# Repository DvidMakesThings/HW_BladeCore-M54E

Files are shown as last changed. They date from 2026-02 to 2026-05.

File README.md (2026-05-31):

# BladeCore‑M54E

BladeCore‑M54E is part of the **BladeCore** modular controller series.  
Each BladeCore variant is implemented as a standalone hardware repository, sharing a common architectural philosophy while targeting different microcontrollers and interfaces.

This repository documents the **BladeCore‑M54E** hardware, which is based on the **RP2354B** microcontroller and integrates **Ethernet connectivity**.

## BladeCore Series Overview

The BladeCore series consists of the following hardware variants:

| Module | Microcontroller | Primary Interface | Form Factor | Status |
|---|---|---|---|---|
| [BladeCore‑M40](#)  | RP2040  | — | - | Work in progress |
| [BladeCore‑M40E](#) | RP2040  | Ethernet | - | Work in progress |
| [BladeCore‑M40C](#) | RP2040  | CAN | - | Work in progress |
| [BladeCore‑M54](#)  | RP2354B | — | - | Work in progress |
| [BladeCore‑M54E](https://github.com/DvidMakesThings/HW_BladeCore-M54E) | RP2354B | Ethernet | 2980 | Available |
| [BladeCore‑M54C](https://github.com/DvidMakesThings/HW_BladeCore-M54C) | RP2354B | CAN | 2980 | Available |

### Naming Scheme Explanation

The BladeCore naming scheme encodes the **microcontroller family** and **primary communication interface** directly in the module name:

- **M40** designates an RP2040‑based module  
- **M54** designates an RP2354B‑based module  
- **E** suffix indicates integrated Ethernet support  
- **C** suffix indicates integrated CAN support  

Variants without a suffix represent the **base module** for that microcontroller family, without Ethernet or CAN integrated.

Each BladeCore variant is implemented as a **separate hardware design and repository**.

## Description

BladeCore‑M54E is a compact controller module built around the **RP2354B** microcontroller, combined with a **W5500 Ethernet controller with integrated PHY**.  
The module is designed as a **2980‑size M.2 M‑Key card** (29 mm wide, 80 mm long, non‑standard width), intended to be embedded into a carrier board or system that provides power through the M.2 edge connector.

The design integrates:

*   RP2354B microcontroller
*   External QSPI flash memory
*   External I²C EEPROM
*   100BASE Ethernet via W5500
*   Dual‑path USB connectivity with automatic source selection
*   Onboard power regulation and defined power‑up sequencing

This repository contains the schematics and documentation.

- [BladeCore‑M54 schematics (PDF)](src/PDF/BladeCore-M54E_Schematics.pdf).
- [BladeCore‑M54 KiCad folder](src/HardwareDesign/1.0.0/).

### Resources

- **KiCad Libraries:** [src/HardwareDesign/Libraries/KiCad](src/HardwareDesign/Libraries/KiCad)
    - BladeCore‑M54E footprint 
    - BladeCore‑M54E symbol
    - Plain M.2 connector footprint (MDT420E03001)
    - 3D STEP: BladeCore‑M54E + MDT420E03001 assembly
    - 3D STEP: M.2 connector
- **Eagle Libraries:** [src/HardwareDesign/Libraries/Eagle](src/HardwareDesign/Libraries/Eagle)
    - Status: Work in progress

## Hardware Overview

<table>
    <tr>
        <td align="center">
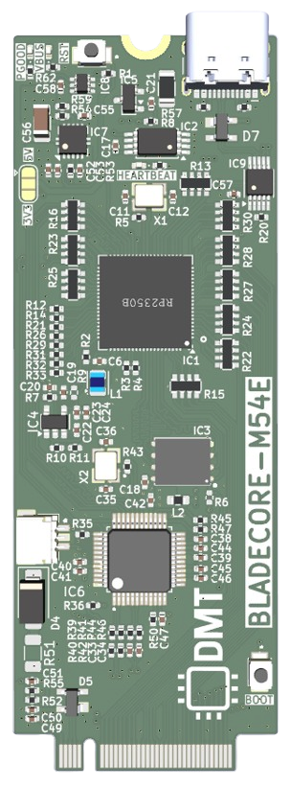
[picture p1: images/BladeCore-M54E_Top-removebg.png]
BladeCore‑M54E top view
            <br><em>Top view</em>
        </td>
        <td align="center">
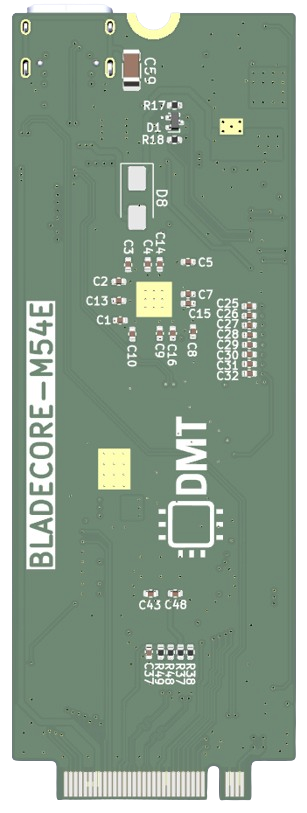
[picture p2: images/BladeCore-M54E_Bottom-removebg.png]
BladeCore‑M54E bottom view
            <br><em>Bottom view</em>
        </td>
    </tr>
 </table>

### Form Factor

*   **M.2 2980**
*   **M‑Key**
*   Power and I/O routed through the M.2 edge connector

### Microcontroller

*   **RP2354B**
*   External **12 MHz crystal**
*   Internal 1.1 V core supply generated by the MCU
*   SWD debug interface available
*   GPIOs routed to the M.2 edge connector

### Memory

*   **Integrated Flash**
    *   RP2354B
    *   Capacity: **2 MB**
*   **External QSPI Flash**
    *   W25Q128JVPIQ
    *   Capacity: **16 MB**
*   **External I²C EEPROM**
    *   AT24C256
    *   Capacity: **256 kbit**

***

### Ethernet

*   **W5500 Ethernet Controller with integrated PHY**
*   Interface to MCU via **SPI**
*   Supports **100BASE‑TX**
*   Dedicated reset and interrupt signals
*   Link and activity LEDs implemented

### USB

BladeCore‑M54E supports **two physical USB connection paths**:

1.  **USB routed through the M.2 edge connector** (external host or carrier board USB), and
2.  **Onboard USB‑C connector**.

A **FSUSB42 USB 2.0 high‑speed multiplexer** is used to select which USB path is connected to the RP2354B.

**USB path selection behavior:**

*   By default, the USB data lines are routed to the **M.2 edge connector**.
*   When the **onboard USB‑C connector is plugged in**, the FSUSB42 automatically **redirects the USB data path** from the edge connector to the onboard USB‑C connector.
*   Removing the onboard USB connection restores the default routing to the M.2 edge connector.

This allows the module to be normally operated via a carrier board USB connection, while still enabling direct access through the onboard USB‑C connector when needed, without manual configuration.

### Power

*   Input supply: **5 V** (M.2 pins 14/16 or VBUS) or **3.3 V** (M.2 pins 10/12, LDO bypassed)
*   **TPS74801** low‑dropout regulator generating 3.3 V from 5 V input
*   Regulated 3.3 V output to carrier board on M.2 pins 10/12 (up to 1 A, limited by connector)
*   Power‑good signaling with visual feedback (LED via SN74LVC1G97 buffer)
*   USB VBUS sensing routed to ADC
*   Four power paths: M.2 5 V, M.2 VBUS, onboard USB‑C, or external 3.3 V

### M.2 Connector Pinout

#### Left Side (Odd Pins)

| Pin | Name | F0 | F1 | F2 | F3 | F4 | F5 | F6 | F7 | F8 | F9 |
|----:|---|----|----|----|----|----|----|----|----|----|----|
| 1 | GND | | | | | | | | | | |
| 3 | GPIO24 | SPI0 TX | UART1 RTS | I2C1 SCL | PWM3 B | SIO | PIO0 | PIO1 | PIO2 | | CLOCK GPOUT1 |
| 5 | GPIO23 | SPI0 TX | UART1 RTS | I2C1 SCL | PWM3 B | SIO | PIO0 | PIO1 | PIO2 | | CLOCK GPOUT1 |
| 7 | GPIO22 | SPI0 SCK | UART1 CTS | I2C1 SDA | PWM3 A | SIO | PIO0 | PIO1 | PIO2 | | CLOCK GPIN1 |
| 9 | GPIO21 | SPI0 CSn | UART1 RX | **I2C0 SCL | PWM2 B | SIO | PIO0 | PIO1 | PIO2 | | CLOCK GPOUT0 |
| 11 | GND | | | | | | | | | | |
| 13 | GPIO20 | SPI0 RX | UART1 TX | **I2C0 SDA | PWM2 A | SIO | PIO0 | PIO1 | PIO2 | | CLOCK GPIN0 |
| 15 | GPIO19 | SPI0 TX | UART0 RTS | I2C1 SCL | PWM1 B | SIO | PIO0 | PIO1 | PIO2 | | QMI CS1n |
| 17 | GPIO18 | SPI0 SCK | UART0 CTS | I2C1 SDA | PWM1 A | SIO | PIO0 | PIO1 | PIO2 | | |
| 19 | GPIO17 | SPI0 CSn | UART0 RX | **I2C0 SCL | PWM0 B | SIO | PIO0 | PIO1 | PIO2 | | |
| 21 | GPIO16 | SPI0 RX | UART0 TX | **I2C0 SDA | PWM0 A | SIO | PIO0 | PIO1 | PIO2 | | |
| 23 | GND | | | | | | | | | | |
| 25 | GPIO15 | *SPI1 TX | UART0 RTS | I2C1 SCL | PWM7 B | SIO | PIO0 | PIO1 | PIO2 | | CLOCK GPOUT1 |
| 27 | GPIO14 | *SPI1 SCK | UART0 CTS | I2C1 SDA | PWM7 A | SIO | PIO0 | PIO1 | PIO2 | | CLOCK GPIN1 |
| 29 | GPIO13 | *SPI1 CSn | UART0 RX | **I2C0 SCL | PWM6 B | SIO | PIO0 | PIO1 | PIO2 | | CLOCK GPOUT0 |
| 31 | GPIO12 | *SPI1 RX | UART0 TX | **I2C0 SDA | PWM6 A | SIO | PIO0 | PIO1 | PIO2 | | CLOCK GPIN0 |
| 33 | GPIO11 | *SPI1 TX | UART1 RTS | I2C1 SCL | PWM5 B | SIO | PIO0 | PIO1 | PIO2 | | |
| 35 | GPIO10 | *SPI1 SCK | UART1 CTS | I2C1 SDA | PWM5 A | SIO | PIO0 | PIO1 | PIO2 | | |
| 37 | GPIO9 | *SPI1 CSn | UART1 RX | **I2C0 SCL | PWM4 B | SIO | PIO0 | PIO1 | PIO2 | | |
| 39 | GPIO8 | *SPI1 RX | UART1 TX | **I2C0 SDA | PWM4 A | SIO | PIO0 | PIO1 | PIO2 | | QMI CS1n |
| 41 | GND | | | | | | | | | | |
| 43 | GPIO7 | SPI0 TX | UART1 RTS | I2C1 SCL | PWM3 B | SIO | PIO0 | PIO1 | PIO2 | | |
| 45 | GPIO6 | SPI0 SCK | UART1 CTS | I2C1 SDA | PWM3 A | SIO | PIO0 | PIO1 | PIO2 | | |
| 47 | GPIO5 | SPI0 CSn | UART1 RX | **I2C0 SCL | PWM2 B | SIO | PIO0 | PIO1 | PIO2 | | |
| 49 | GPIO4 | SPI0 RX | UART1 TX | **I2C0 SDA | PWM2 A | SIO | PIO0 | PIO1 | PIO2 | | |
| 51 | GPIO3 | SPI0 TX | UART0 RTS | I2C1 SCL | PWM1 B | SIO | PIO0 | PIO1 | PIO2 | | |
| 53 | GPIO2 | SPI0 SCK | UART0 CTS | I2C1 SDA | PWM1 A | SIO | PIO0 | PIO1 | PIO2 | | |
| 55 | GPIO1 | SPI0 CSn | UART0 RX | **I2C0 SCL | PWM0 B | SIO | PIO0 | PIO1 | PIO2 | | TRACECLK |
| 57 | GPIO0 | SPI0 RX | UART0 TX | **I2C0 SDA | PWM0 A | SIO | PIO0 | PIO1 | PIO2 | | QMI CS1n |
| 67 | GND | | | | | | | | | | |
| 69 | USB_D+ | | | | | | | | | | |
| 71 | USB_D- | | | | | | | | | | |
| 73 | GND | | | | | | | | | | |
| 75 | VBUS | | | | | | | | | | |

#### Right Side (Even Pins)

| Pin | Name | F0 | F1 | F2 | F3 | F4 | F5 | F6 | F7 | F8 | F9 |
|----:|---|----|----|----|----|----|----|----|----|----|----|
| 2 | GND | | | | | | | | | | |
| 4 | GPIO27 | *SPI1 TX | UART1 RTS | I2C1 SCL | PWM5 B | SIO | PIO0 | PIO1 | PIO2 | | |
| 6 | GPIO26 | *SPI1 SCK | UART1 CTS | I2C1 SDA | PWM5 A | SIO | PIO0 | PIO1 | PIO2 | | |
| 8 | GPIO25 | *SPI1 CSn | UART1 RX | **I2C0 SCL | PWM4 B | SIO | PIO0 | PIO1 | PIO2 | | CLOCK GPOUT3 |
| 10 | +3.3V OUTPUT | | | | | | | | | | |
| 12 | +3.3V OUTPUT | | | | | | | | | | |
| 14 | +5V INPUT | | | | | | | | | | |
| 16 | +5V INPUT | | | | | | | | | | |
| 18 | LINKLED | | | | | | | | | | |
| 20 | ACTLED | | | | | | | | | | |
| 22 | GND | | | | | | | | | | |
| 24 | RCT | | | | | | | | | | |
| 26 | GND | | | | | | | | | | |
| 28 | ETH_RD+ | | | | | | | | | | |
| 30 | ETH_RD- | | | | | | | | | | |
| 32 | GND | | | | | | | | | | |
| 34 | ETH_TD+ | | | | | | | | | | |
| 36 | ETH_TD- | | | | | | | | | | |
| 38 | GND | | | | | | | | | | |
| 40 | TCT | | | | | | | | | | |
| 42 | GND | | | | | | | | | | |
| 44 | GND | | | | | | | | | | |
| 46 | ADC0/GPIO40 |  | *SPI1 RX | UART1 TX | **I2C0 SDA | PWM8 A | SIO | PIO0 | PIO1 | PIO2 |  |
| 48 | ADC1/GPIO41 |  | *SPI1 CSn | UART1 RX | **I2C0 SCL | PWM8 B | SIO | PIO0 | PIO1 | PIO2 |  |
| 50 | ADC2/GPIO42 |  | *SPI1 SCK | UART1 CTS | I2C1 SDA | PWM9 A | SIO | PIO0 | PIO1 | PIO2 |  |
| 52 | ADC3/GPIO43 |  | *SPI1 TX | UART1 RTS | I2C1 SCL | PWM9 B | SIO | PIO0 | PIO1 | PIO2 |  |
| 54 | ADC4/GPIO44 |  | *SPI1 RX | UART0 TX | **I2C0 SDA | PWM10 A | SIO | PIO0 | PIO1 | PIO2 |  |
| 56 | ADC5/GPIO45 |  | *SPI1 CSn | UART0 RX | **I2C0 SCL | PWM10 B | SIO | PIO0 | PIO1 | PIO2 |  |
| 58 | GND | | | | | | | | | | |
| 68 | GND | | | | | | | | | | |
| 70 | GND | | | | | | | | | | |
| 72 | VBUS | | | | | | | | | | |
| 74 | VBUS | | | | | | | | | | |
| SH1 | SHIELD | | | | | | | | | | |

*SPI1 is used for the onboard Ethernet controller (W5500)

**I2C0 is used for the onboard EEPROM (AT24C256) on GPIO32/33, which are internal to the module and not routed to the M.2 connector. Carrier board I2C0 on other GPIO pairs is physically independent.

## Revision History

| Revision | Date | Notes |
| --- | --- | --- |
| 1.0.0 | 2026‑01‑31 | Initial creation |

## Notes

*   This documentation intentionally avoids assumptions about firmware features, supported protocols, or software behavior.
*   All statements are derived from the provided schematics and explicit design notes.
*   Component‑level limits and behavior should be verified against the respective datasheets.

## License
### Hardware Components
Hardware designs, schematics, and related documentation are licensed under the **Creative Commons Attribution-NonCommercial-ShareAlike 4.0 International License (CC BY-NC-SA 4.0)**. See the [Hardware License](LICENSE-CC-BY-NC-SA) file for details.

#### What CC BY-NC-SA 4.0 means:

- ✅ **You can** study, modify, and distribute the hardware designs
- ✅ **You can** create derivative works for personal, educational, or non-commercial use
- ✅ **You can** build this project for your own personal use

- ⚠️ **You must** give appropriate credit and indicate if changes were made
- ⚠️ **You must** share any modifications under the same license terms
- ⚠️ **You must** include the original license and copyright notices

- ❌ **You cannot** use the designs for commercial purposes without explicit permission
- ❌ **You cannot** manufacture and sell products based on these designs without a commercial license
- ❌ **You cannot** create closed-source derivatives for commercial purposes
- ❌ **You cannot** use the designer's trademarks without permission

### Commercial & Enterprise Use

Commercial use of this project is prohibited without obtaining a separate commercial license. If you are interested in:

- Manufacturing and selling products based on these designs
- Incorporating these designs into commercial products
- Any other commercial applications

Please contact me through any of the channels listed in the [Contact](#contact) section to discuss commercial licensing arrangements. Commercial licenses are available with reasonable terms to support ongoing development.

## Contact

For questions or feedback:
- **Email:** [info@dmt-hw.com](mailto:info@dmt-hw.com)
- **GitHub:** [DvidMakesThings](https://github.com/DvidMakesThings)

## Contributing

Contributions are welcome! As this is an early-stage project, please reach out before 
making substantial changes:

1. Fork the repository
2. Create a feature branch (`git checkout -b feature/concept`)
3. Commit your changes (`git commit -m 'Add concept'`)
4. Push to the branch (`git push origin feature/concept`)
5. Open a Pull Request with a detailed description

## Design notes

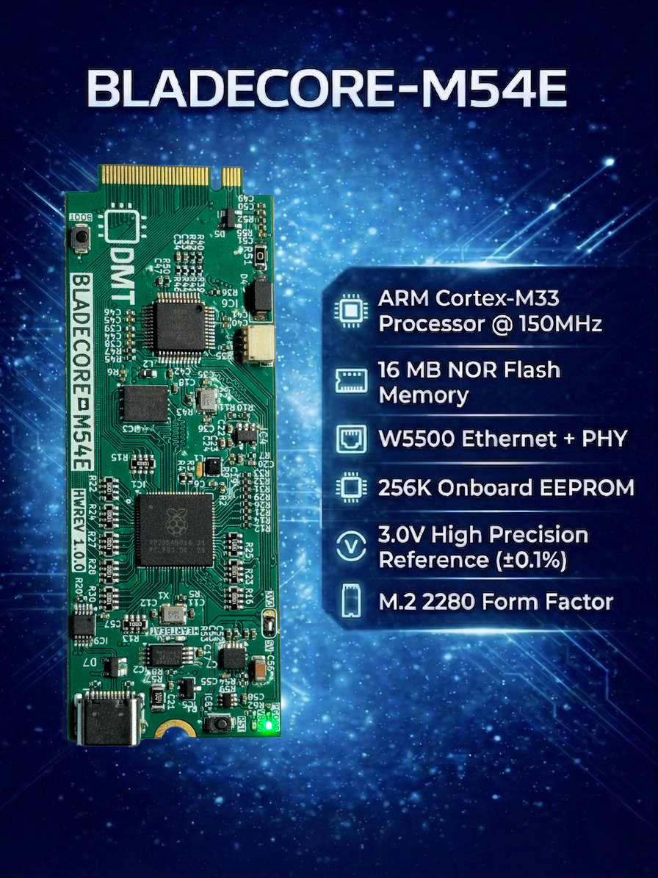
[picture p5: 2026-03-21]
images/M54E.png

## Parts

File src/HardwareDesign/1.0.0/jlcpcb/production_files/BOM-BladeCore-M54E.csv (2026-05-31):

Comment | Designator | Footprint | LCSC | Quantity
0R 1% | R40,R42 | R_0402_1005Metric | C17168 | 2
0R 1% | R51 | R_1206_3216Metric | C17888 | 1
1.5K/100MHz 0.5R | L2 | R_0603_1608Metric | C82155 | 1
100R 1% | R13,R15,R16,R22,R23,R24,R25,R27,R28,R30 | R_Array_Convex_4x0603 | C136838 | 10
100R 1% | R12,R14,R21,R26,R29,R31,R32,R33 | R_0402_1005Metric | C25076 | 8
100nF 50V | C1,C10,C13,C14,C15,C17,C18,C19,C2,C21,C23,C3,C37,C38,C4,C40,C41,C42,C43,C44,C45,C46,C47,C48,C5,C51,C52,C57,C58,C60,C7,C8,C9 | C_0402_1005Metric | C307331 | 33
10K 1% | R10,R11,R53 | R_0402_1005Metric | C25744 | 3
10pF 50V | C11,C12 | C_0402_1005Metric | C466222 | 2
10uF 50V | C56 | C_1206_3216Metric | C13585 | 1
12.4K 1% | R50 | R_0402_1005Metric | C490814 | 1
12MHz 10pF | X1 | X3225 | C2901649 | 1
15pF 50V | C35,C36 | C_0402_1005Metric | C1548 | 2
1K 1% | R34,R5,R58,R60,R61 | R_0402_1005Metric | C11702 | 5
1M 1% | R57 | R_1206_3216Metric | C17927 | 1
1M 1% | R43 | R_0402_1005Metric | C26083 | 1
1nF 2kV | C59 | C_1206_3216Metric | C173242 | 1
1nF 50V | C25,C26,C27,C28,C29,C30,C31,C32 | C_0402_1005Metric | C14442 | 8
1uF 50V | C53 | C_0402_1005Metric | C1518208 | 1
2.2K 1% | R17,R18 | R_0402_1005Metric | C25879 | 2
2.2nF 50V | C55 | C_0402_1005Metric | C106861 | 1
2.4K 1% | R59 | R_0402_1005Metric | C25882 | 1
25MHz 12pF | X2 | X3225 | C9006 | 1
27R 1% | R7 | R_0402_1005Metric | C138021 | 1
3.3R 1% | R39,R41,R44,R46 | R_0402_1005Metric | C270612 | 4
3.3uH 2.8A | L1 | 0805 | C42411119 | 1
33R 1% | R2,R3,R4 | R_0402_1005Metric | C25105 | 3
4.7K 1% | R1,R35,R8 | R_0402_1005Metric | C25900 | 3
4.7uF 10V | C20,C22,C24 | C_0402_1005Metric | C368809 | 3
4.7uF 25V | C16,C39,C49,C50,C54,C6 | C_0402_1005Metric | C22367824 | 6
470R 1% | R36,R45,R47 | R_0402_1005Metric | C25117 | 3
49.9R 1% | R37,R38,R48,R49 | R_0402_1005Metric | C25120 | 4
5.1K 1% | R19,R20,R52,R55,R56 | R_0402_1005Metric | C25905 | 5
6.8nF 50V | C33,C34 | C_0402_1005Metric | C1542 | 2
7.5K 1% | R54 | R_0402_1005Metric | C25918 | 1
AT24C256C-XHL-T | IC2 | TSSOP-8 | C33035 | 1
B3U-1000P | SW1,SW2 | SW_B3U-1000P | C231329 | 2
Blue | D3 | LED_0402_1005Metric | C22355736 | 1
FSUSB42MUX | IC9 | MSOP-10_3x3mm_P0.5mm | C11355 | 1
Green | D10,D11,D6 | LED_0402_1005Metric | C965793 | 3
LM4040B30FTA | IC5 | SOT-23 | C460604 | 1
MCP6001RT | IC4 | SOT-23-5 | C154973 | 1
RCLAMP0582BQTCT | D1 | SOT-416 | C841193 | 1
RP2354B | IC1 | QFN80_10x10 | C39843328 | 1
SM03B-SRSS-TB | J2 | JST_SM03B-SRSS-TB_LF__SN_ | C160403 | 1
SN74LVC1G97QDCKRQ1 | IC10,IC8 | SOT-363_SC-70-6 | C179911 | 2
SP0503BAHTG | D5,D7 | SOT143 | C3040626 | 2
TPS74801DRCT | IC7 | VSON-10-1EP_3x3mm_P0.5mm_EP1.65x2.4mm_ThermalVias | C882845 | 1
USB-TYPE-C-018 | J3 | USB_C_Receptacle_HCTL_HC-TYPE-C-16P-01A | C2927038 | 1
W25Q128JVPIQ | IC3 | WSON8_6x5 | C190862 | 1
W5500 | IC6 | LQFP48_7x7 | C32843 | 1
SS13 | D4 | D_SMA |  | 1
SS13 | D9 | D_SMA |  | 1
SS13 | D8 | D_SMA |  | 1

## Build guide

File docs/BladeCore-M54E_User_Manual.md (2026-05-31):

---
title: "BladeCore-M54E User Manual"
---

**Hardware Revision:** 1.0.0
**Date:** 2026-01-31
**Author:** DMT

## Table of Contents

1. [Introduction](#1-introduction)
2. [General Specifications](#2-general-specifications)
3. [Electrical Characteristics](#3-electrical-characteristics)
4. [Microcontroller](#4-microcontroller)
5. [Memory Subsystem](#5-memory-subsystem)
6. [Ethernet Interface](#6-ethernet-interface)
7. [USB Interface](#7-usb-interface)
8. [Power Management](#8-power-management)
9. [M.2 Connector Pinout](#9-m2-connector-pinout)
10. [Onboard Peripherals](#10-onboard-peripherals)
11. [Power-Up Sequencing](#11-power-up-sequencing)
12. [Getting Started -- Software](#12-getting-started----software)
13. [Programming Guide](#13-programming-guide)
14. [Code Examples](#14-code-examples)
15. [Design Considerations for Carrier Boards](#15-design-considerations-for-carrier-boards)
16. [Mechanical Specifications](#16-mechanical-specifications)
17. [Absolute Maximum Ratings](#17-absolute-maximum-ratings)
18. [Revision History](#18-revision-history)

## 1. Introduction

BladeCore-M54E is a compact, modular microcontroller card built around the **RP2354B**
(ARM Cortex-M33, dual-core) combined with a **W5500 Ethernet controller** with
integrated PHY.  The module uses an **M.2 2980 M-Key** form factor (29 mm wide,
80 mm long) with a standard M-Key edge connector at a non-standard board width,
making it suitable for embedding into carrier boards or systems that provide power
and I/O connectivity through the M.2 edge connector.

### Key Features

- RP2354B dual-core ARM Cortex-M33 microcontroller
- 2 MB integrated flash + 16 MB external QSPI flash
- 256 kbit external I2C EEPROM with 200+ year data retention
- 100BASE-TX Ethernet via W5500 (SPI-attached, hardware TCP/IP stack)
- Dual-path USB 2.0 with automatic source selection (M.2 + USB-C)
- 30 GPIO pins + 6 ADC channels routed to M.2 edge connector
- Onboard 3.3 V LDO with power-good signaling
- Defined power-up sequencing
- Onboard heartbeat LED (PWM-capable)
- SWD debug interface

### BladeCore Series

BladeCore-M54E belongs to the BladeCore modular controller series:

| Module | MCU | Primary Interface | 
|---|---|---|
| BladeCore-M40  | RP2040  | -- |
| BladeCore-M40E | RP2040  | Ethernet | 
| BladeCore-M40C | RP2040  | CAN |
| BladeCore-M54  | RP2354B | -- | 
| BladeCore-M54E | RP2354B | Ethernet | 
| BladeCore-M54C | RP2354B | CAN |

**Naming convention:** M40 = RP2040-based, M54 = RP2354B-based. Suffix E = Ethernet,
C = CAN, no suffix = base module.

## 2. General Specifications

| Parameter | Value |
|---|---|
| Microcontroller | RP2354B (ARM Cortex-M33, dual core) |
| Package | QFN-80-EP (10 x 10 mm) |
| System Clock | 150 MHz, overclock possible (Tested max is 200MHz) |
| External Crystal | 12 MHz, 10 pF load |
| Integrated Flash | 2 MB (internal to MCU) |
| External Flash (QSPI) | 16 MB (W25Q128JVPIQ, 133 MHz) |
| External EEPROM (I2C) | 256 kbit (AT24C256C, 400 kHz) |
| Ethernet | 100BASE-TX, W5500 (SPI, hardware TCP/IP) |
| USB | USB 2.0, dual path (M.2 + USB-C) |
| GPIO (M.2 connector) | 28 digital I/O pins |
| ADC Channels (M.2) | 6 channels (12-bit, GPIO40--GPIO45) |
| Onboard ADC Channels | 2 (VBUS sense, 3.0 V reference) |
| Operating Voltage (I/O) | 3.3 V |
| Form Factor | M.2 2980 M-Key |
| PCB Layers | 6 |

## 3. Electrical Characteristics

### 3.1 Recommended Operating Conditions

| Parameter | Symbol | Min | Typical | Max | Unit |
|---|---|---|---|---|---|
| Supply Voltage (5 V in)  | VIN | 4.75  | 5.0 | 5.5 | V |
| Supply Voltage (3.3 V) | VCC | 3.0 | 3.3 | 3.6 | V |
| USB VBUS Voltage | VBUS | 4.75  | 5.0 | 5.25  | V |
| Operating Temperature | TA | -20 | 25 | 70 | degC |
| I/O Logic Level (High) | VIH | 2.0 | -- | 3.3 | V |
| I/O Logic Level (Low) | VIL | 0 | -- | 0.8 | V |

### 3.2 RP2354B Core Parameters

| Parameter | Value |
|---|---|
| Core Voltage | 1.1 V (internal) |
| GPIO Output Drive | 2 / 4 / 8 / 12 mA  |
| GPIO Input Hysteresis | Schmitt trigger |
| Internal Pull-Up/Down Resistance | 50--80 kOhm |
| ADC Resolution | 12 bits |
| ADC Reference Voltage | 3.3 V (AVDD) |

### 3.3 Power Consumption (Typical)

| Condition | Current (3.3 V) | Notes |
|---|---|---|
| MCU idle, Ethernet off | ~15 mA | RP2354B in normal idle |
| MCU active, Ethernet off | ~40 mA | Both cores running |
| MCU active, Ethernet active | ~180 mA | W5500 in full operation |
| MCU dormant (sleep) | <1 mA | Deep sleep, all peripherals off |

> **Note:** The above values are approximate. Actual consumption depends on clock
> frequency, active peripherals, GPIO loading, and Ethernet traffic. Consult the
> RP2354B and W5500 datasheets for detailed characterization.

### 3.4 LDO Regulator (TPS74801)

| Parameter | Symbol | Min  | Typical | Max  | Unit |
|---|---|---|---|---|---|
| Input Voltage | VIN | 1.1  | 5.0 | 5.5  | V |
| Output Voltage | VOUT | -- | 3.3 | -- | V |
| Max Output Current | IOUT | -- | -- | 1.5  | A |
| Dropout Voltage | VDO | -- | 110 | 300  | mV |
| Output Voltage Accuracy| -- | -- | +/-1 | -- | % |
| Thermal Shutdown | -- | -- | 160 | -- | degC |

### 3.5 Voltage Reference (LM4040B30FTA)

| Parameter | Value |
|---|---|
| Reference Voltage | 3.000 V |
| Tolerance | +/-0.1% |
| Package | SOT-23 |
| Connected To | ADC7 (GPIO47) via 10K-10K divider |

## 4. Microcontroller

### 4.1 RP2354B Overview

The RP2354B is a dual-core ARM Cortex-M33 microcontroller from Raspberry Pi Ltd.
It features hardware floating-point, DSP extensions, and the RP2-series PIO
(Programmable I/O) state machines.

| Feature | Specification |
|---|---|
| Architecture | ARM Cortex-M33 (ARMv8-M) |
| Cores | 2 |
| Max Clock Speed | 150 MHz |
| FPU | Single-precision hardware FPU |
| DSP | Yes (ARMv8-M DSP extension) |
| PIO State Machines | 3 PIO blocks (PIO0, PIO1, PIO2) |
| DMA Channels | 16 |
| Timers | 2 hardware timers |
| PWM Channels | 24 (12 slices x 2 channels) |
| UART | 2 |
| SPI | 2 |
| I2C | 2 |
| USB | 1 (USB 1.1 Host/Device) |
| ADC | 12-bit SAR, 8 channels (+ temp) |
| Internal Flash | 2 MB |
| SRAM | 520 KB |
| Debug | SWD (Serial Wire Debug) |
| Package | QFN-80-EP (10 x 10 mm) |

### 4.2 Clock Configuration

- **External Crystal:** 12 MHz (X3225 footprint), 10 pF load capacitance
- **System PLL:** Configurable up to 150 MHz system clock
- **USB PLL:** 48 MHz (required for USB operation)

### 4.3 GPIO Allocation on BladeCore-M54E

| GPIO Range  | Count | Assignment |
|---|---|---|
| GPIO0--27 | 28 | Routed to M.2 edge connector (user I/O)  |
| GPIO28--31  | 4 | W5500 Ethernet SPI1 (MISO, CS, SCK, MOSI)|
| GPIO32--33  | 2 | I2C0 -- EEPROM (SDA, SCL) |
| GPIO34 | 1 | W5500 hardware reset |
| GPIO35 | 1 | W5500 interrupt (active low) |
| GPIO36 | 1 | Onboard heartbeat LED (blue, PWM) |
| GPIO37--39  | 3 | **Not connected** (do not use) |
| GPIO40--45  | 6 | Routed to M.2 as ADC0--ADC5 |
| GPIO46 | 1 | Onboard ADC6 -- USB VBUS sense |
| GPIO47 | 1 | Onboard ADC7 -- 3.0 V reference monitor |

**Total GPIO available on M.2 connector: 34** (28 digital + 6 ADC-capable)

> **Warning:** GPIO37, GPIO38, and GPIO39 are NOT connected on BladeCore-M54E.
> Attempting to use these pins will have no effect. The firmware header CONFIG.h
> includes compile-time guards to catch accidental use.

## 5. Memory Subsystem

### 5.1 Integrated Flash

- Built into the RP2354B
- Capacity: 2 MB
- Used for program storage and execution (XIP -- execute in place)

### 5.2 External QSPI Flash (W25Q128JVPIQ)

| Parameter | Value |
|---|---|
| Part Number | W25Q128JVPIQ (Winbond) |
| Capacity | 16 MB (128 Mbit) |
| Interface | Quad SPI (QSPI) |
| Max Clock | 133 MHz |
| Package | 8-WSON (6 x 5 mm) |
| Erase Granularity | 4 KB sector / 32 KB block / 64 KB block |
| Write Granularity | 256 bytes (page program) |
| Endurance | 100,000 erase cycles per sector  |

The external flash is connected to the RP2354B's dedicated QSPI interface and can be
used for additional program storage, file systems (e.g., LittleFS), or data logging.

### 5.3 External EEPROM (AT24C256C)

| Parameter | Value |
|---|---|
| Part Number | AT24C256C-XHL-T (Microchip) |
| Capacity | 256 kbit (32,768 x 8 bytes) |
| Interface | I2C (shared with I2C0) |
| I2C Address | 0x50 (A0 = A1 = GND) |
| Max Clock | 400 kHz (Fast mode) |
| Write Page Size | 64 bytes |
| Write Cycle Time | 5 ms (max) |
| Endurance | 1,000,000 write cycles |
| Data Retention | 200+ years |
| Package | 8-TSSOP |
| Pull-Up Resistors | 4.7 kOhm on SDA and SCL |

The EEPROM is connected to I2C0 on GPIO32/33, which are internal to the module and
not routed to the M.2 connector. When I2C0 is used on a different pin pair via the
M.2 edge connector, it operates on a physically separate bus - address 0x50 is fully
available on the carrier board side. The EEPROM is ideal for storing configuration
data, calibration values, serial numbers, or small persistent datasets.

## 6. Ethernet Interface

### 6.1 W5500 Overview

| Parameter | Value |
|---|---|
| Part Number | W5500 (WIZnet) |
| Standard | IEEE 802.3 100BASE-TX |
| PHY | Integrated |
| Hardware TCP/IP | Yes (8 simultaneous sockets) |
| Internal Buffer | 32 KB (TX + RX, configurable) |
| Interface to MCU | SPI (up to 80 MHz) |
| Package | LQFP-48 (7 x 7 mm) |
| Operating Temp | -40 degC to +85 degC |

The W5500 offloads the complete TCP/IP stack from the MCU.  Supported protocols
include TCP, UDP, IPv4, ICMP, ARP, IGMP, and PPPoE at the hardware level.

### 6.2 SPI Connection to MCU

| Signal | GPIO | M.2 Pin | Direction (MCU view) |
|---|---|---|---|
| MISO | GPIO28 | 46 * | Input |
| CS | GPIO29 | 41 * | Output |
| SCK | GPIO30 | 40 * | Output |
| MOSI | GPIO31 | 39 * | Output |

*These GPIO are used internally and are NOT available on the M.2 connector for
user applications.*

| Control  | GPIO | Function |
|---|---|---|
| RST | GPIO34 | Hardware reset (active low) |
| INT | GPIO35 | Interrupt output (active low) |

**SPI Configuration:**
- SPI Instance: SPI1
- Baudrate: 10 MHz (default in CONFIG.h)
- Mode: SPI Mode 0 (CPOL=0, CPHA=0)

### 6.3 Ethernet Signals on M.2 Connector

| M.2 Pin | Signal | Description |
|---|---|---|
| 18 | LINKLED  | Ethernet link indicator |
| 20 | ACTLED | Ethernet activity indicator |
| 24 | RCT | Center tap, receive transformer |
| 28 | ETH_RD+  | Receive differential pair (+) |
| 30 | ETH_RD-  | Receive differential pair (-) |
| 34 | ETH_TD+  | Transmit differential pair (+) |
| 36 | ETH_TD-  | Transmit differential pair (-) |
| 40 | TCT | Center tap, transmit transformer  |

The carrier board must provide Ethernet magnetics (transformers) and an RJ45 connector.
The LINKLED and ACTLED pins can drive indicator LEDs on the carrier board (active low).

### 6.4 Reference Crystal

- Frequency: 25 MHz
- Load Capacitance: 12 pF
- Package: X3225

## 7. USB Interface

### 7.1 Dual-Path Architecture

BladeCore-M54E provides two physical USB connection paths:

1. **M.2 edge connector USB** -- for connection through the carrier board
2. **Onboard USB-C connector** -- for direct access during development or provisioning

A **FSUSB42MUX** (OnSemi) USB 2.0 multiplexer automatically selects the active path:

| Condition | Active USB Path |
|---|---|
| No USB-C cable connected | M.2 edge connector |
| USB-C cable connected | Onboard USB-C |

This selection is automatic -- no firmware intervention or manual jumper configuration
is required.

### 7.2 M.2 USB Signals

| M.2 Pin | Signal | Description |
|---|---|---|
| 69 | USB_D+ | USB Data + |
| 71 | USB_D- | USB Data - |
| 72, 74  | VBUS | USB VBUS (5V) |
| 75 | VBUS | USB VBUS (5V) |

### 7.3 USB-C Connector

- Type: USB-TYPE-C-018 receptacle
- Supports plugging/unplugging during operation (hot-swap)
- CC resistors onboard for proper USB-C enumeration
- ESD protection: SP0503BAHTG on data lines

### 7.4 USB VBUS Sensing

The USB VBUS voltage is monitored via GPIO46 (ADC6) through a resistive voltage divider:

- Divider: 5.1 kOhm / 5.1 kOhm
- ADC input voltage at 5.0 V VBUS: ~2.5 V
- Formula: VBUS = ADC_reading * (3.0 / 4096) * 2

This allows firmware to detect whether USB power is present and measure the
actual VBUS voltage.

## 8. Power Management

### 8.1 Power Input Options

BladeCore-M54E can be powered through four paths:

| Source | Input Pins | Path |
|---|---|---|
| M.2 5 V | Pins 14, 16 (+5V INPUT) | 5 V -> TPS74801 LDO -> 3.3 V rail |
| M.2 VBUS | Pins 72, 74, 75 (VBUS) | VBUS -> TPS74801 LDO -> 3.3 V rail |
| Onboard USB-C | USB-C connector | VBUS -> TPS74801 LDO -> 3.3 V rail |
| External 3.3 V | Pins 10, 12 (+3.3V OUTPUT) | Direct to 3.3 V rail (LDO bypassed) |

### 8.2 3.3 V Output to Carrier Board

When the module is powered from 5 V (pins 14/16, VBUS, or USB-C), the regulated
3.3 V rail is provided back to the carrier board on M.2 pins 10 and 12
(+3.3V OUTPUT).  The LDO can supply **1.5 A** total.  Each M.2 contact is rated
for 0.5 A, so with two pins the connector limits the carrier board output to
**1 A**.  The remaining 0.5 A is the module's own budget, of which ~180 mA is
typically consumed (with Ethernet active).

When the module is powered externally at 3.3 V on these same pins, the carrier
board supplies both the module and itself -- the LDO is not active in this mode.

### 8.3 Voltage Regulator -- TPS74801DRCT

| Parameter | Value |
|---|---|
| Type | Low-Dropout (LDO) |
| Output Voltage | 3.3 V |
| Max Output Current | 1.5 A |
| Dropout Voltage | 110 mV typical |
| Package | VSON-10-1EP (3x3 mm) |
| Enable Pin | VEN (active high) |
| Power-Good Output | PGOOD (open drain) |

### 8.4 Power-Good Indication

The LDO provides a PGOOD signal that goes high once the output voltage reaches
regulation. This signal is buffered through an **SN74LVC1G97QDCKRQ1** logic gate
before driving an onboard green LED (visual indicator).

### 8.5 Onboard Voltage Reference

A precision **LM4040B30FTA** (3.000 V, +/-0.1%) voltage reference is connected
to GPIO47 (ADC7) through a 10K / 10K voltage divider. This enables:
- ADC calibration at runtime (known reference voltage)
- Detection of supply rail drift
- High-accuracy analog measurements

**To calibrate the ADC:**
```
Expected ADC reading for 3.0V reference through 10K/10K divider:
  VADC = 3.0 / 2 = 1.5 V
  Expected ADC code = 1.5 / 3.0 * 4096 = ~2048

  Calibration factor = 2048 / actual_adc_reading
  Apply this factor to all subsequent ADC readings.
```

## 9. M.2 Connector Pinout

### 9.1 Left Side (Odd Pins)

| Pin | Signal  | GPIO | Alternate Functions |
|-----|---|---|---|
| 1 | GND | -- | Ground |
| 3 | GPIO24  | GPIO24 | SPI0 TX, UART1 RTS, I2C1 SCL, PWM3 B, PIO0/1/2 |
| 5 | GPIO23  | GPIO23 | SPI0 TX, UART1 RTS, I2C1 SCL, PWM3 B, PIO0/1/2 |
| 7 | GPIO22  | GPIO22 | SPI0 SCK, UART1 CTS, I2C1 SDA, PWM3 A, PIO0/1/2 |
| 9 | GPIO21  | GPIO21 | SPI0 CSn, UART1 RX, I2C0 SCL, PWM2 B, PIO0/1/2 |
| 11  | GND | -- | Ground |
| 13  | GPIO20  | GPIO20 | SPI0 RX, UART1 TX, I2C0 SDA, PWM2 A, PIO0/1/2 |
| 15  | GPIO19  | GPIO19 | SPI0 TX, UART0 RTS, I2C1 SCL, PWM1 B, QMI CS1n |
| 17  | GPIO18  | GPIO18 | SPI0 SCK, UART0 CTS, I2C1 SDA, PWM1 A, PIO0/1/2 |
| 19  | GPIO17  | GPIO17 | SPI0 CSn, UART0 RX, I2C0 SCL, PWM0 B, PIO0/1/2 |
| 21  | GPIO16  | GPIO16 | SPI0 RX, UART0 TX, I2C0 SDA, PWM0 A, PIO0/1/2 |
| 23  | GND | -- | Ground |
| 25  | GPIO15  | GPIO15 | SPI1 TX, UART0 RTS, I2C1 SCL, PWM7 B, PIO0/1/2 |
| 27  | GPIO14  | GPIO14 | SPI1 SCK, UART0 CTS, I2C1 SDA, PWM7 A, PIO0/1/2 |
| 29  | GPIO13  | GPIO13 | SPI1 CSn, UART0 RX, I2C0 SCL, PWM6 B, PIO0/1/2 |
| 31  | GPIO12  | GPIO12 | SPI1 RX, UART0 TX, I2C0 SDA, PWM6 A, PIO0/1/2 |
| 33  | GPIO11  | GPIO11 | SPI1 TX, UART1 RTS, I2C1 SCL, PWM5 B, PIO0/1/2 |
| 35  | GPIO10  | GPIO10 | SPI1 SCK, UART1 CTS, I2C1 SDA, PWM5 A, PIO0/1/2 |
| 37  | GPIO9 | GPIO9  | SPI1 CSn, UART1 RX, I2C0 SCL, PWM4 B, PIO0/1/2 |
| 39  | GPIO8 | GPIO8  | SPI1 RX, UART1 TX, I2C0 SDA, PWM4 A, QMI CS1n |
| 41  | GND | -- | Ground |
| 43  | GPIO7 | GPIO7  | SPI0 TX, UART1 RTS, I2C1 SCL, PWM3 B, PIO0/1/2 |
| 45  | GPIO6 | GPIO6  | SPI0 SCK, UART1 CTS, I2C1 SDA, PWM3 A, PIO0/1/2 |
| 47  | GPIO5 | GPIO5  | SPI0 CSn, UART1 RX, I2C0 SCL, PWM2 B, PIO0/1/2 |
| 49  | GPIO4 | GPIO4  | SPI0 RX, UART1 TX, I2C0 SDA, PWM2 A, PIO0/1/2 |
| 51  | GPIO3 | GPIO3  | SPI0 TX, UART0 RTS, I2C1 SCL, PWM1 B, PIO0/1/2 |
| 53  | GPIO2 | GPIO2  | SPI0 SCK, UART0 CTS, I2C1 SDA, PWM1 A, PIO0/1/2 |
| 55  | GPIO1 | GPIO1  | SPI0 CSn, UART0 RX, I2C0 SCL, PWM0 B, TRACECLK |
| 57  | GPIO0 | GPIO0  | SPI0 RX, UART0 TX, I2C0 SDA, PWM0 A, QMI CS1n |
| 67  | GND | -- | Ground |
| 69  | USB_D+  | -- | USB Data Plus |
| 71  | USB_D-  | -- | USB Data Minus |
| 73  | GND | -- | Ground |
| 75  | VBUS | -- | USB VBUS (5 V) |

### 9.2 Right Side (Even Pins)

| Pin | Signal | GPIO | Notes |
|-----|---|---|---|
| 2 | GND | -- | Ground |
| 4 | GPIO27 | GPIO27 | SPI1 TX, UART1 RTS, I2C1 SCL, PWM5 B |
| 6 | GPIO26 | GPIO26 | SPI1 SCK, UART1 CTS, I2C1 SDA, PWM5 A |
| 8 | GPIO25 | GPIO25 | SPI1 CSn, UART1 RX, I2C0 SCL, PWM4 B |
| 10  | +3.3V OUTPUT| -- | 3.3 V LDO output / external 3.3 V input |
| 12  | +3.3V OUTPUT| -- | 3.3 V LDO output / external 3.3 V input |
| 14  | +5V INPUT | -- | 5 V power input to module |
| 16  | +5V INPUT | -- | 5 V power input to module |
| 18  | LINKLED | -- | Ethernet link indicator (active low) |
| 20  | ACTLED | -- | Ethernet activity indicator (active low) |
| 22  | GND | -- | Ground |
| 24  | RCT | -- | Receive center tap (Ethernet magnetics) |
| 26  | GND | -- | Ground |
| 28  | ETH_RD+ | -- | Ethernet receive differential (+) |
| 30  | ETH_RD- | -- | Ethernet receive differential (-) |
| 32  | GND | -- | Ground |
| 34  | ETH_TD+ | -- | Ethernet transmit differential (+) |
| 36  | ETH_TD- | -- | Ethernet transmit differential (-) |
| 38  | GND | -- | Ground |
| 40  | TCT | -- | Transmit center tap (Ethernet magnetics) |
| 42  | GND | -- | Ground |
| 44  | GND | -- | Ground |
| 46  | ADC0/GPIO40 | GPIO40 | Analog/digital, PWM8 A, SPI1, UART1, I2C0 |
| 48  | ADC1/GPIO41 | GPIO41 | Analog/digital, PWM8 B, SPI1, UART1, I2C0 |
| 50  | ADC2/GPIO42 | GPIO42 | Analog/digital, PWM9 A, SPI1, UART1, I2C1 |
| 52  | ADC3/GPIO43 | GPIO43 | Analog/digital, PWM9 B, SPI1, UART1, I2C1 |
| 54  | ADC4/GPIO44 | GPIO44 | Analog/digital, PWM10 A, SPI1, UART0, I2C0 |
| 56  | ADC5/GPIO45 | GPIO45 | Analog/digital, PWM10 B, SPI1, UART0, I2C0 |
| 58  | GND | -- | Ground |
| 68  | GND | -- | Ground |
| 70  | GND | -- | Ground |
| 72  | VBUS | -- | USB VBUS (5 V) |
| 74  | VBUS | -- | USB VBUS (5 V) |
| SH1 | SHIELD | -- | Shield / Ground |

### 9.3 Important Notes

- **SPI1** (GPIO8--15, GPIO25--31, GPIO40--45) overlaps with both user-accessible
  pins and the onboard W5500.  GPIO28--31 are dedicated to the W5500 and are
  **not** available on the M.2 connector.  User code must avoid configuring
  GPIO28--31 for other purposes.
- **I2C0** can be used on any M.2-accessible GPIO with an I2C0 alternate function.
  The onboard EEPROM uses GPIO32--33, which are not wired to the M.2 connector,
  so the carrier board's I2C0 bus is physically independent.
- **GPIO37, GPIO38, GPIO39** are not connected.  Do not assign any function to these
  pins in firmware.

## 10. Onboard Peripherals

### 10.1 Heartbeat LED

| Parameter | Value |
|---|---|
| GPIO | GPIO36 |
| Color | Blue |
| Package | 0402 (1005 Metric) |
| Series Resistor| 1000 Ohm |
| PWM Slice | Slice 2, Channel A |
| PWM Frequency | 1000 Hz (configurable) |

The heartbeat LED is intended as a visual "alive" indicator.  It can be driven
with simple digital on/off or with hardware PWM for breathing/fading effects.

### 10.2 Reset Buttons

Two tactile switches (B3U-1000P, Omron) are provided on the board for manual
reset and boot-mode selection.

### 10.3 Status LEDs

| LED | Color | Designator | Function |
|---|---|---|---|
| +5V | Green | D10 | Connected to REGIN; active when VBUS or +5V is present |
| PGOOD | Green | D6 | Driven via SN74LVC1G97 buffer; active when 3.3V is OK |
| VBUS | Green | D11 | SN74LVC1G97 as 2-input OR gate; monitors onboard + M.2 VBUS |
| Heartbeat | Blue  | D3 | Connected to MCU GPIO36; PWM breathing indicator |

### 10.4 ESD Protection

| Device | Protection |
|---|---|
| SP0503BAHTG | USB data line ESD clamping |
| RCLAMP0582BQTCT| General I/O ESD clamping |

## 11. Power-Up Sequencing

The board follows a defined power-up sequence with the following timeline:

| Step | Event | Time (cumulative) |
|---|---|---|
| 1 | VIN applied (5.0 V) | 0 ms |
| 2 | VEN asserted (TPS74801 enables) | 0 ms |
| 3 | VOUT (3.3 V) reaches regulation | ~4 ms (soft-start) |
| 4 | PGOOD asserts (power-good valid) | ~4 ms |
| 5 | RP2354B 3.3 V rail stable | ~4 ms |
| 6 | RP2354B 1.1 V core valid (POR) | ~4.01 ms |
| 7 | RP2354B ready for execution | ~4.09 ms |
| 8 | W5500 fully initialized | ~54 ms |

> **Note:** The W5500 requires approximately 50 ms after power stabilization for
> its internal PLL to lock and the PHY to initialize.  Firmware should wait at
> least 50 ms after asserting the W5500 reset pin before attempting SPI
> communication.

## 12. Getting Started -- Software

### 12.1 Prerequisites

- **Raspberry Pi Pico SDK** version 2.2.0 or later
- **ARM GCC Toolchain** version 14.2 or later
- **CMake** version 3.13 or later
- **Picotool** version 2.2.0 or later (for UF2 flashing)
- A USB cable (USB-C or via carrier board M.2 connection)

### 12.2 Environment Setup (Windows)

1. Install the [Raspberry Pi Pico VS Code Extension](https://marketplace.visualstudio.com/items?itemName=raspberry-pi.raspberry-pi-pico)
   which automatically installs and manages the SDK, toolchain, and picotool.

2. Alternatively, install manually:
   ```
   # Install Pico SDK
   git clone https://github.com/raspberrypi/pico-sdk.git
   cd pico-sdk
   git checkout 2.2.0
   git submodule update --init

   # Set environment variable
   set PICO_SDK_PATH=C:\path\to\pico-sdk
   ```

### 12.3 Building the Heartbeat Example

```
cd src/Software/Heartbeat

mkdir build
cd build

cmake -G "Ninja" ..
ninja
```

This produces `Heartbeat.uf2` in the build directory.

### 12.4 Flashing Firmware

1. Hold the BOOTSEL button on the RP2354B while connecting USB (or pressing reset).
2. The board enumerates as a USB mass storage device (RP2350 drive).
3. Copy the `.uf2` file to the drive:
   ```
   copy Heartbeat.uf2 E:\
   ```
   (Replace `E:\` with the actual drive letter.)
4. The board automatically reboots and begins executing.

Alternatively, use picotool:
```
picotool load Heartbeat.uf2
picotool reboot
```

### 12.5 Serial Monitor (USB CDC)

The Heartbeat example enables USB stdio output. Connect a terminal at any baud
rate (USB CDC is rate-independent):

```
# Using PuTTY, Tera Term, or any serial monitor
# Select the COM port assigned to the Pico
```

## 13. Programming Guide

### 13.1 Pin Configuration Header

All pin assignments are centralized in `CONFIG.h`.  Always use these definitions
instead of hardcoding GPIO numbers:

```c
#include "CONFIG.h"

// Ethernet SPI
PIN_ETH_MISO    // GPIO28 - SPI1 RX
PIN_ETH_CS      // GPIO29 - SPI1 CSn
PIN_ETH_SCK     // GPIO30 - SPI1 SCK
PIN_ETH_MOSI    // GPIO31 - SPI1 TX

// I2C EEPROM
PIN_I2C0_SDA    // GPIO32
PIN_I2C0_SCL    // GPIO33

// Ethernet control
PIN_ETH_RST     // GPIO34 - W5500 reset (active low)
PIN_ETH_INT     // GPIO35 - W5500 interrupt (active low)

// Heartbeat LED
PIN_HEARTBEAT   // GPIO36

// ADC
PIN_ADC_VUSB    // GPIO46 / ADC6 - USB VBUS sense
PIN_ADC_VREF    // GPIO47 / ADC7 - Voltage reference
```

### 13.2 SPI1 -- Ethernet (W5500)

```c
#include "hardware/spi.h"
#include "CONFIG.h"

void w5500_spi_init(void) {
    spi_init(ETH_SPI_INSTANCE, ETH_SPI_BAUDRATE);

    gpio_set_function(PIN_ETH_MISO, GPIO_FUNC_SPI);
    gpio_set_function(PIN_ETH_MOSI, GPIO_FUNC_SPI);
    gpio_set_function(PIN_ETH_SCK, GPIO_FUNC_SPI);

    // CS is managed manually (active low)
    gpio_init(PIN_ETH_CS);
    gpio_set_dir(PIN_ETH_CS, GPIO_OUT);
    gpio_put(PIN_ETH_CS, 1);  // Deselect

    // Reset pin
    gpio_init(PIN_ETH_RST);
    gpio_set_dir(PIN_ETH_RST, GPIO_OUT);
    gpio_put(PIN_ETH_RST, 1);  // Not in reset

    // Interrupt pin
    gpio_init(PIN_ETH_INT);
    gpio_set_dir(PIN_ETH_INT, GPIO_IN);
    gpio_pull_up(PIN_ETH_INT);
}

void w5500_reset(void) {
    gpio_put(PIN_ETH_RST, 0);
    sleep_ms(1);          // Hold reset for at least 500 us
    gpio_put(PIN_ETH_RST, 1);
    sleep_ms(50);         // Wait for W5500 PLL lock + PHY init
}

// Basic SPI read/write for W5500 register access
void w5500_write(uint16_t addr, uint8_t block, uint8_t *data, uint16_t len) {
    uint8_t header[3];
    header[0] = (uint8_t)(addr >> 8);
    header[1] = (uint8_t)(addr & 0xFF);
    header[2] = (block << 3) | (1 << 2);  // Write mode

    gpio_put(PIN_ETH_CS, 0);
    spi_write_blocking(ETH_SPI_INSTANCE, header, 3);
    spi_write_blocking(ETH_SPI_INSTANCE, data, len);
    gpio_put(PIN_ETH_CS, 1);
}

void w5500_read(uint16_t addr, uint8_t block, uint8_t *data, uint16_t len) {
    uint8_t header[3];
    header[0] = (uint8_t)(addr >> 8);
    header[1] = (uint8_t)(addr & 0xFF);
    header[2] = (block << 3) | (0 << 2);  // Read mode

    gpio_put(PIN_ETH_CS, 0);
    spi_write_blocking(ETH_SPI_INSTANCE, header, 3);
    spi_read_blocking(ETH_SPI_INSTANCE, 0x00, data, len);
    gpio_put(PIN_ETH_CS, 1);
}
```

### 13.3 I2C0 -- EEPROM (AT24C256)

```c
#include "hardware/i2c.h"
#include "CONFIG.h"

void eeprom_init(void) {
    i2c_init(EEPROM_I2C_INSTANCE, EEPROM_I2C_BAUDRATE);
    gpio_set_function(PIN_I2C0_SDA, GPIO_FUNC_I2C);
    gpio_set_function(PIN_I2C0_SCL, GPIO_FUNC_I2C);
    // External 4.7K pull-ups are on the board -- no internal pull-ups needed
}

// Write up to 64 bytes (one EEPROM page) at a time
int eeprom_write(uint16_t mem_addr, const uint8_t *data, size_t len) {
    uint8_t buf[66];  // 2 address bytes + 64 data bytes max
    buf[0] = (uint8_t)(mem_addr >> 8);
    buf[1] = (uint8_t)(mem_addr & 0xFF);

    if (len > 64) len = 64;
    for (size_t i = 0; i < len; i++) {
        buf[2 + i] = data[i];
    }

    int ret = i2c_write_blocking(EEPROM_I2C_INSTANCE, EEPROM_I2C_ADDR,
                                  buf, 2 + len, false);
    sleep_ms(5);  // Wait for write cycle to complete
    return ret;
}

// Read arbitrary number of bytes
int eeprom_read(uint16_t mem_addr, uint8_t *data, size_t len) {
    uint8_t addr_buf[2];
    addr_buf[0] = (uint8_t)(mem_addr >> 8);
    addr_buf[1] = (uint8_t)(mem_addr & 0xFF);

    int ret = i2c_write_blocking(EEPROM_I2C_INSTANCE, EEPROM_I2C_ADDR,
                                  addr_buf, 2, true);  // No stop
    if (ret < 0) return ret;

    return i2c_read_blocking(EEPROM_I2C_INSTANCE, EEPROM_I2C_ADDR,
                              data, len, false);
}
```

### 13.4 ADC -- Voltage Monitoring

```c
#include "hardware/adc.h"
#include "CONFIG.h"

void adc_monitoring_init(void) {
    adc_init();
    adc_gpio_init(PIN_ADC_VUSB);  // GPIO46 / ADC6
    adc_gpio_init(PIN_ADC_VREF);  // GPIO47 / ADC7
}

// Read USB VBUS voltage (5V nominal)
float read_vbus_voltage(void) {
    adc_select_input(6);  // ADC6 = GPIO46
    adc_read();           // Throwaway sample after channel switch
    uint16_t raw = adc_read();
    // 5.1K / 5.1K divider, factor = 2
    return (float)raw * 3.0f / 4096.0f * 2.0f;
}

// Read precision voltage reference (3.0V nominal)
float read_vref(void) {
    adc_select_input(7);  // ADC7 = GPIO47
    adc_read();           // Throwaway sample after channel switch
    uint16_t raw = adc_read();
    // 10K / 10K divider, factor = 2
    return (float)raw * 3.0f / 4096.0f * 2.0f;
}

// Calculate ADC calibration factor using known reference
float get_adc_calibration_factor(void) {
    adc_select_input(7);
    adc_read();           // Throwaway sample after channel switch
    uint16_t raw = adc_read();
    float measured = (float)raw * 3.0f / 4096.0f * 2.0f;
    return 3.0f / measured;  // Ratio of known vs measured
}
```

### 13.5 PWM -- Heartbeat LED

```c
#include "hardware/pwm.h"
#include "hardware/clocks.h"
#include "CONFIG.h"

#define PWM_WRAP 65535

void heartbeat_init(void) {
    gpio_set_function(PIN_HEARTBEAT, GPIO_FUNC_PWM);

    uint slice = pwm_gpio_to_slice_num(PIN_HEARTBEAT);
    pwm_config cfg = pwm_get_default_config();

    float divider = (float)clock_get_hz(clk_sys) /
                    ((float)HEARTBEAT_PWM_FREQ_HZ * (PWM_WRAP + 1));
    if (divider < 1.0f) divider = 1.0f;

    pwm_config_set_clkdiv(&cfg, divider);
    pwm_config_set_wrap(&cfg, PWM_WRAP);
    pwm_init(slice, &cfg, true);
    pwm_set_chan_level(slice, pwm_gpio_to_channel(PIN_HEARTBEAT), 0);
}

// Set LED brightness: 0 = off, 65535 = full
void heartbeat_set(uint16_t brightness) {
    uint slice = pwm_gpio_to_slice_num(PIN_HEARTBEAT);
    uint channel = pwm_gpio_to_channel(PIN_HEARTBEAT);
    pwm_set_chan_level(slice, channel, brightness);
}
```

### 13.6 UART (via M.2 Connector)

```c
#include "hardware/uart.h"

// Example: UART0 on GPIO0 (TX) and GPIO1 (RX) -- M.2 pins 57 and 55
void uart_example_init(void) {
    uart_init(uart0, 115200);
    gpio_set_function(0, GPIO_FUNC_UART);  // UART0 TX
    gpio_set_function(1, GPIO_FUNC_UART);  // UART0 RX
}
```

### 13.7 CMakeLists.txt Template

```cmake
cmake_minimum_required(VERSION 3.13)

set(CMAKE_C_STANDARD 11)
set(CMAKE_CXX_STANDARD 17)
set(CMAKE_EXPORT_COMPILE_COMMANDS ON)

# Pico SDK integration (VS Code extension auto-config)
if(WIN32)
    set(USERHOME $ENV{USERPROFILE})
else()
    set(USERHOME $ENV{HOME})
endif()
set(sdkVersion 2.2.0)
set(toolchainVersion 14_2_Rel1)
set(picotoolVersion 2.2.0-a4)
set(picoVscode ${USERHOME}/.pico-sdk/cmake/pico-vscode.cmake)
if (EXISTS ${picoVscode})
    include(${picoVscode})
endif()

set(PICO_BOARD pico2 CACHE STRING "Board type")

include(pico_sdk_import.cmake)

project(MyProject C CXX ASM)
pico_sdk_init()

add_executable(MyProject main.c)

pico_set_program_name(MyProject "MyProject")
pico_set_program_version(MyProject "0.1")

# Enable USB output, disable UART output
pico_enable_stdio_uart(MyProject 0)
pico_enable_stdio_usb(MyProject 1)

target_link_libraries(MyProject
    pico_stdlib
    hardware_spi       # For W5500 Ethernet
    hardware_i2c       # For EEPROM
    hardware_adc       # For ADC monitoring
    hardware_pwm       # For heartbeat LED
)

target_include_directories(MyProject PRIVATE
    ${CMAKE_CURRENT_LIST_DIR}
)

pico_add_extra_outputs(MyProject)
```

## 14. Code Examples

### 14.1 Heartbeat LED (Breathing Effect)

The included `Heartbeat.c` example demonstrates a smooth PWM breathing pattern on
the onboard blue LED.  See `src/Software/Heartbeat/` for the complete project.

**Behavior:** The LED linearly fades from off to full brightness and back over
approximately 2 seconds (128 steps x 2 directions x 8 ms per step).

### 14.2 Minimal W5500 Initialization

```c
#include <stdio.h>
#include "pico/stdlib.h"
#include "hardware/spi.h"
#include "CONFIG.h"

int main(void) {
    stdio_init_all();

    // Initialize SPI1 for W5500
    spi_init(ETH_SPI_INSTANCE, ETH_SPI_BAUDRATE);
    gpio_set_function(PIN_ETH_MISO, GPIO_FUNC_SPI);
    gpio_set_function(PIN_ETH_MOSI, GPIO_FUNC_SPI);
    gpio_set_function(PIN_ETH_SCK, GPIO_FUNC_SPI);

    gpio_init(PIN_ETH_CS);
    gpio_set_dir(PIN_ETH_CS, GPIO_OUT);
    gpio_put(PIN_ETH_CS, 1);

    // Hardware reset the W5500
    gpio_init(PIN_ETH_RST);
    gpio_set_dir(PIN_ETH_RST, GPIO_OUT);
    gpio_put(PIN_ETH_RST, 0);
    sleep_ms(1);
    gpio_put(PIN_ETH_RST, 1);
    sleep_ms(50);

    // Read W5500 version register (address 0x0039, common register block 0)
    uint8_t header[3] = {0x00, 0x39, 0x00};  // Read, common block
    uint8_t version = 0;

    gpio_put(PIN_ETH_CS, 0);
    spi_write_blocking(ETH_SPI_INSTANCE, header, 3);
    spi_read_blocking(ETH_SPI_INSTANCE, 0x00, &version, 1);
    gpio_put(PIN_ETH_CS, 1);

    printf("W5500 Version: 0x%02X (expected 0x04)\n", version);

    while (true) {
        tight_loop_contents();
    }
}
```

### 14.3 EEPROM Read/Write Test

```c
#include <stdio.h>
#include <string.h>
#include "pico/stdlib.h"
#include "hardware/i2c.h"
#include "CONFIG.h"

int main(void) {
    stdio_init_all();
    sleep_ms(2000);  // Wait for USB enumeration

    // Initialize I2C0
    i2c_init(EEPROM_I2C_INSTANCE, EEPROM_I2C_BAUDRATE);
    gpio_set_function(PIN_I2C0_SDA, GPIO_FUNC_I2C);
    gpio_set_function(PIN_I2C0_SCL, GPIO_FUNC_I2C);

    // Write test data to EEPROM address 0x0000
    uint8_t write_buf[] = {0x00, 0x00, 'H', 'e', 'l', 'l', 'o'};
    int ret = i2c_write_blocking(EEPROM_I2C_INSTANCE, EEPROM_I2C_ADDR,
                                  write_buf, sizeof(write_buf), false);
    printf("Write returned: %d\n", ret);
    sleep_ms(5);  // EEPROM write cycle

    // Read back
    uint8_t addr_buf[] = {0x00, 0x00};
    i2c_write_blocking(EEPROM_I2C_INSTANCE, EEPROM_I2C_ADDR,
                        addr_buf, 2, true);

    uint8_t read_buf[5] = {0};
    i2c_read_blocking(EEPROM_I2C_INSTANCE, EEPROM_I2C_ADDR,
                       read_buf, 5, false);

    printf("Read back: %c%c%c%c%c\n",
           read_buf[0], read_buf[1], read_buf[2],
           read_buf[3], read_buf[4]);

    while (true) {
        tight_loop_contents();
    }
}
```

### 14.4 ADC Calibration and VBUS Monitoring

```c
#include <stdio.h>
#include "pico/stdlib.h"
#include "hardware/adc.h"
#include "CONFIG.h"

int main(void) {
    stdio_init_all();
    sleep_ms(2000);

    adc_init();
    adc_gpio_init(PIN_ADC_VUSB);
    adc_gpio_init(PIN_ADC_VREF);

    // Calibrate using onboard 3.0V reference
    adc_select_input(7);  // ADC7 = GPIO47 (VREF)
    adc_read();           // Throwaway sample after channel switch
    uint16_t ref_raw = adc_read();
    float ref_measured = (float)ref_raw * 3.0f / 4096.0f * 2.0f;
    float cal_factor = 3.0f / ref_measured;

    printf("Reference ADC raw: %u\n", ref_raw);
    printf("Measured: %.3f V (expected 3.000 V)\n", ref_measured);
    printf("Calibration factor: %.4f\n", cal_factor);

    while (true) {
        // Read VBUS
        adc_select_input(6);  // ADC6 = GPIO46 (VUSB)
        adc_read();           // Throwaway sample after channel switch
        uint16_t vbus_raw = adc_read();
        float vbus = (float)vbus_raw * 3.0f / 4096.0f * 2.0f * cal_factor;

        printf("VBUS: %.2f V (raw: %u)\n", vbus, vbus_raw);
        sleep_ms(1000);
    }
}
```

## 15. Design Considerations for Carrier Boards

### 15.1 Ethernet Magnetics

The carrier board MUST provide Ethernet magnetics (1:1 isolation transformers) and
an RJ45 connector.  The differential pairs on the M.2 connector are:

- **TX:** Pins 34 (+) and 36 (-)
- **RX:** Pins 28 (+) and 30 (-)
- **Center taps:** Pins 24 (RCT) and 40 (TCT)

Route differential pairs with controlled impedance (100 Ohm differential) and
keep trace lengths matched within 50 mils.

### 15.2 Power Supply Design

- **5 V mode:** Provide stable 5 V on M.2 pins 14 and 16 (+5V INPUT).
  Minimum current capacity: 500 mA (to support MCU + W5500 + peripherals).
  Recommended: 1 A or more if the carrier board also draws from the 3.3 V output.
  M.2 pins 10 and 12 provide **3.3 V output** from the onboard LDO (up to 1 A
  available for carrier board electronics).
- **External 3.3 V mode:** Supply regulated 3.3 V on M.2 pins 10 and 12.
  The carrier board supplies all current (module draws ~180 mA
  typical with Ethernet active).
- Add bulk capacitance (47-100 uF) near the M.2 connector on the carrier board.

### 15.3 USB Routing

- Route USB_D+ (pin 69) and USB_D- (pin 71) as a 90 Ohm differential pair.
- Keep trace lengths matched.
- Provide VBUS on pins 72, 74, 75 if USB-powered operation is desired.

### 15.4 I2C Bus Extension

- I2C0 can be used on any M.2-accessible GPIO with the I2C0 alternate function.
  The onboard EEPROM (GPIO32--33) is not wired to the M.2 connector, so the
  carrier board operates on a physically separate I2C bus -- all addresses
  including 0x50 are available.
- Total bus capacitance should not exceed 400 pF for reliable 400 kHz operation.

### 15.5 SPI Bus Sharing

- SPI1 is occupied by the W5500 (GPIO28--31, directly on the module).
- SPI0 is fully available on the M.2 connector (multiple GPIO options).
- If using SPI1 on M.2 GPIO pins (GPIO8--15, GPIO25--27, GPIO40--45),
  make sure the W5500 CS (GPIO29) is deasserted (high) to avoid bus contention.

### 15.6 Antenna and EMI

- The Ethernet differential pairs carry high-frequency signals.  Route them on
  inner layers if possible, with solid ground planes above and below.
- Keep the Ethernet trace area away from high-speed digital signals (SPI clock,
  USB data lines).

## 16. Mechanical Specifications

| Parameter | Value |
|---|---|
| Form Factor | M.2 2980 M-Key |
| Card Dimensions | 29 mm x 80 mm |
| Thickness | ~1.6 mm (6-layer PCB) |
| Edge Connector | M-Key (75 pins) |
| Mating Connector | MDT420E03001 (or equiv) |
| Mounting | M2.5 threaded standoff  |
| Weight | < 10 g |

## 17. Absolute Maximum Ratings

Exceeding absolute maximum ratings may cause permanent damage to the module.

| Parameter | Rating |
|---|---|
| VIN (5 V input) | -0.3 to 6.0 V  |
| VCC (3.3 V rail) | -0.3 to 3.6 V  |
| GPIO voltage (any pin) | -0.3 to 3.63 V |
| Maximum GPIO source current  | 12 mA per pin |
| Maximum total GPIO current | 50 mA |
| Storage Temperature | -40 to +85 degC |
| Operating Temperature | -20 to +70 degC |
| ESD (HBM) | 2 kV |

> **Caution:** The RP2354B GPIOs are **NOT** 5 V tolerant.  All signal levels
> connected to the M.2 connector must be 3.3 V logic.  Use level shifters on
> the carrier board if interfacing with 5 V systems.

## 18. Revision History

| Revision | Date | Notes |
|---|---|---|
| 1.0.0 | 2026-01-31 | Initial creation |

*This document is derived from the BladeCore-M54E schematics (v1.0.0) and
associated design files. Component-level limits and behavior should be verified
against the respective datasheets. For the latest information, refer to the
project repository.*

*Hardware licensed under CC BY-NC-SA 4.0.*
*Contact: info@dmt-hw.com | GitHub: DvidMakesThings*

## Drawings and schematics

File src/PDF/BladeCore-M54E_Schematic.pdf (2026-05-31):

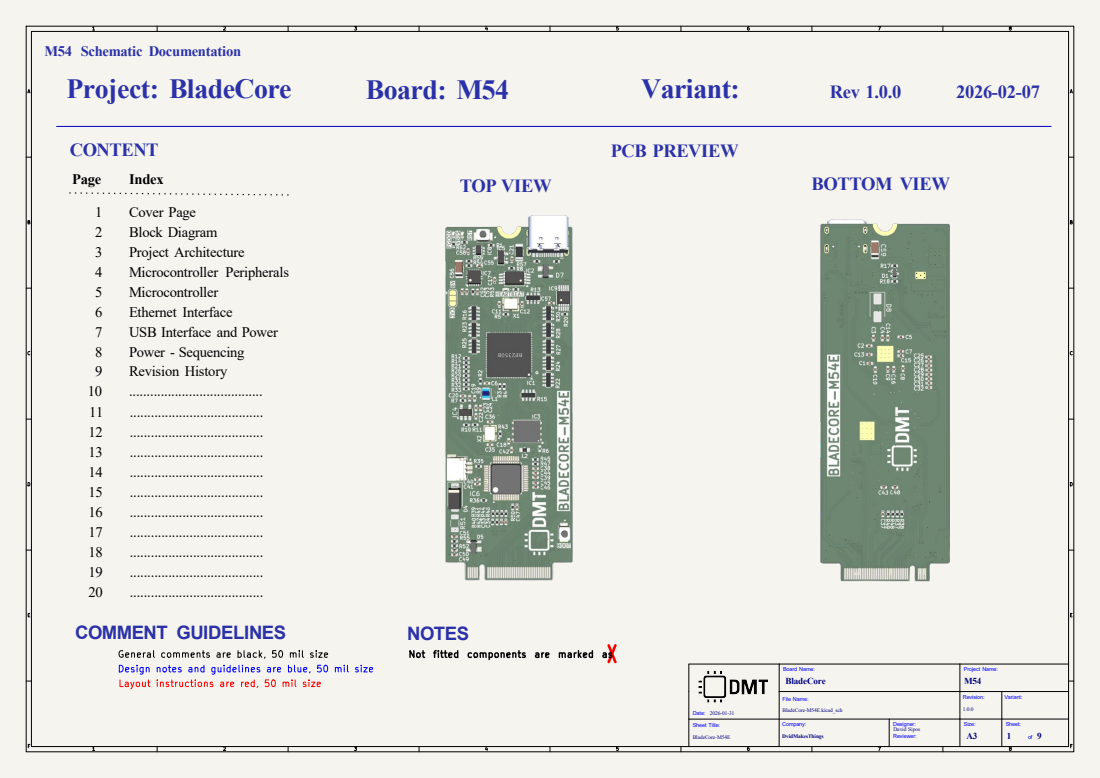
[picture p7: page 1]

File Name: Sheet Title: BladeCore-M54E M54 Schematic Documentation

General comments are black, 50 mil size
Design notes and guidelines are blue, 50 mil size
Layout instructions are red, 50 mil size

Not fitted components are marked as

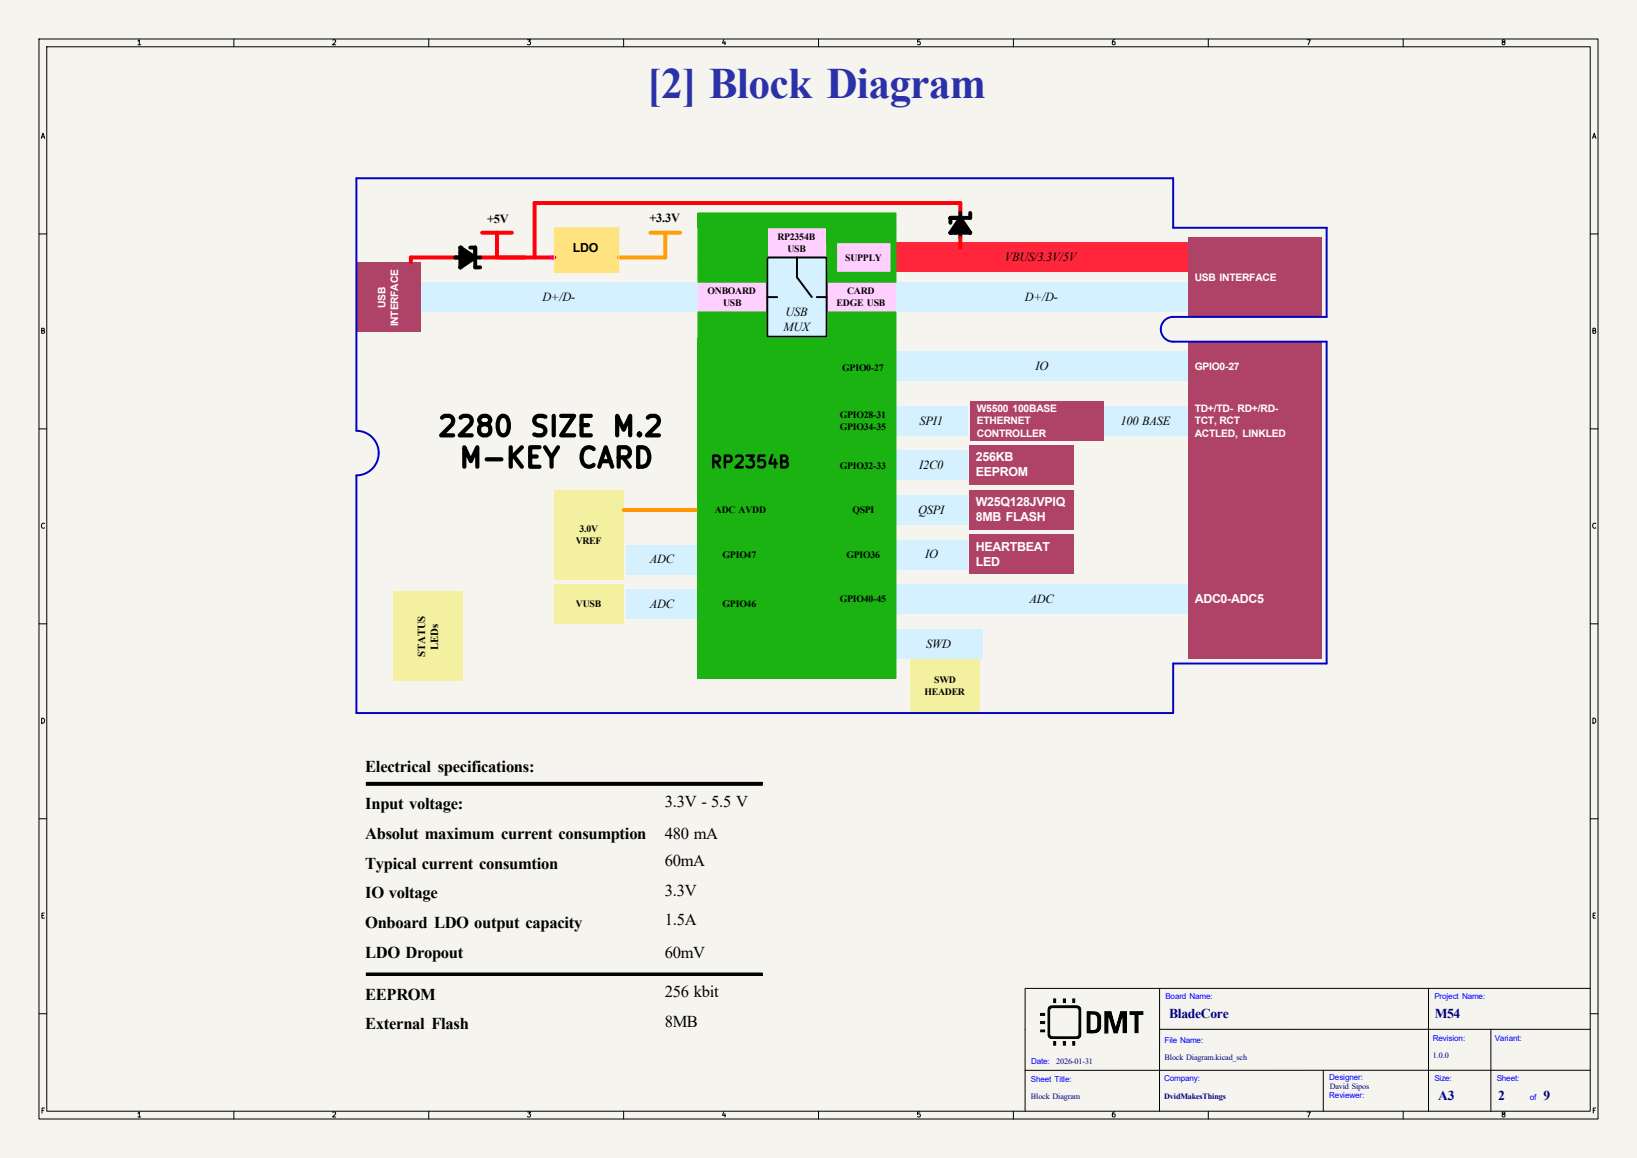
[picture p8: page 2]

TCT, RCT
ACTLED, LINKLED

Input voltage:
Absolut maximum current consumption
IO voltage
Onboard LDO output capacity
LDO Dropout

File Name: Sheet Title: Block Diagram

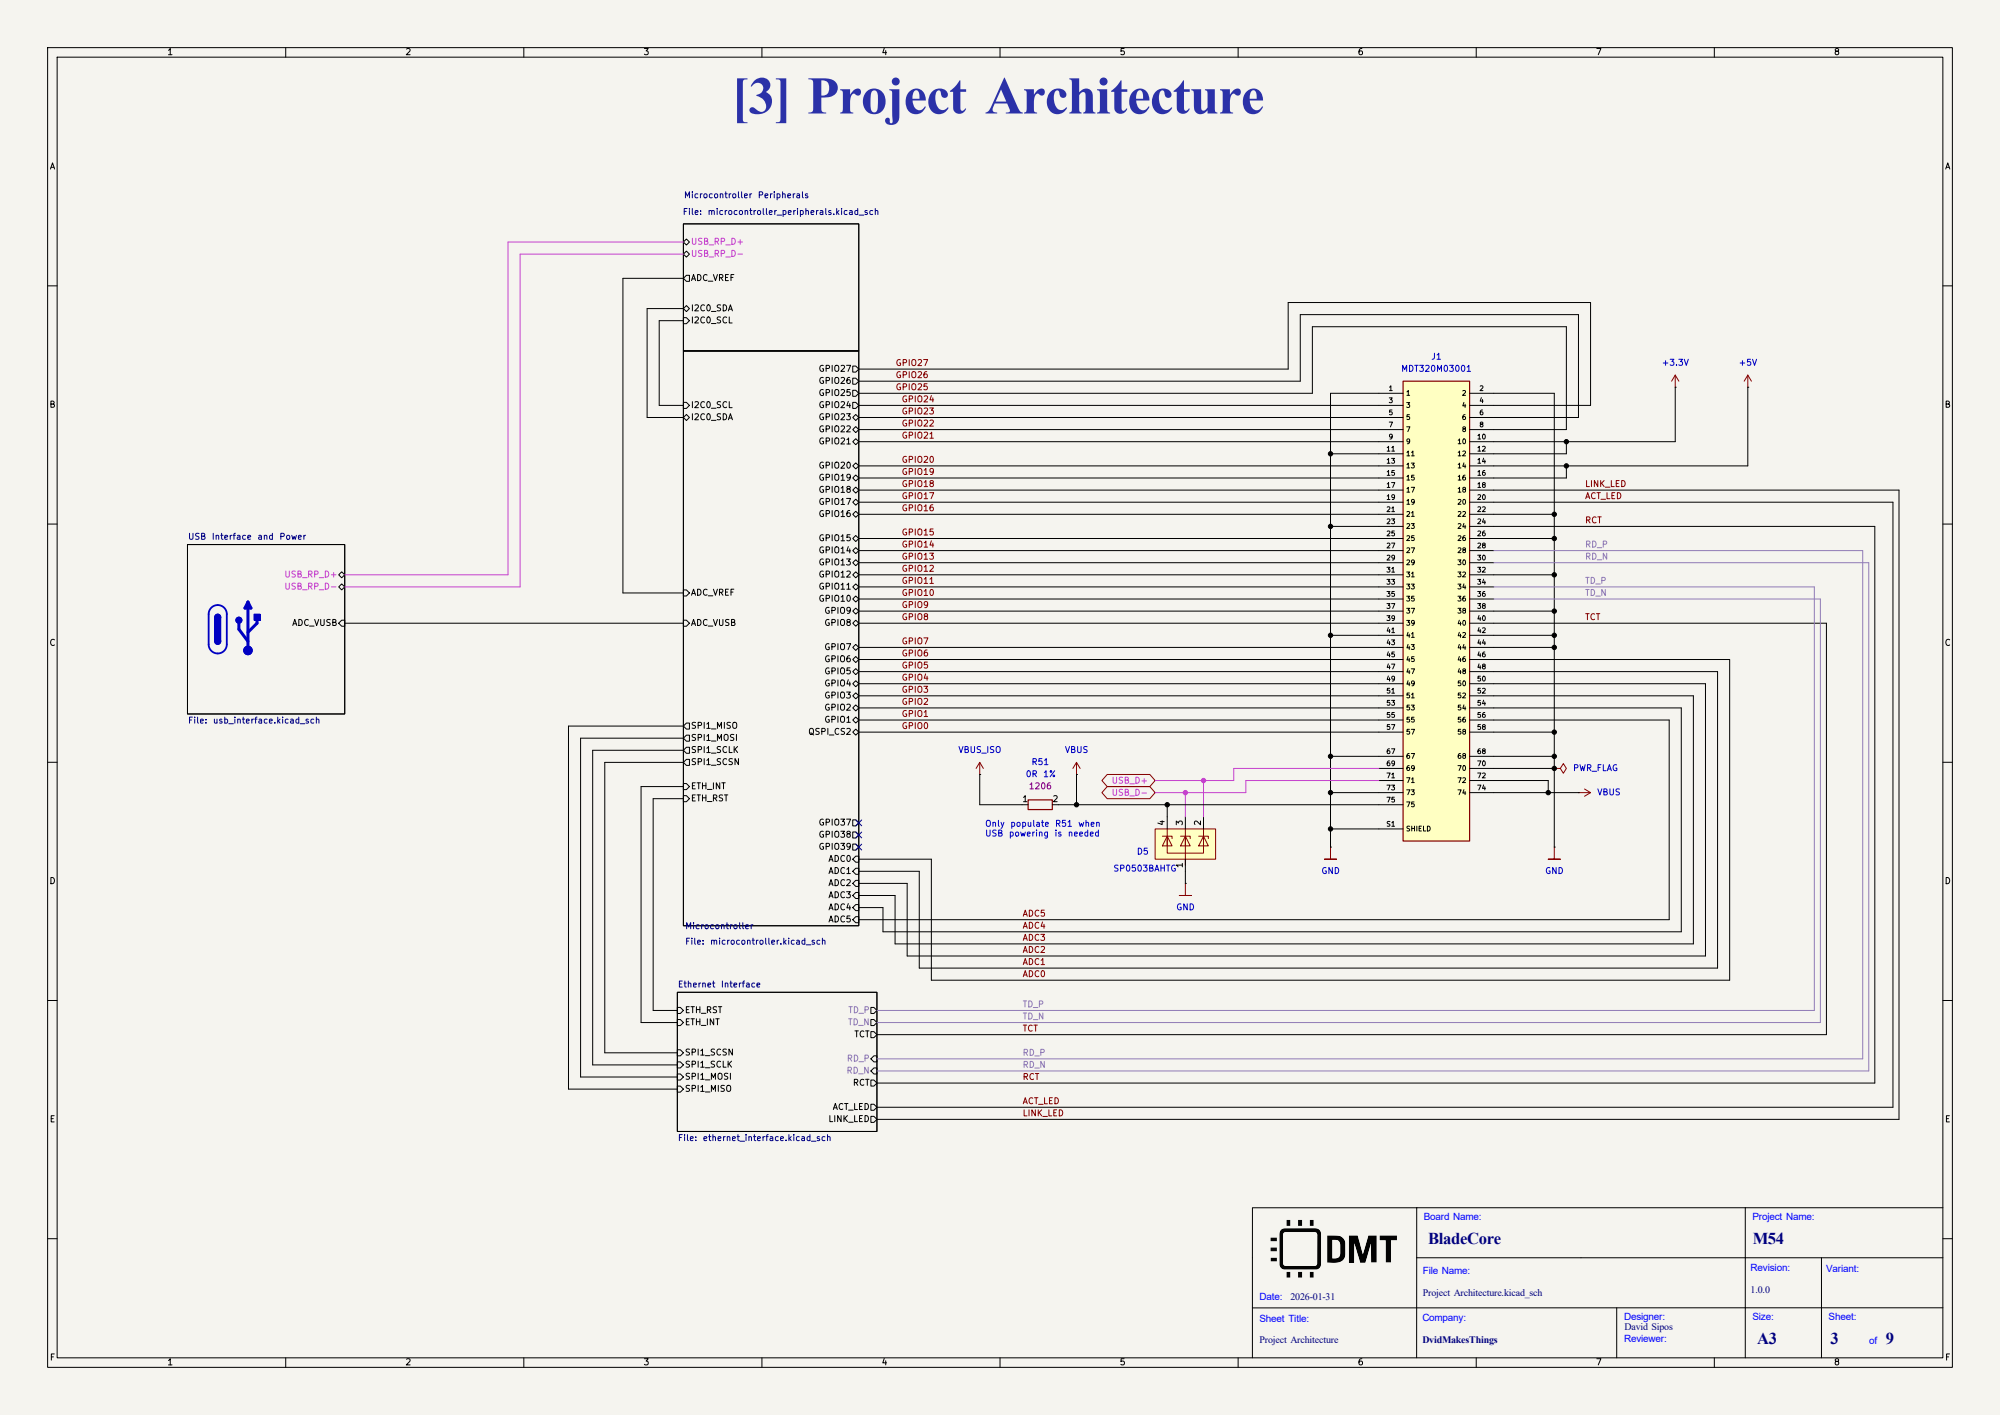
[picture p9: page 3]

3 2 D5 | J1 MDT320M03001 GND1 4 SHIELD S1 5 5 7 7

GPIO2 GPIO22 GPIO27 GPIO9 GPIO16 GPIO18 GPIO13 GPIO14 GPIO12 GPIO19 GPIO10

17 17
19 19 | | ACT_LED

GPIO15 GPIO17 | | | | RCT

23 23
25 25 | | RD_P

USB Interface and Power File: usb_interface.kicad_sch

TCT GPIO0

Only populate R51 when USB powering is needed

ADC4
ADC3
ADC2

File Name: Sheet Title: Project Architecture

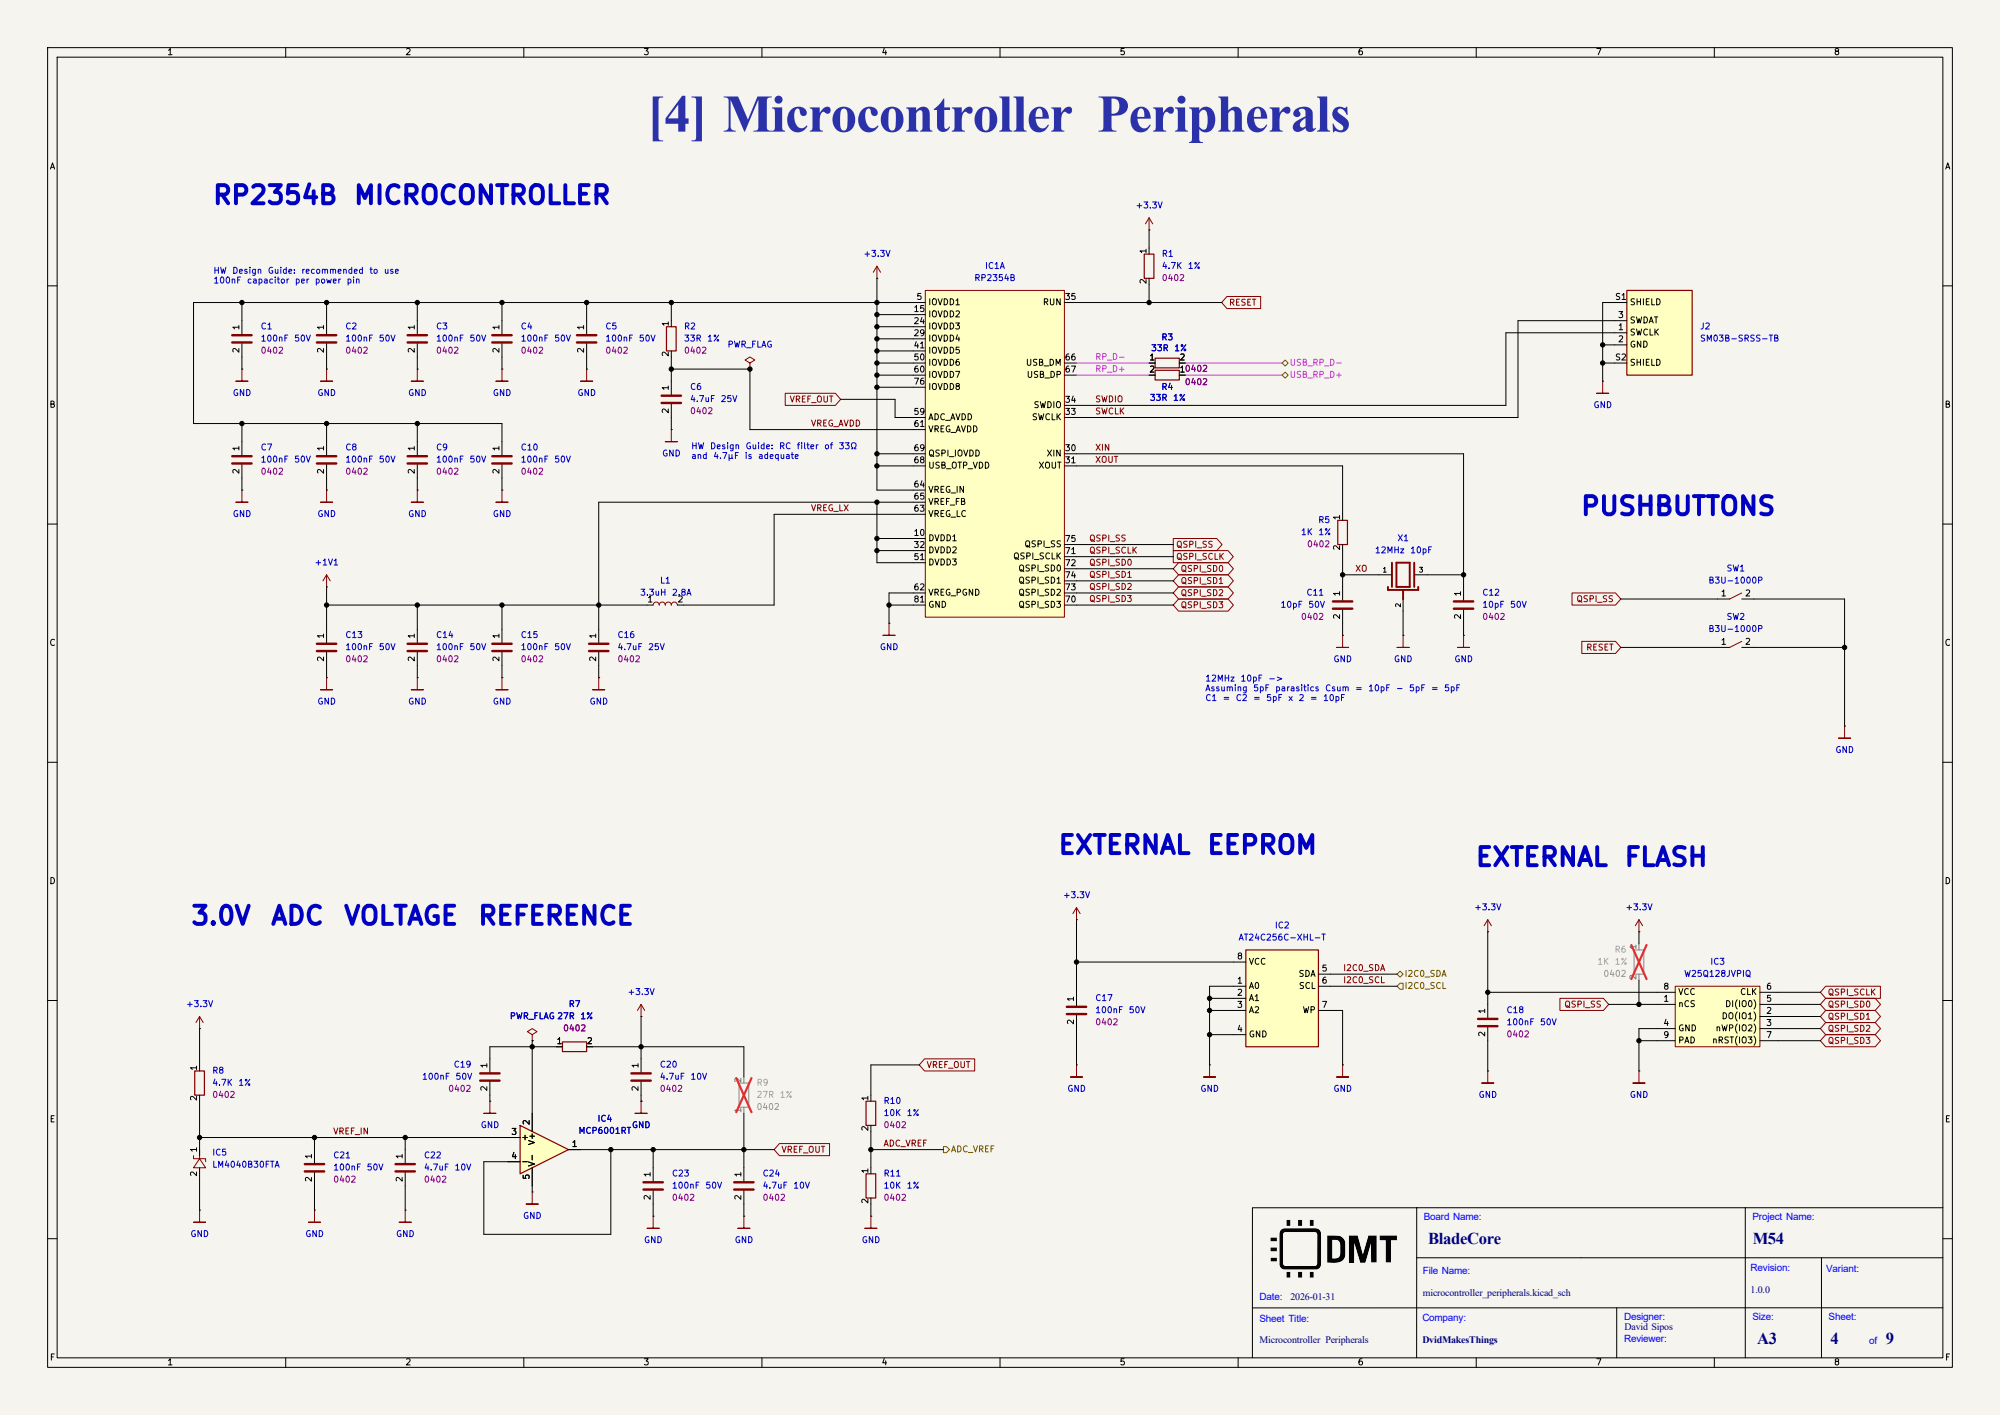
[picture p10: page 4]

HW Design Guide: recommended to use 100nF capacitor per power pin

Assuming 5pF parasitics Csum = 10pF - 5pF = 5pF C1 = C2 = 5pF x 2 = 10pF HW Design Guide: RC filter of 33Ω
GND
and 4.7μF is adequate

File Name: Sheet Title: Microcontroller Peripherals GND

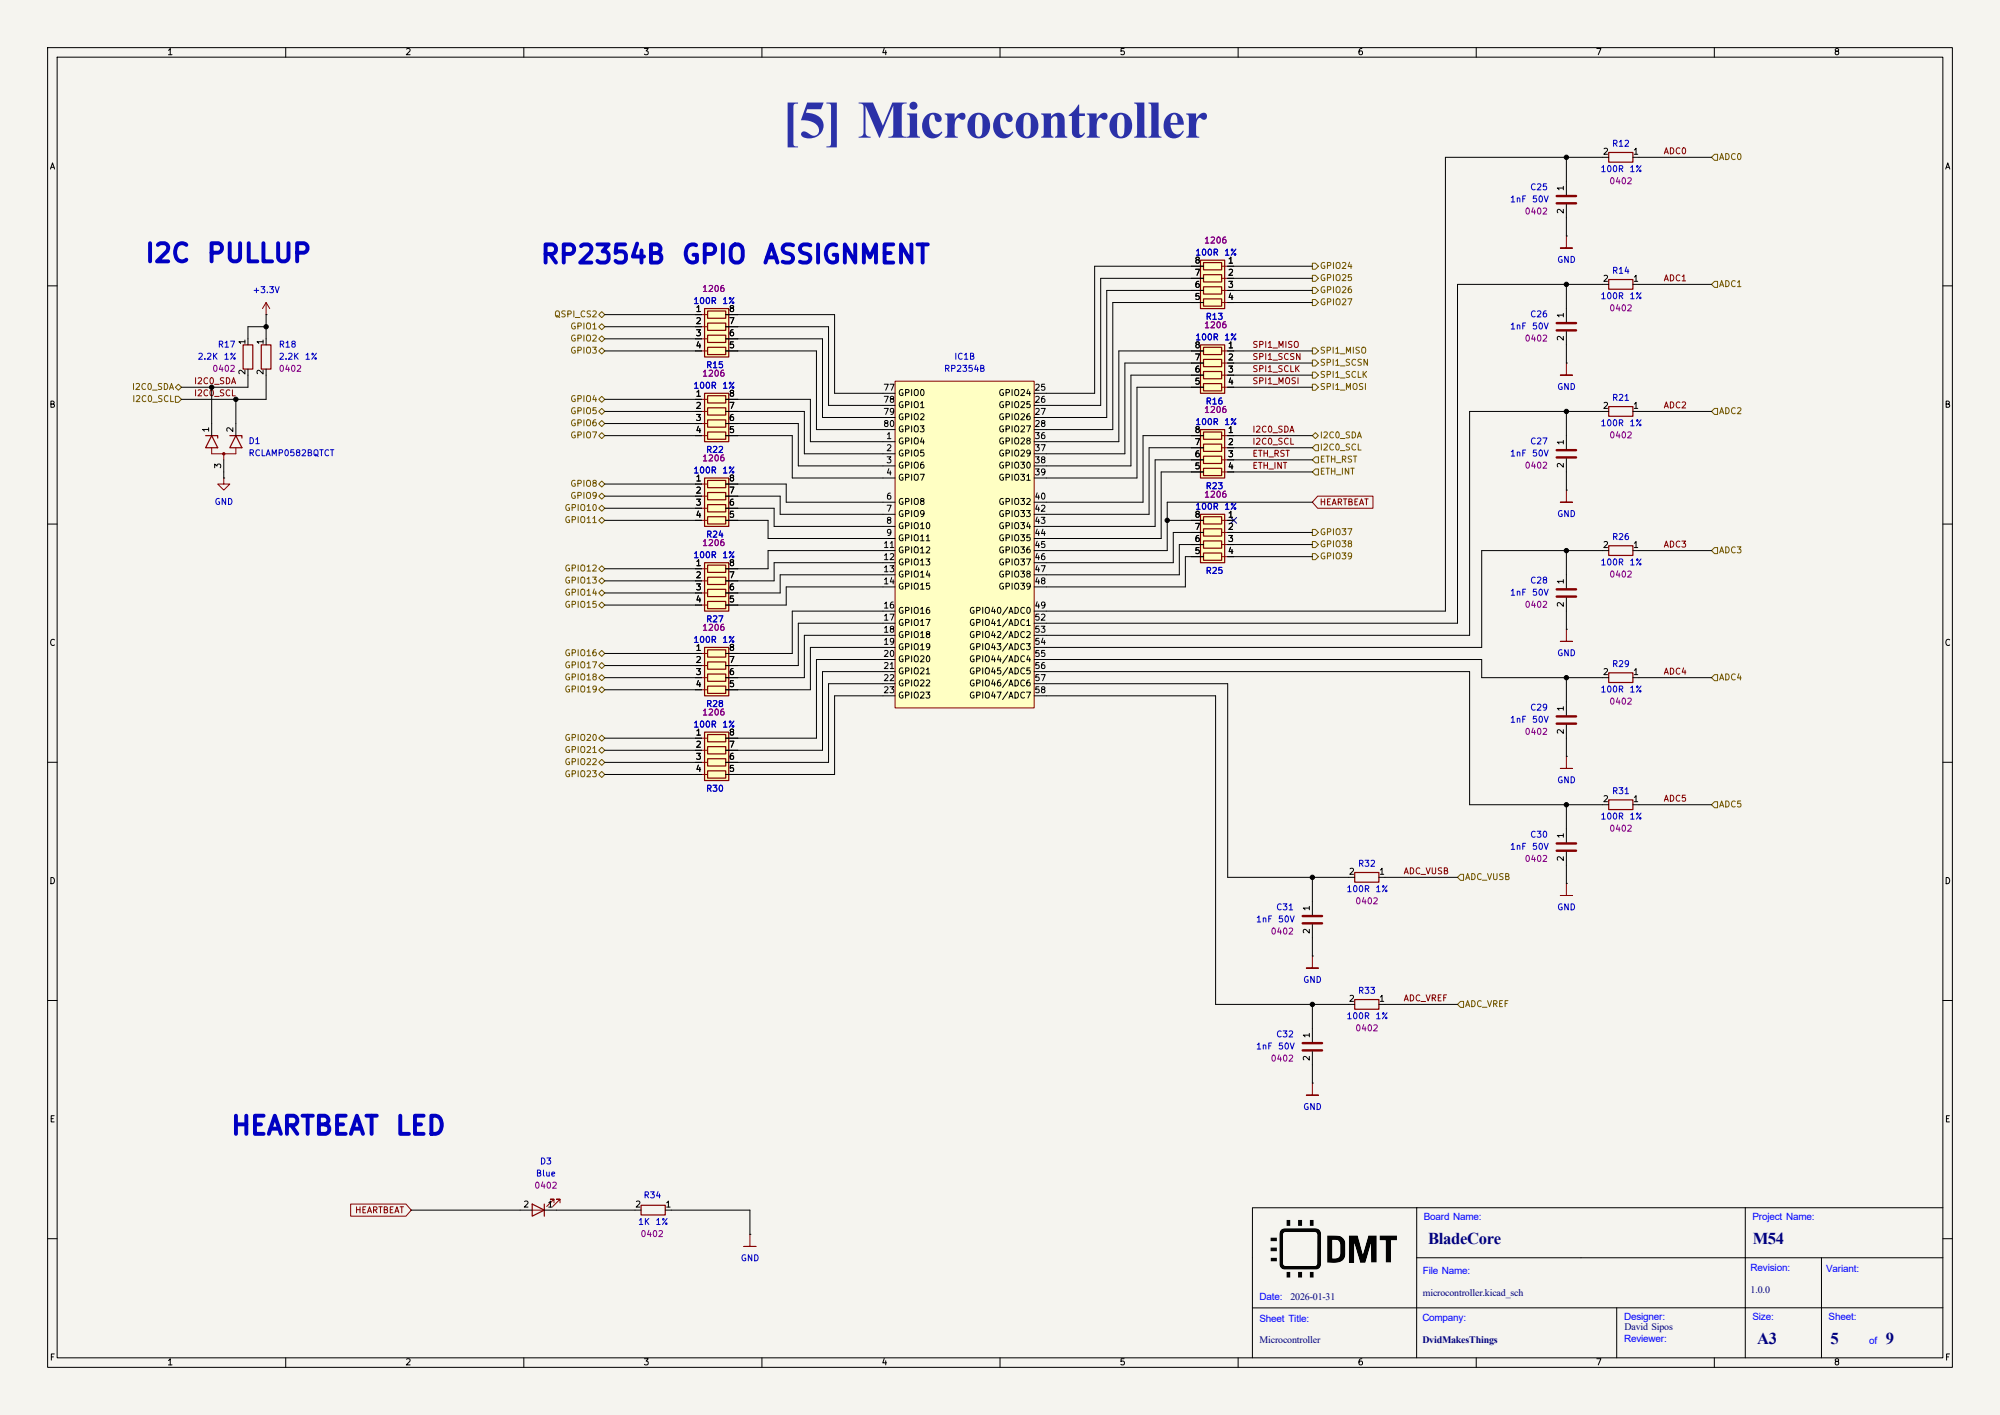
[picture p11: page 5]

7 7 | SPI1_SCSN
6 6 | SPI1_SCLK

File Name: Sheet Title: Microcontroller

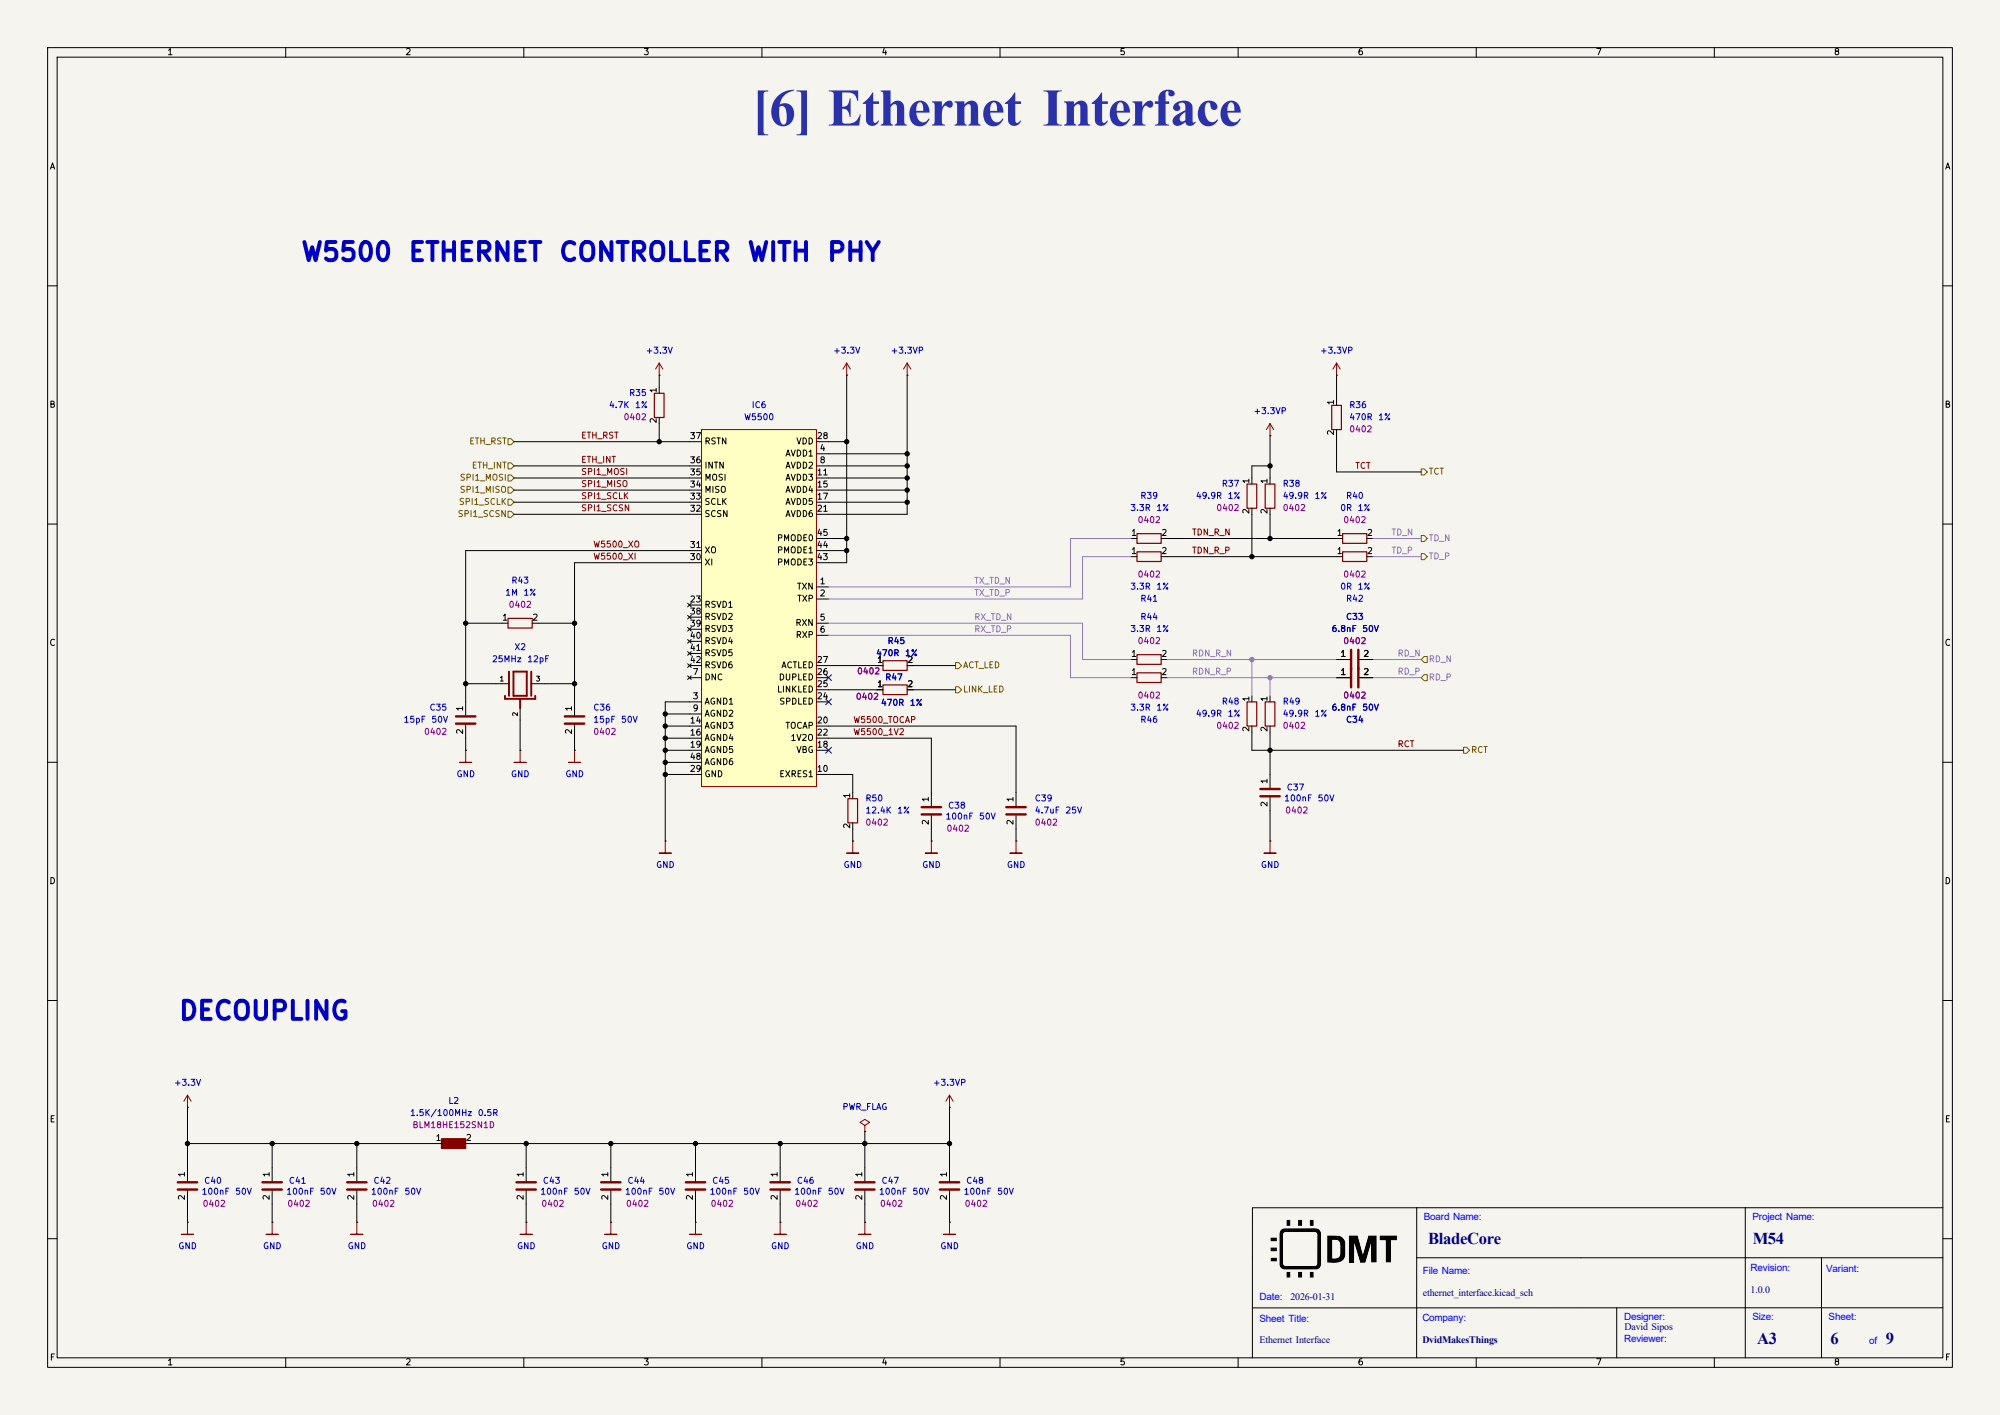
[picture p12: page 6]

W5500 ETHERNET CONTROLLER WITH PHY
VDD 28 GND 29

SPDLED 24 LINKLED 25 DUPLED 26 ACTLED 27

File Name: Sheet Title: Ethernet Interface PWR_FLAG

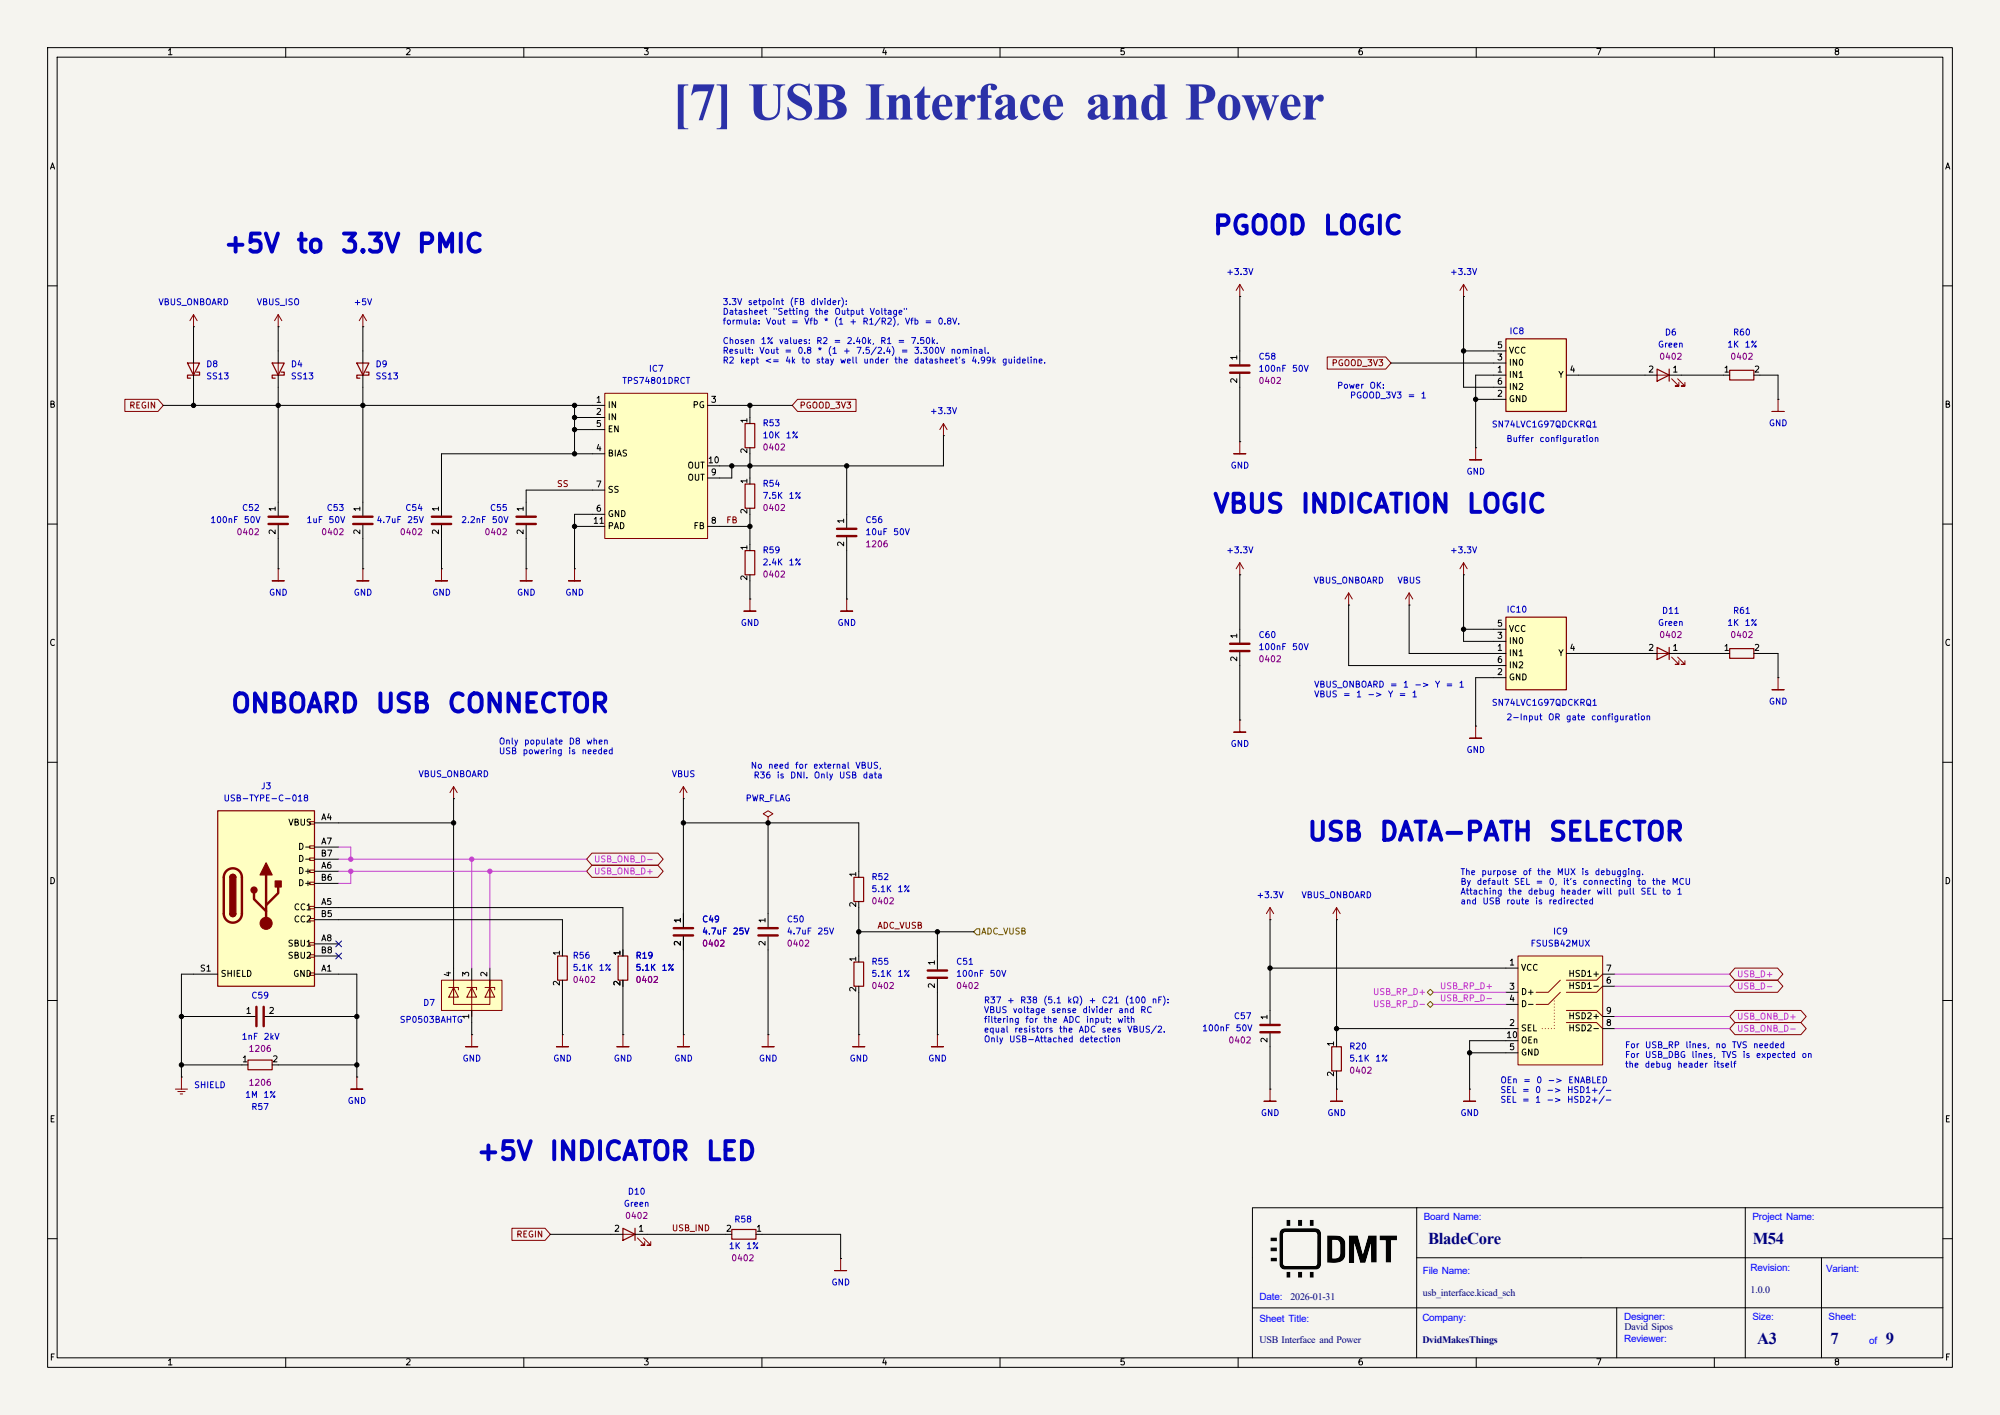
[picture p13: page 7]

ADC_VUSB [7] USB Interface and Power

Power OK: PGOOD_3V3 = 1 PGOOD LOGIC

and USB route is redirected No need for external VBUS, R36 is DNI. Only USB data +5V to 3.3V PMIC

3.3V setpoint (FB divider): Datasheet "Setting the Output Voltage"

formula: Vout = Vfb * (1 + R1/R2), Vfb = 0.8V. Chosen 1% values: R2 = 2.40k, R1 = 7.50k. Result: Vout = 0.8 * (1 + 7.5/2.4) = 3.300V nominal. R2 kept <= 4k to stay well under the datasheet's 4.99k guideline. R19

2-Input OR gate configuration Buffer configuration

VBUS = 1 -> Y = 1 ONBOARD USB CONNECTOR

USB DATA-PATH SELECTOR

The purpose of the MUX is debugging.
By default SEL = 0, it's connecting to the MCU
Attaching the debug header will pull SEL to 1

R37 + R38 (5.1 kΩ) + C21 (100 nF): VBUS voltage sense divider and RC

filtering for the ADC input; with equal resistors the ADC sees VBUS/2.

Only USB-Attached detection

For USB_RP lines, no TVS needed
For USB_DBG lines, TVS is expected on

the debug header itself +5V INDICATOR LED

File Name: Sheet Title: USB Interface and Power

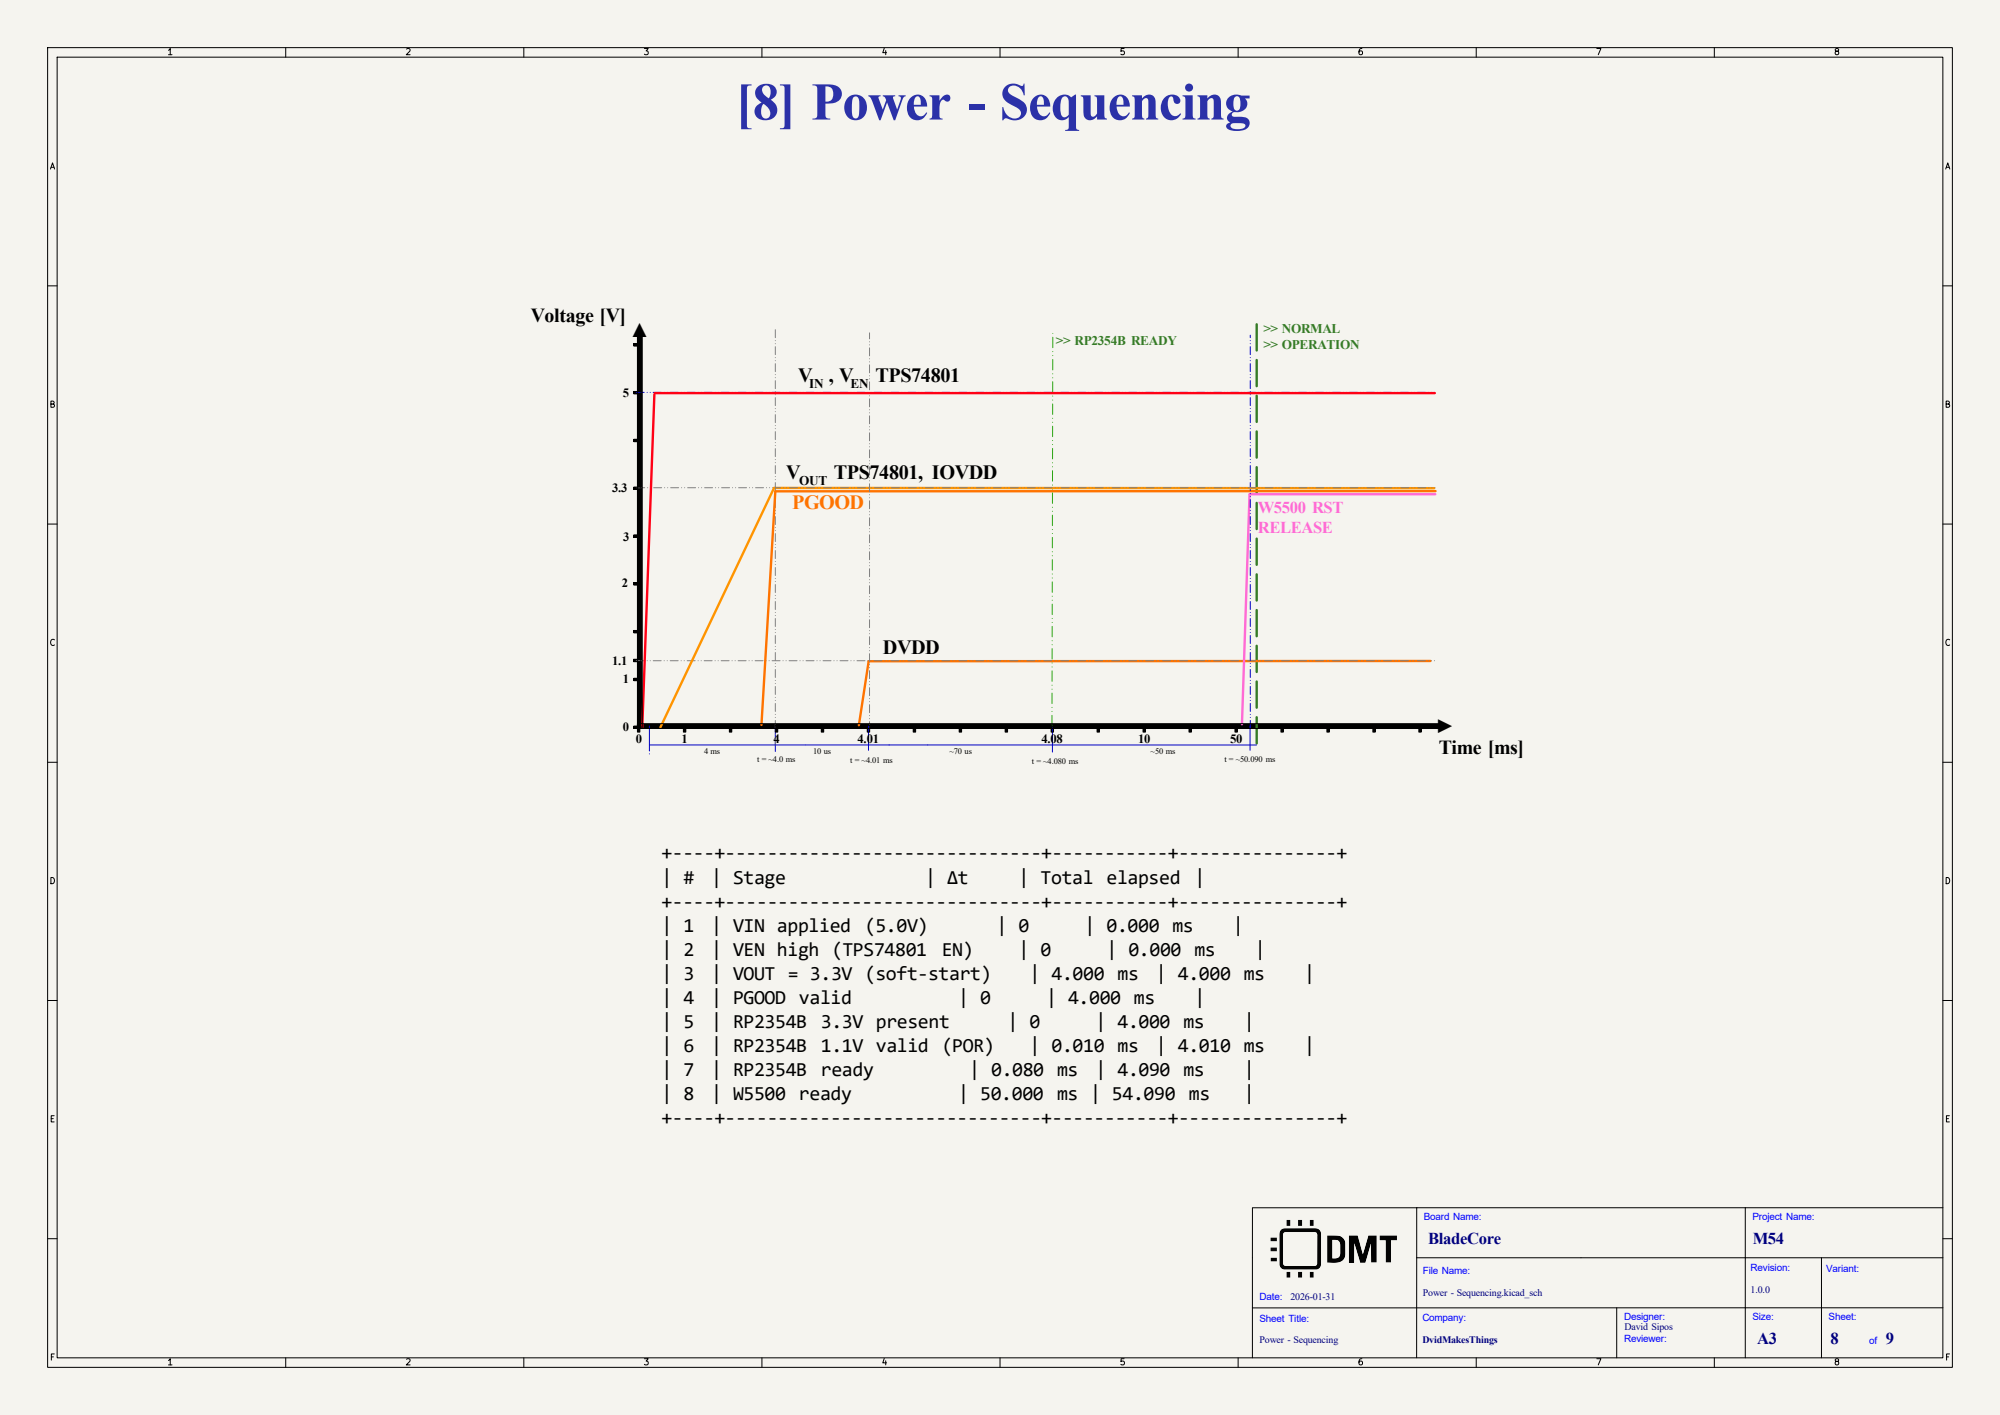
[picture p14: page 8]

File Name: Sheet Title: Power - Sequencing

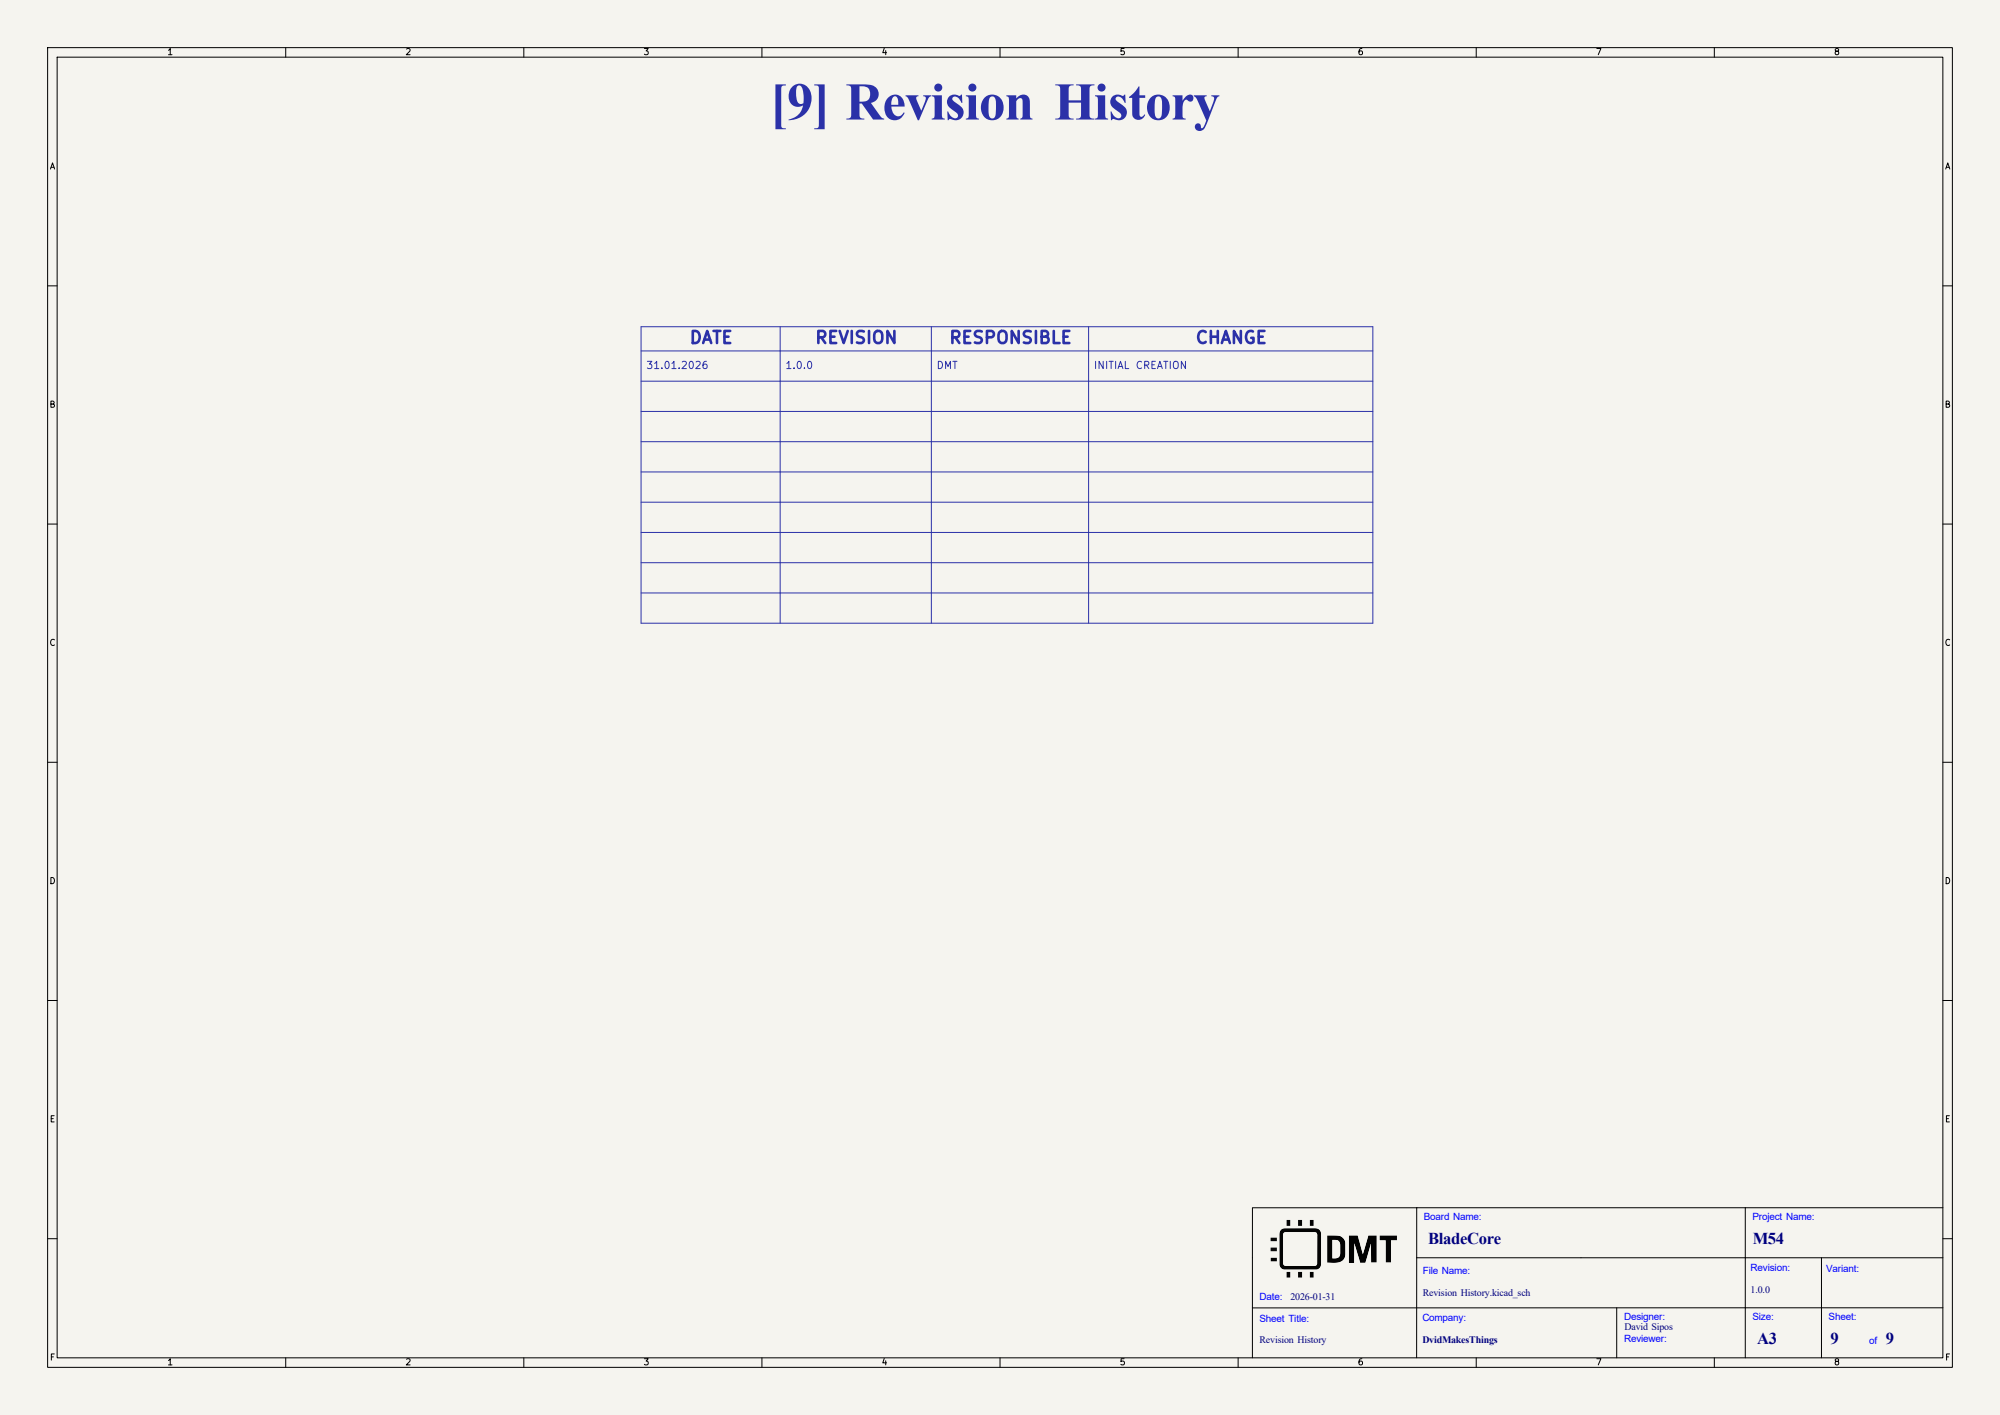
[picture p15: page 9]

DATE | REVISION | RESPONSIBLE | CHANGE

31.01.2026 | 1.0.0 | DMT | INITIAL CREATION

File Name: Sheet Title: Revision History

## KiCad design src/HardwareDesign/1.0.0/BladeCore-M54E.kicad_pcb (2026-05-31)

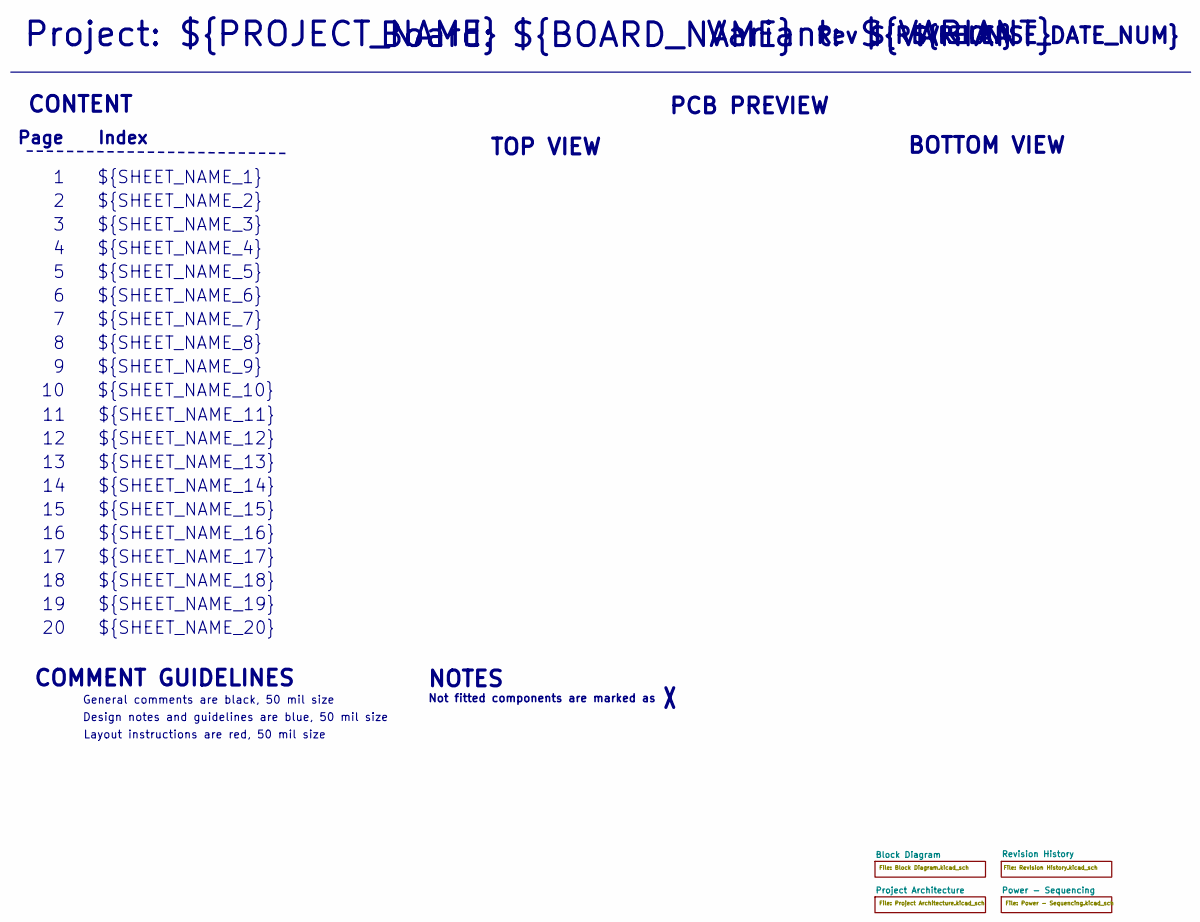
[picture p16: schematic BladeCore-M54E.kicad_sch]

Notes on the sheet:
${SHEET_NAME_12}
${SHEET_NAME_8}
${SHEET_NAME_2}
${SHEET_NAME_5}
${SHEET_NAME_20}
Page
PCB PREVIEW
${RELEASE_DATE_NUM}
CONTENT
${SHEET_NAME_11}
${SHEET_NAME_6}
Rev ${REVISION}
${SHEET_NAME_15}
BOTTOM VIEW
${SHEET_NAME_14}
${SHEET_NAME_17}
${SHEET_NAME_18}
${SHEET_NAME_7}
Not fitted components are marked as
Project: ${PROJECT_NAME}
NOTES
Design notes and guidelines are blue, 50 mil size
${SHEET_NAME_1}
${SHEET_NAME_9}
Board: ${BOARD_NAME}
General comments are black, 50 mil size
${SHEET_NAME_16}
${SHEET_NAME_3}
Variant: ${VARIANT}
${SHEET_NAME_19}
TOP VIEW
${SHEET_NAME_10}
Index
${SHEET_NAME_13}
${SHEET_NAME_4}
COMMENT GUIDELINES
Layout instructions are red, 50 mil size

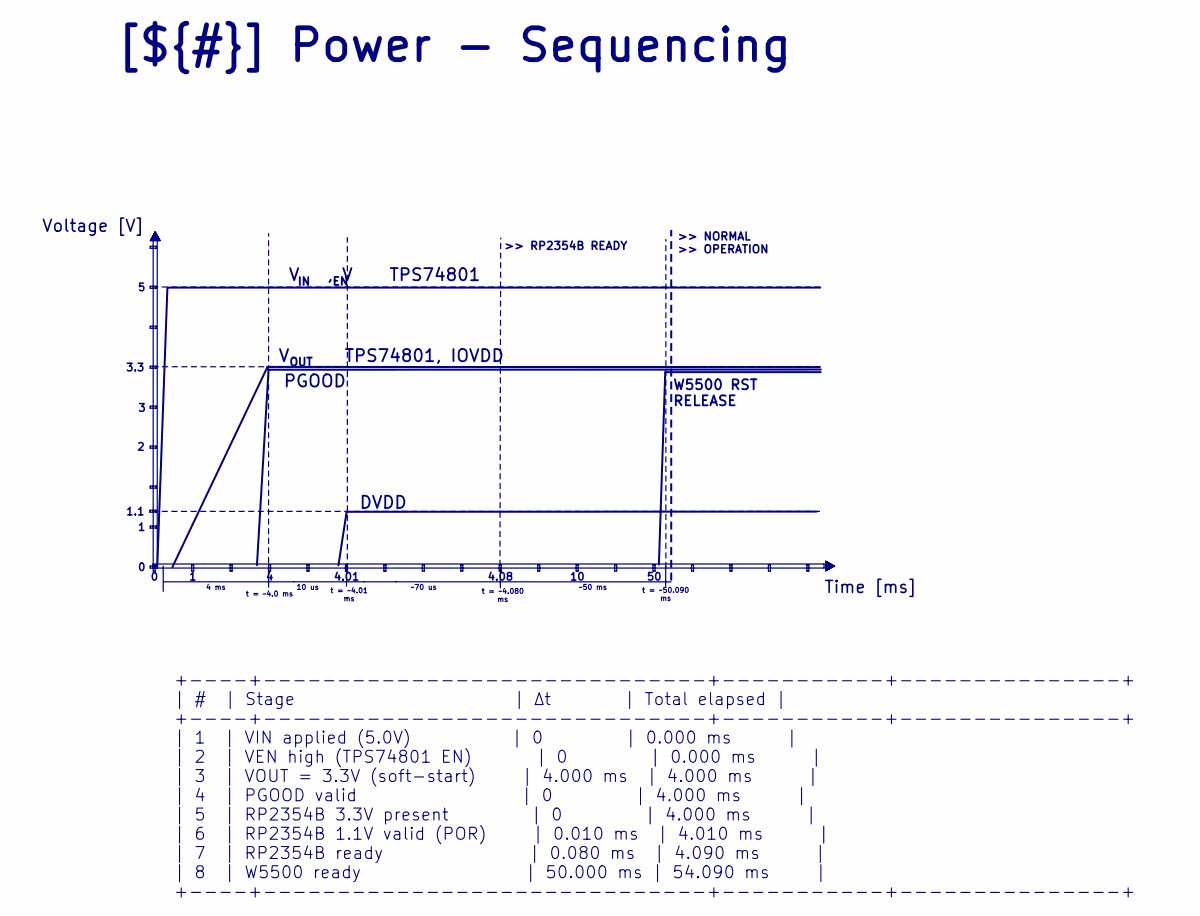
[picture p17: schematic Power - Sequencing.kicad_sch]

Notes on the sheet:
>> RP2354B READY
Voltage [V]
+----+------------------------------+-----------+---------------+ | # | Stage | Δt | Total elapsed | +----+------------------------------+-----------+---------------+ | 1 | VIN applied (5.0V) | 0 | 0.000 ms | | 2 | VEN high (TPS74801 EN) | 0 | 0.000 ms | | 3 | VOUT = 3.3V (soft-start) | 4.000 ms | 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
>> NORMAL >> OPERATION
Time [ms]
10 us
4.08
~70 us
4.01
DVDD
t = ~4.01 ms
3.3
W5500 RST RELEASE
~50 ms
t = ~50.090 ms
t = ~4.080 ms
V , V TPS74801
t = ~4.0 ms
PGOOD
1.1
4 ms
OUT
V TPS74801, IOVDD
[${#}] ${TITLE}

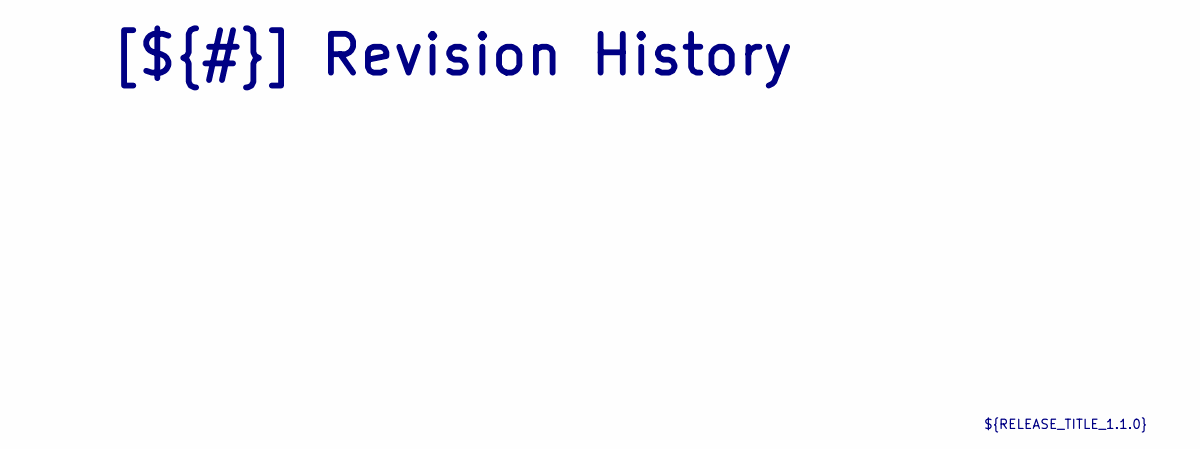
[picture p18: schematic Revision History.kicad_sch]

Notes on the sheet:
[${#}] ${TITLE}
${RELEASE_TITLE_1.1.0}

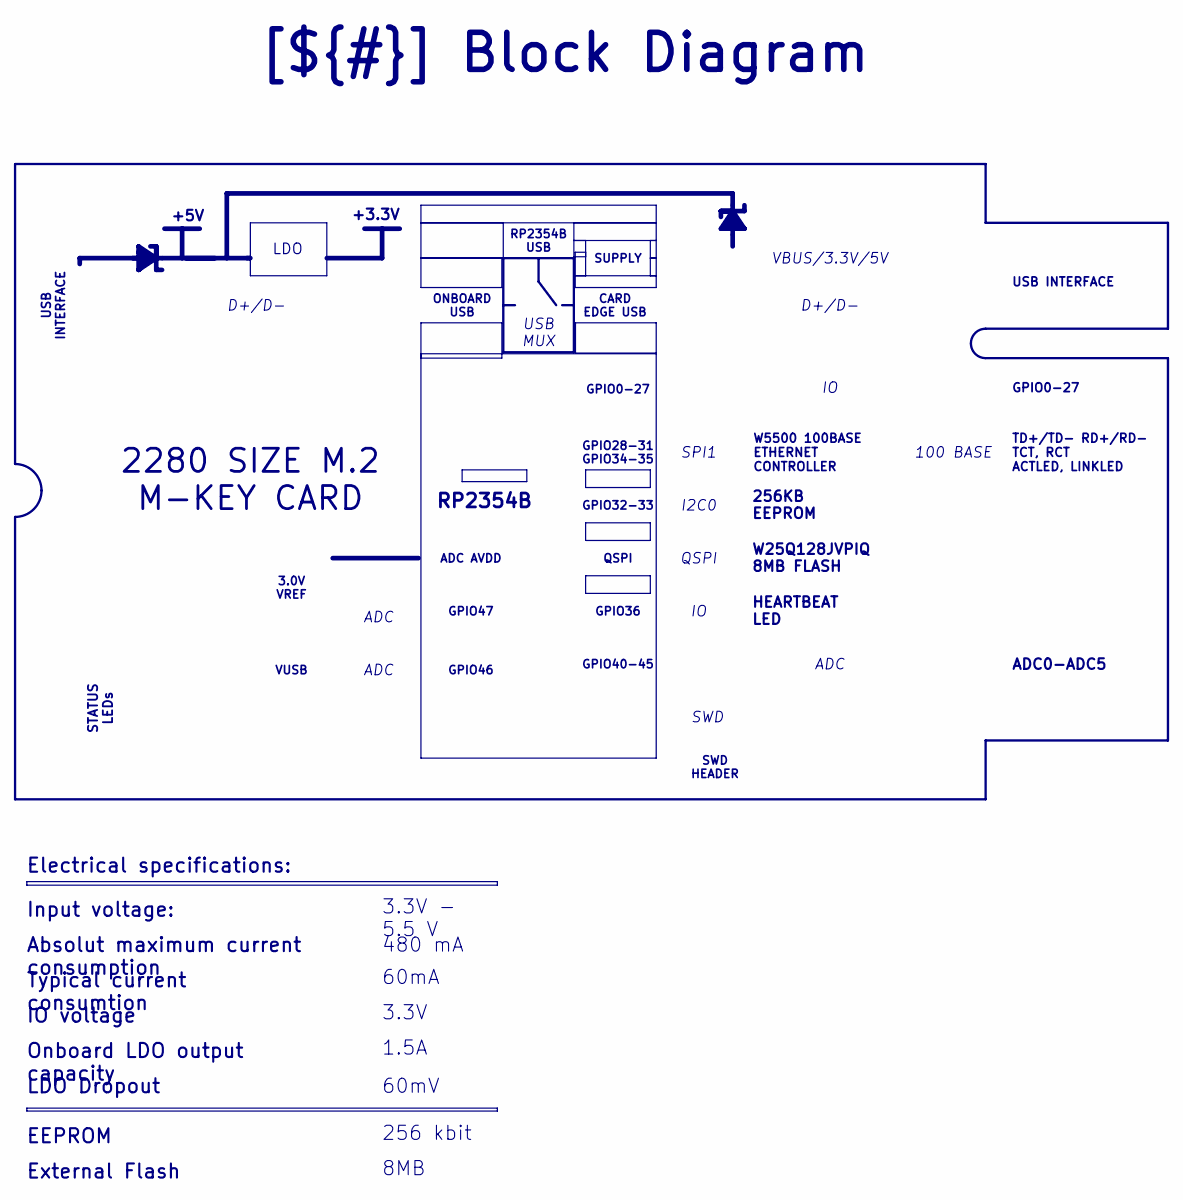
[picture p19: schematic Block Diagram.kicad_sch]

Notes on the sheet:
+3.3V
RP2354B
2280 SIZE M.2 M-KEY CARD
+5V
USB INTERFACE
LDO Dropout
IO voltage
256KB EEPROM
VBUS/3.3V/5V
1.5A
CARD EDGE USB
W25Q128JVPIQ 8MB FLASH
3.3V - 5.5 V
ADC0-ADC5
SWD HEADER
LDO
3.3V
GPIO0-27
TD+/TD- RD+/RD- TCT, RCT ACTLED, LINKLED
SPI1
W5500 100BASE ETHERNET CONTROLLER
GPIO40-45
ADC
QSPI
3.0V VREF
RP2354B USB
GPIO32-33
[${#}] ${TITLE}
480 mA
Input voltage:
STATUS LEDs
EEPROM
GPIO46
256 kbit
Electrical specifications:
SWD
GPIO47
GPIO36
GPIO28-31 GPIO34-35
ONBOARD USB

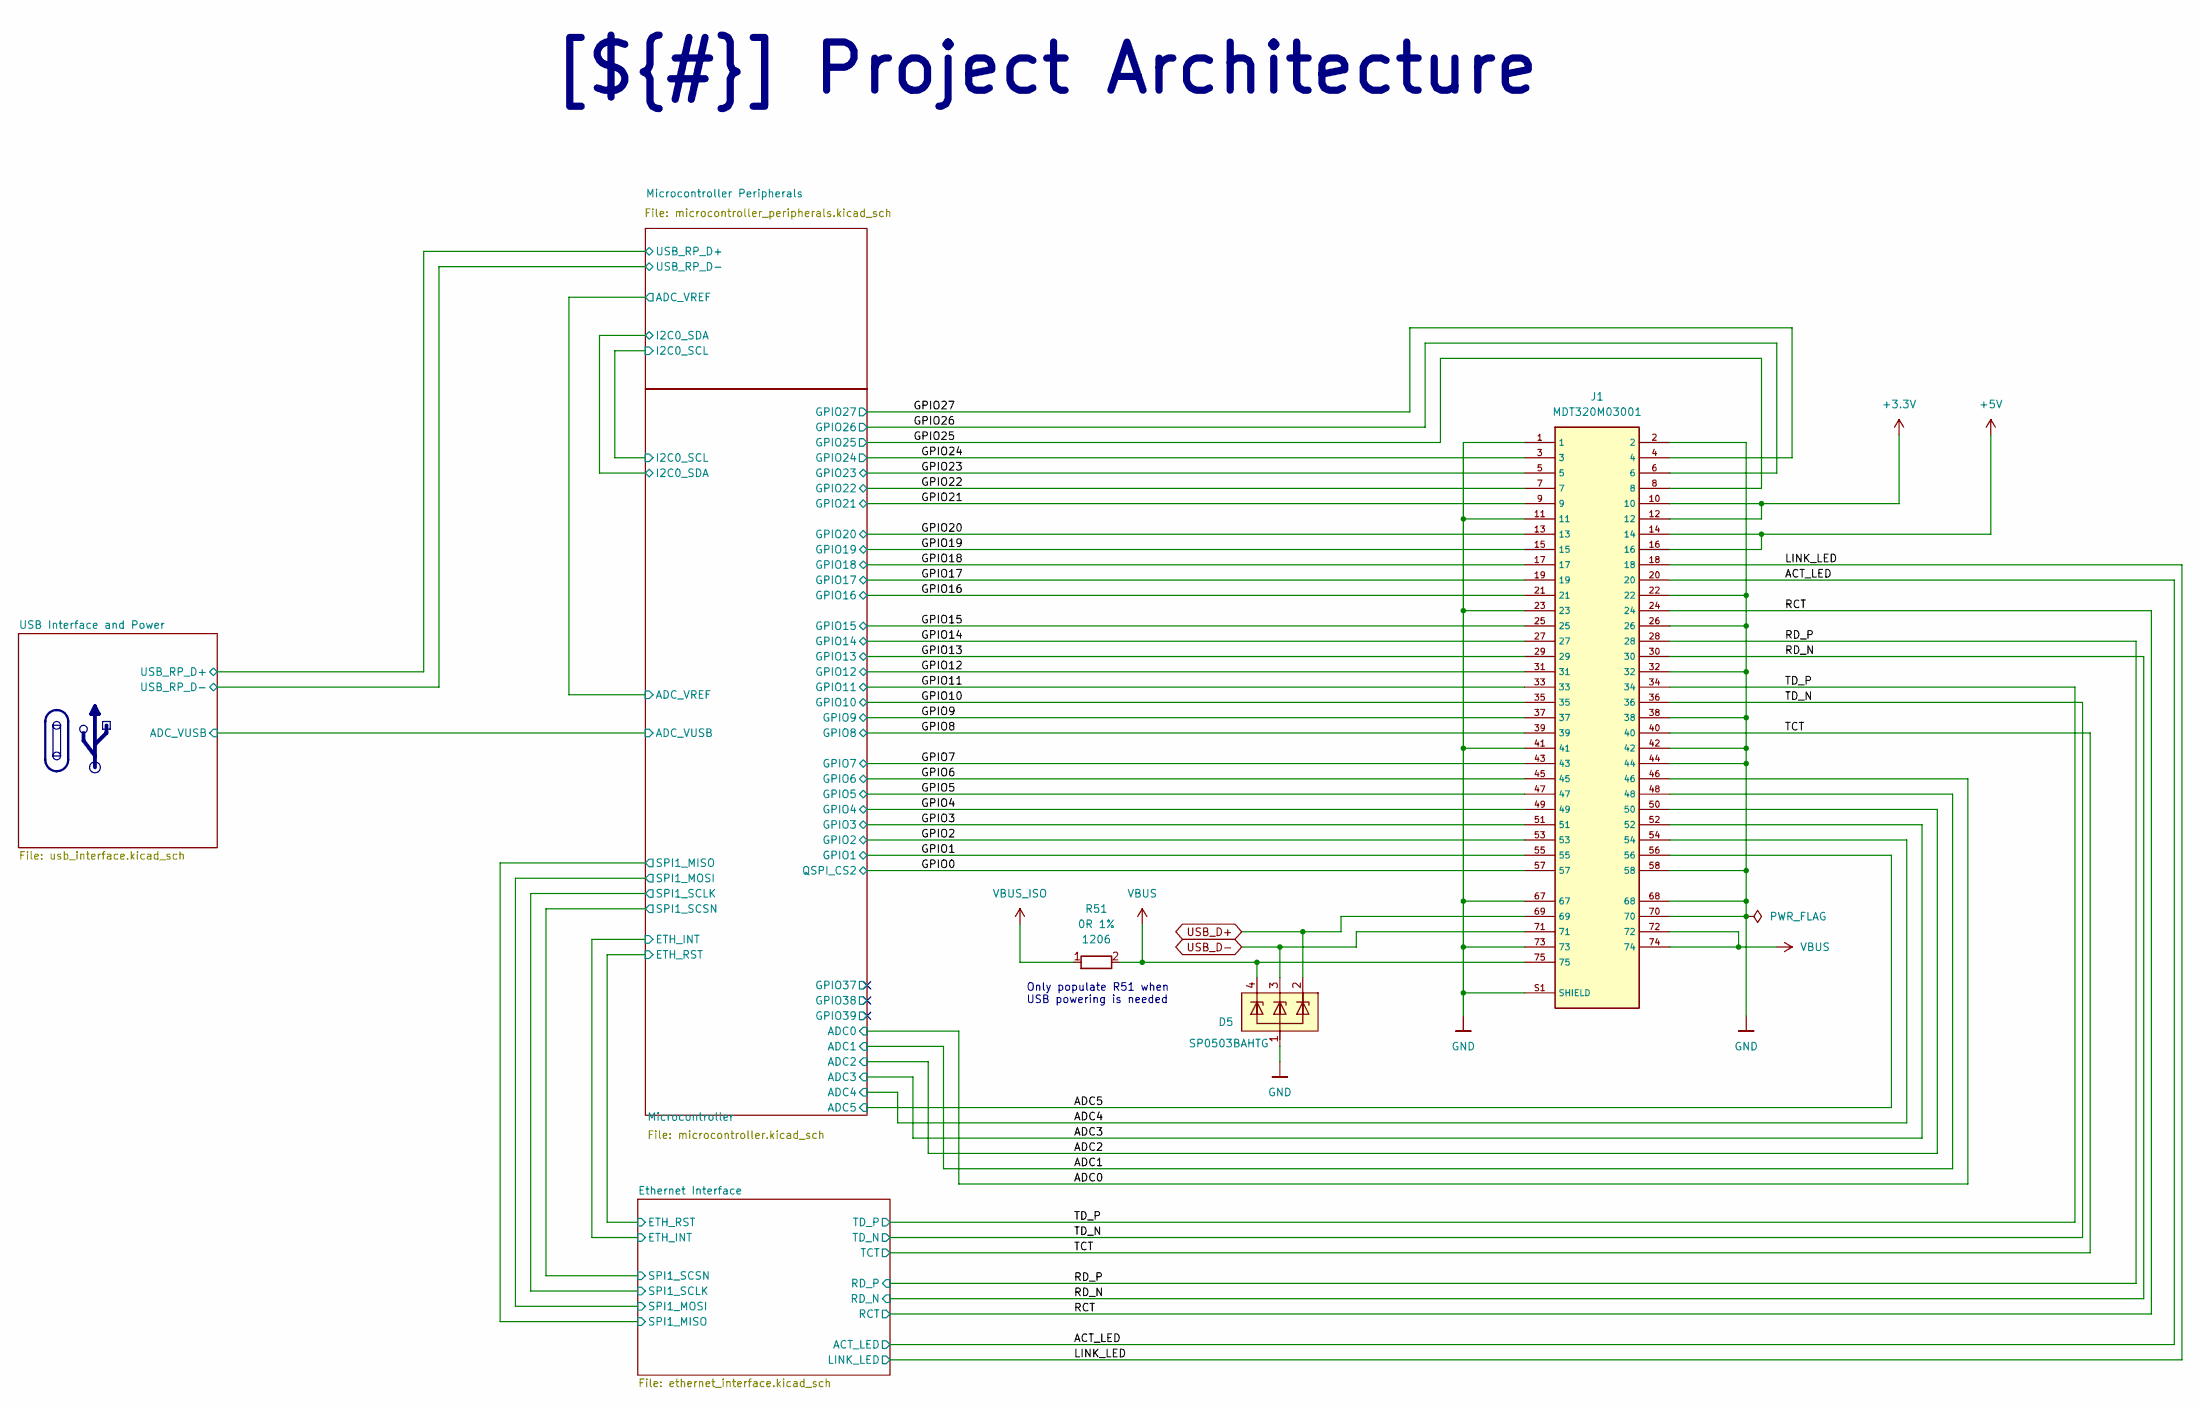
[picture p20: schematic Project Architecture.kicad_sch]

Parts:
D5: SP0503BAHTG; SOT143; MPN SP0503BAHTG; LCSC_PART C3040626
J1: MDT320M03001; M.2-M-KEY_Card_Plain
R51: 0R 1%; R_1206_3216Metric; LCSC_PART C17888

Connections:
+3.3V: J1.10, J1.12; also elsewhere on the board
+5V: J1.14, J1.16; also elsewhere on the board
/Project Architecture/ACT_LED: J1.20; also elsewhere on the board
/Project Architecture/ADC0: J1.46; also elsewhere on the board
/Project Architecture/ADC1: J1.48; also elsewhere on the board
/Project Architecture/ADC2: J1.50; also elsewhere on the board
/Project Architecture/ADC3: J1.52; also elsewhere on the board
/Project Architecture/ADC4: J1.54; also elsewhere on the board
/Project Architecture/ADC5: J1.56; also elsewhere on the board
/Project Architecture/GPIO0: J1.57; also elsewhere on the board
/Project Architecture/GPIO1: J1.55; also elsewhere on the board
/Project Architecture/GPIO2: J1.53; also elsewhere on the board
/Project Architecture/GPIO3: J1.51; also elsewhere on the board
/Project Architecture/GPIO4: J1.49; also elsewhere on the board
/Project Architecture/GPIO5: J1.47; also elsewhere on the board
/Project Architecture/GPIO6: J1.45; also elsewhere on the board
/Project Architecture/GPIO7: J1.43; also elsewhere on the board
/Project Architecture/GPIO8: J1.39; also elsewhere on the board
/Project Architecture/GPIO9: J1.37; also elsewhere on the board
/Project Architecture/GPIO10: J1.35; also elsewhere on the board
/Project Architecture/GPIO11: J1.33; also elsewhere on the board
/Project Architecture/GPIO12: J1.31; also elsewhere on the board
/Project Architecture/GPIO13: J1.29; also elsewhere on the board
/Project Architecture/GPIO14: J1.27; also elsewhere on the board
/Project Architecture/GPIO15: J1.25; also elsewhere on the board
/Project Architecture/GPIO16: J1.21; also elsewhere on the board
/Project Architecture/GPIO17: J1.19; also elsewhere on the board
/Project Architecture/GPIO18: J1.17; also elsewhere on the board
/Project Architecture/GPIO19: J1.15; also elsewhere on the board
/Project Architecture/GPIO20: J1.13; also elsewhere on the board
/Project Architecture/GPIO21: J1.9; also elsewhere on the board
/Project Architecture/GPIO22: J1.7; also elsewhere on the board
/Project Architecture/GPIO23: J1.5; also elsewhere on the board
/Project Architecture/GPIO24: J1.3; also elsewhere on the board
/Project Architecture/GPIO25: J1.8; also elsewhere on the board
/Project Architecture/GPIO26: J1.6; also elsewhere on the board
/Project Architecture/GPIO27: J1.4; also elsewhere on the board
/Project Architecture/LINK_LED: J1.18; also elsewhere on the board
/Project Architecture/RCT: J1.24; also elsewhere on the board
/Project Architecture/RD_N: J1.30; also elsewhere on the board
/Project Architecture/RD_P: J1.28; also elsewhere on the board
/Project Architecture/TCT: J1.40; also elsewhere on the board
/Project Architecture/TD_N: J1.36; also elsewhere on the board
/Project Architecture/TD_P: J1.34; also elsewhere on the board
GND: D5.1, J1.1, J1.2, J1.11, J1.22, J1.23, J1.26, J1.32, J1.38, J1.41, J1.42, J1.44, J1.58, J1.67, J1.68, J1.70, J1.73, J1.S1 (SHIELD); also elsewhere on the board
USB_D+: D5.2, J1.69; also elsewhere on the board
USB_D-: D5.3, J1.71; also elsewhere on the board
VBUS: D5.4, J1.72, J1.74, J1.75, R51.2; also elsewhere on the board
VBUS_ISO: R51.1; also elsewhere on the board

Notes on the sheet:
Only populate R51 when USB powering is needed
[${#}] ${TITLE}

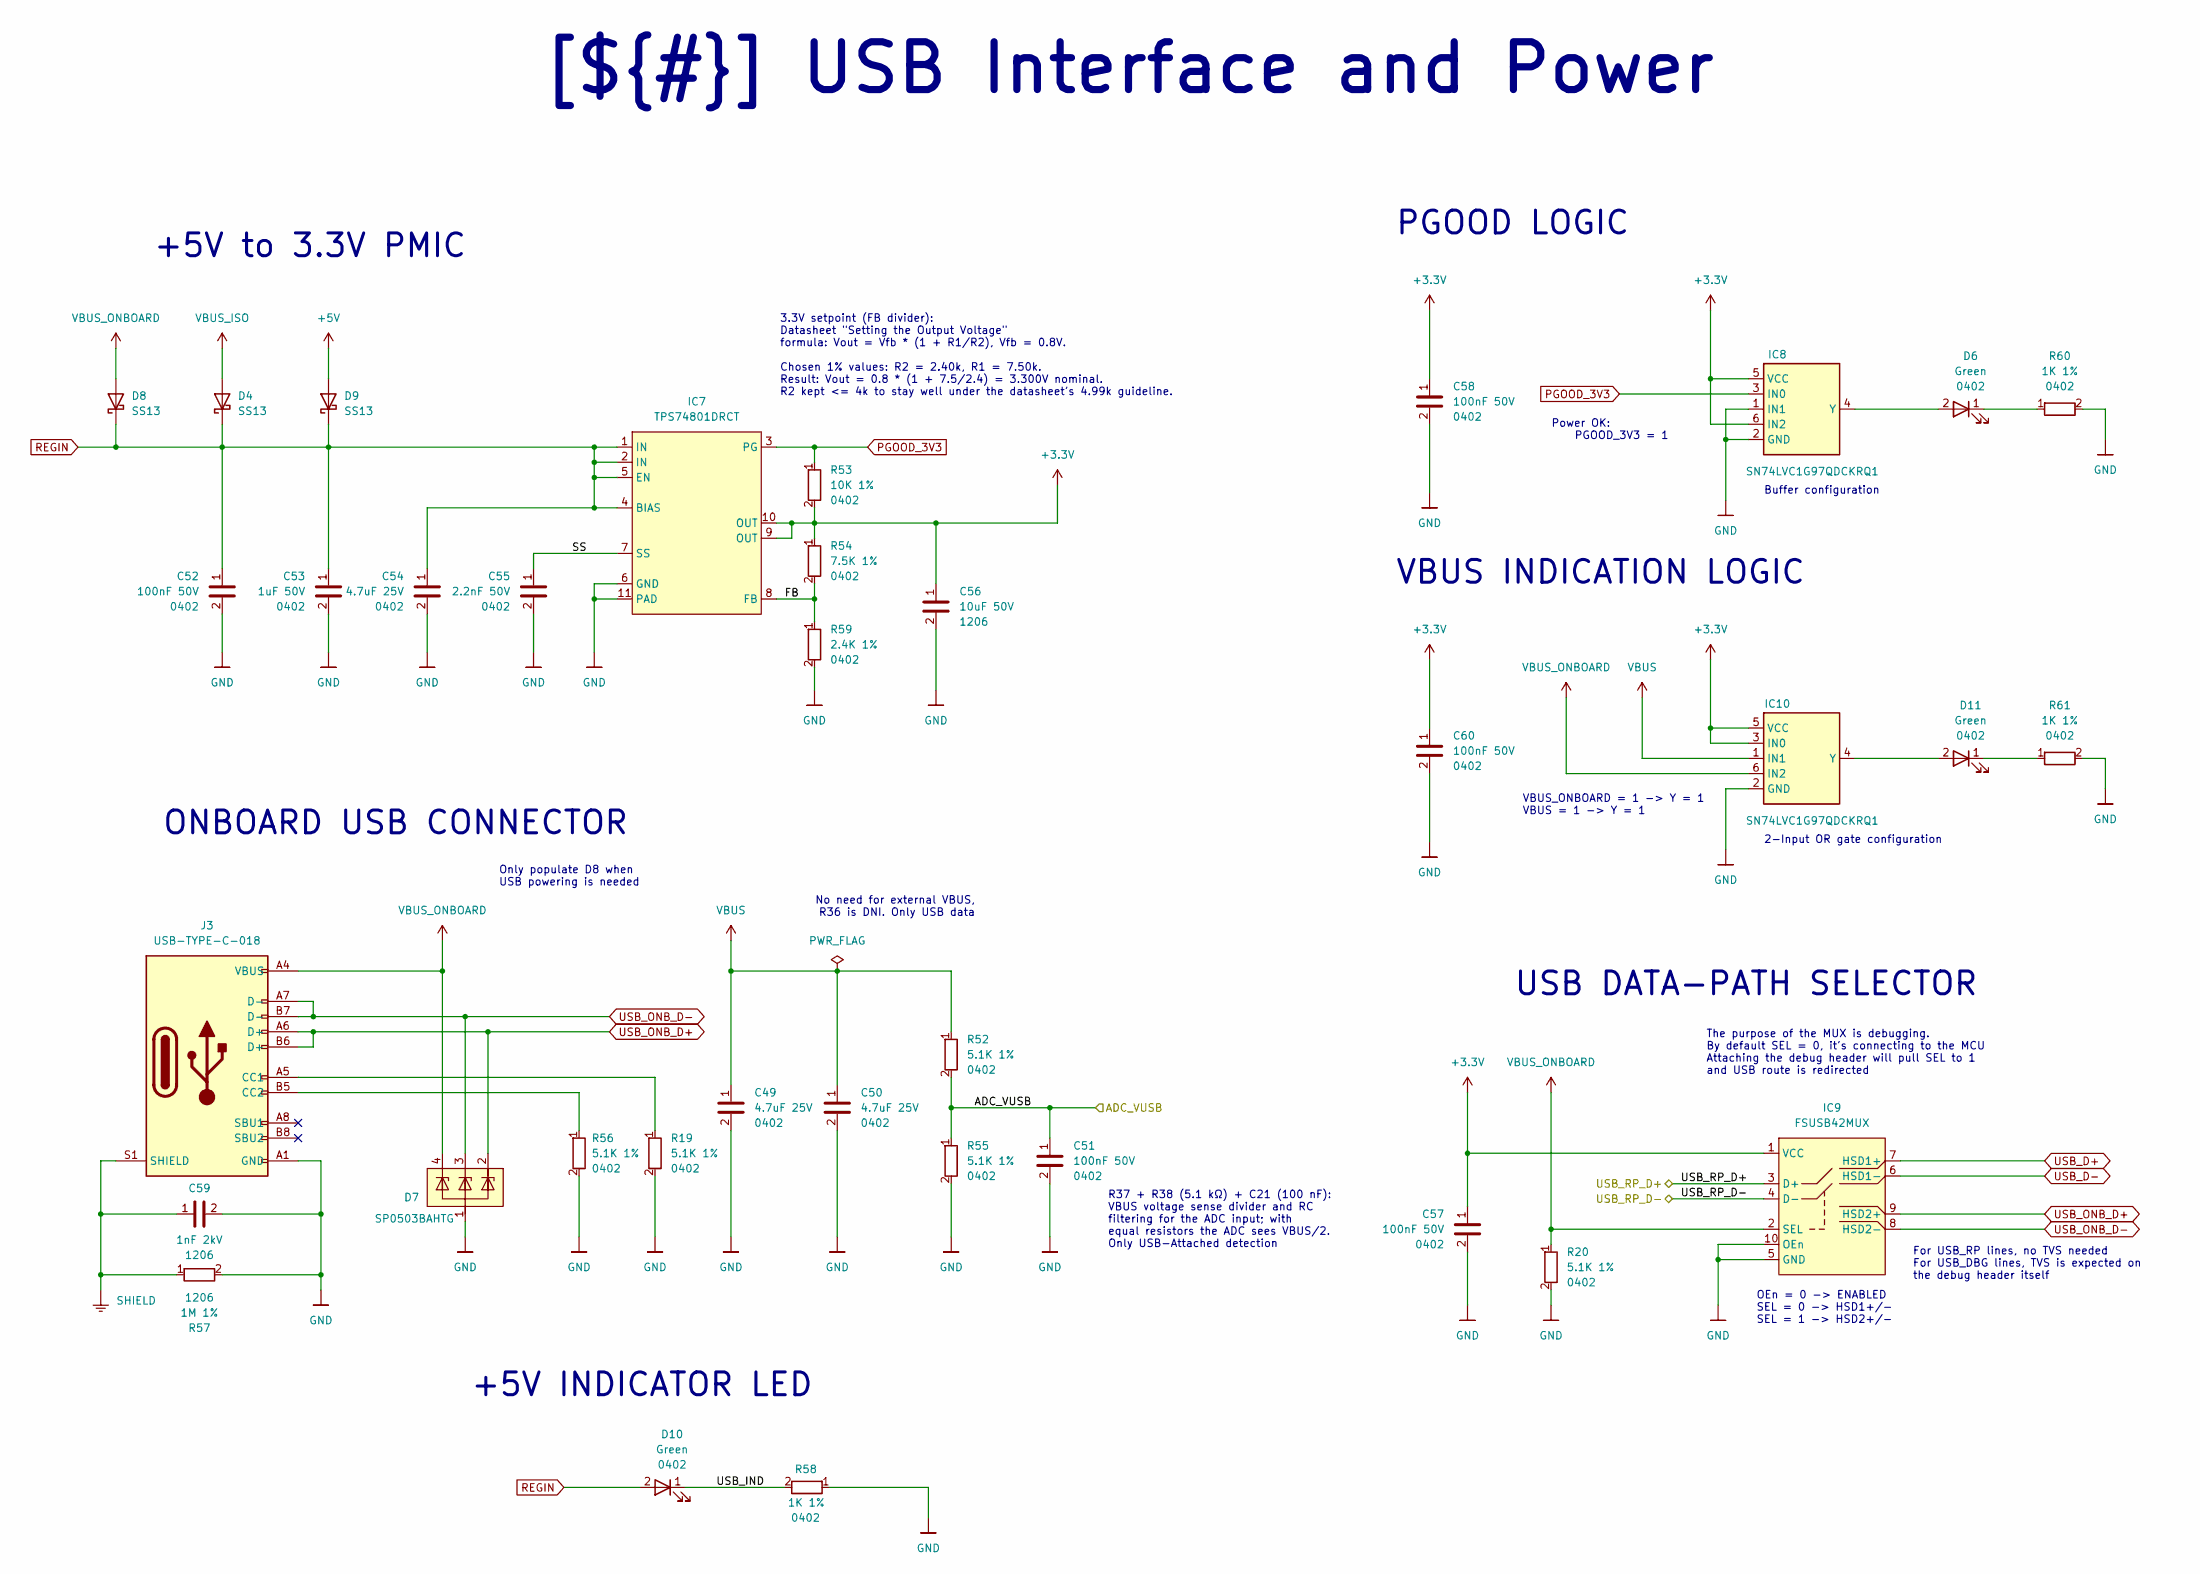
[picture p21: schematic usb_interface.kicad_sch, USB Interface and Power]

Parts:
C49, C50, C54: 4.7uF 25V; C_0402_1005Metric; MPN 04023D475MAT2A; LCSC_PART C22367824
C51, C52, C57, C58, C60: 100nF 50V; C_0402_1005Metric; MPN CGA2B3X7R1H104K050BB; LCSC_PART C307331
C53: 1uF 50V; C_0402_1005Metric; MPN GRM155R61H105KE05D; LCSC_PART C1518208
C55: 2.2nF 50V; C_0402_1005Metric; MPN CC0402KRX7R9BB222; LCSC_PART C106861
C56: 10uF 50V; C_1206_3216Metric; MPN CL31A106KBHNNNE; LCSC_PART C13585
C59: 1nF 2kV; C_1206_3216Metric; MPN C1206X102KGRACTU; LCSC_PART C173242
D4, D8, D9: SS13; D_SMA
D6, D10, D11: Green; LED_0402_1005Metric; MPN XL-1005UGC; LCSC_PART C965793
D7: SP0503BAHTG; SOT143; MPN SP0503BAHTG; LCSC_PART C3040626
IC7: TPS74801DRCT; VSON-10-1EP_3x3mm_P0.5mm_EP1.65x2.4mm_ThermalVias; MPN TPS74801DRCT; LCSC_PART C882845
IC8, IC10: SN74LVC1G97QDCKRQ1; SOT-363_SC-70-6; MPN SN74LVC1G97QDCKRQ1; LCSC_PART C179911
IC9: FSUSB42MUX; MSOP-10_3x3mm_P0.5mm; MPN FSUSB42MUX; LCSC_PART C11355
J3: USB-TYPE-C-018; USB_C_Receptacle_HCTL_HC-TYPE-C-16P-01A; MPN 10171746-00021LF; LCSC_PART C2927038
R19, R20, R52, R55, R56: 5.1K 1%; R_0402_1005Metric; MPN CRCW04025K10FKED; LCSC_PART C25905
R53: 10K 1%; R_0402_1005Metric; MPN CRCW040210K0FKED; LCSC_PART C25744
R54: 7.5K 1%; R_0402_1005Metric; MPN CRCW04027K50FKED; LCSC_PART C25918
R57: 1M 1%; R_1206_3216Metric; MPN CRCW12061M00FKEA; LCSC_PART C17927
R58, R60, R61: 1K 1%; R_0402_1005Metric; MPN CRCW04021K00FKED; LCSC_PART C11702
R59: 2.4K 1%; R_0402_1005Metric; MPN CRCW04022K40FKED; LCSC_PART C25882
SHIELD1: SHIELD

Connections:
+3.3V: C56.1, C57.1, C58.1, C60.1, IC7.9 (OUT), IC7.10 (OUT), IC8.5 (VCC), IC8.6 (IN2), IC9.1 (VCC), IC10.3 (IN0), IC10.5 (VCC), R53.2, R54.1; also elsewhere on the board
+5V: D9.2 (A); also elsewhere on the board
/Project Architecture/Microcontroller/ADC_VUSB: C51.1, R52.2, R55.1; also elsewhere on the board
/Project Architecture/USB Interface and Power/FB: IC7.8 (FB), R54.2, R59.1
/Project Architecture/USB Interface and Power/SS: C55.1, IC7.7 (SS)
/Project Architecture/USB Interface and Power/USB_IND: D10.1, R58.2
/Project Architecture/USB Interface and Power/USB_RP_D+: IC9.3 (D+); also elsewhere on the board
/Project Architecture/USB Interface and Power/USB_RP_D-: IC9.4 (D-); also elsewhere on the board
GND: C49.2, C50.2, C51.2, C52.2, C53.2, C54.2, C55.2, C56.2, C57.2, C58.2, C59.2, C60.2, D7.1, IC7.6 (GND), IC7.11 (PAD), IC8.1 (IN1), IC8.2 (GND), IC9.5 (GND), IC9.10 (OEn), IC10.2 (GND), J3.A1 (GND), J3.A12 (GND), J3.B1 (GND), J3.B12 (GND), R19.2, R20.2, R55.2, R56.2, R57.2, R58.1, R59.2, R60.2, R61.2; also elsewhere on the board
unnamed: D6.1, R60.1
unnamed: D11.1, R61.1
unnamed: D6.2, IC8.4 (Y)
unnamed: D11.2, IC10.4 (Y)
unnamed: J3.A5 (CC1), R19.1
unnamed: J3.B5 (CC2), R56.1
PGOOD_3V3: IC7.3 (PG), IC8.3 (IN0), R53.1
REGIN: C52.1, C53.1, C54.1, D4.1 (K), D8.1 (K), D9.1 (K), D10.2, IC7.1 (IN), IC7.2 (IN), IC7.4 (BIAS), IC7.5 (EN)
SHIELD: C59.1, J3.S1 (SHIELD), R57.1, SHIELD1.1
USB_D+: IC9.7 (HSD1+); also elsewhere on the board
USB_D-: IC9.6 (HSD1-); also elsewhere on the board
USB_ONB_D+: D7.2, IC9.9 (HSD2+), J3.A6 (D+), J3.B6 (D+)
USB_ONB_D-: D7.3, IC9.8 (HSD2-), J3.A7 (D-), J3.B7 (D-)
VBUS: C49.1, C50.1, IC10.1 (IN1), R52.1; also elsewhere on the board
VBUS_ISO: D4.2 (A); also elsewhere on the board
VBUS_ONBOARD: D7.4, D8.2 (A), IC9.2 (SEL), IC10.6 (IN2), J3.A4 (VBUS), J3.A9 (VBUS), J3.B4 (VBUS), J3.B9 (VBUS), R20.1

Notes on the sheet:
VBUS INDICATION LOGIC
OEn = 0 -> ENABLED SEL = 0 -> HSD1+/- SEL = 1 -> HSD2+/-
USB DATA-PATH SELECTOR
No need for external VBUS, R36 is DNI. Only USB data
2-Input OR gate configuration
+5V to 3.3V PMIC
+5V INDICATOR LED
3.3V setpoint (FB divider): Datasheet "Setting the Output Voltage" formula: Vout = Vfb * (1 + R1/R2), Vfb = 0.8V. Chosen 1% values: R2 = 2.40k, R1 = 7.50k. Result: Vout = 0.8 * (1 + 7.5/2.4) = 3.300V nominal. R2 kept <= 4k to stay well under the datasheet's 4.99k guideline.
ONBOARD USB CONNECTOR
For USB_RP lines, no TVS needed For USB_DBG lines, TVS is expected on the debug header itself
R37 + R38 (5.1 kΩ) + C21 (100 nF): VBUS voltage sense divider and RC filtering for the ADC input; with equal resistors the ADC sees VBUS/2. Only USB-Attached detection
VBUS_ONBOARD = 1 -> Y = 1 VBUS = 1 -> Y = 1
Power OK: PGOOD_3V3 = 1
Buffer configuration
PGOOD LOGIC
Only populate D8 when USB powering is needed
The purpose of the MUX is debugging. By default SEL = 0, it's connecting to the MCU Attaching the debug header will pull SEL to 1 and USB route is redirected
[${#}] ${TITLE}

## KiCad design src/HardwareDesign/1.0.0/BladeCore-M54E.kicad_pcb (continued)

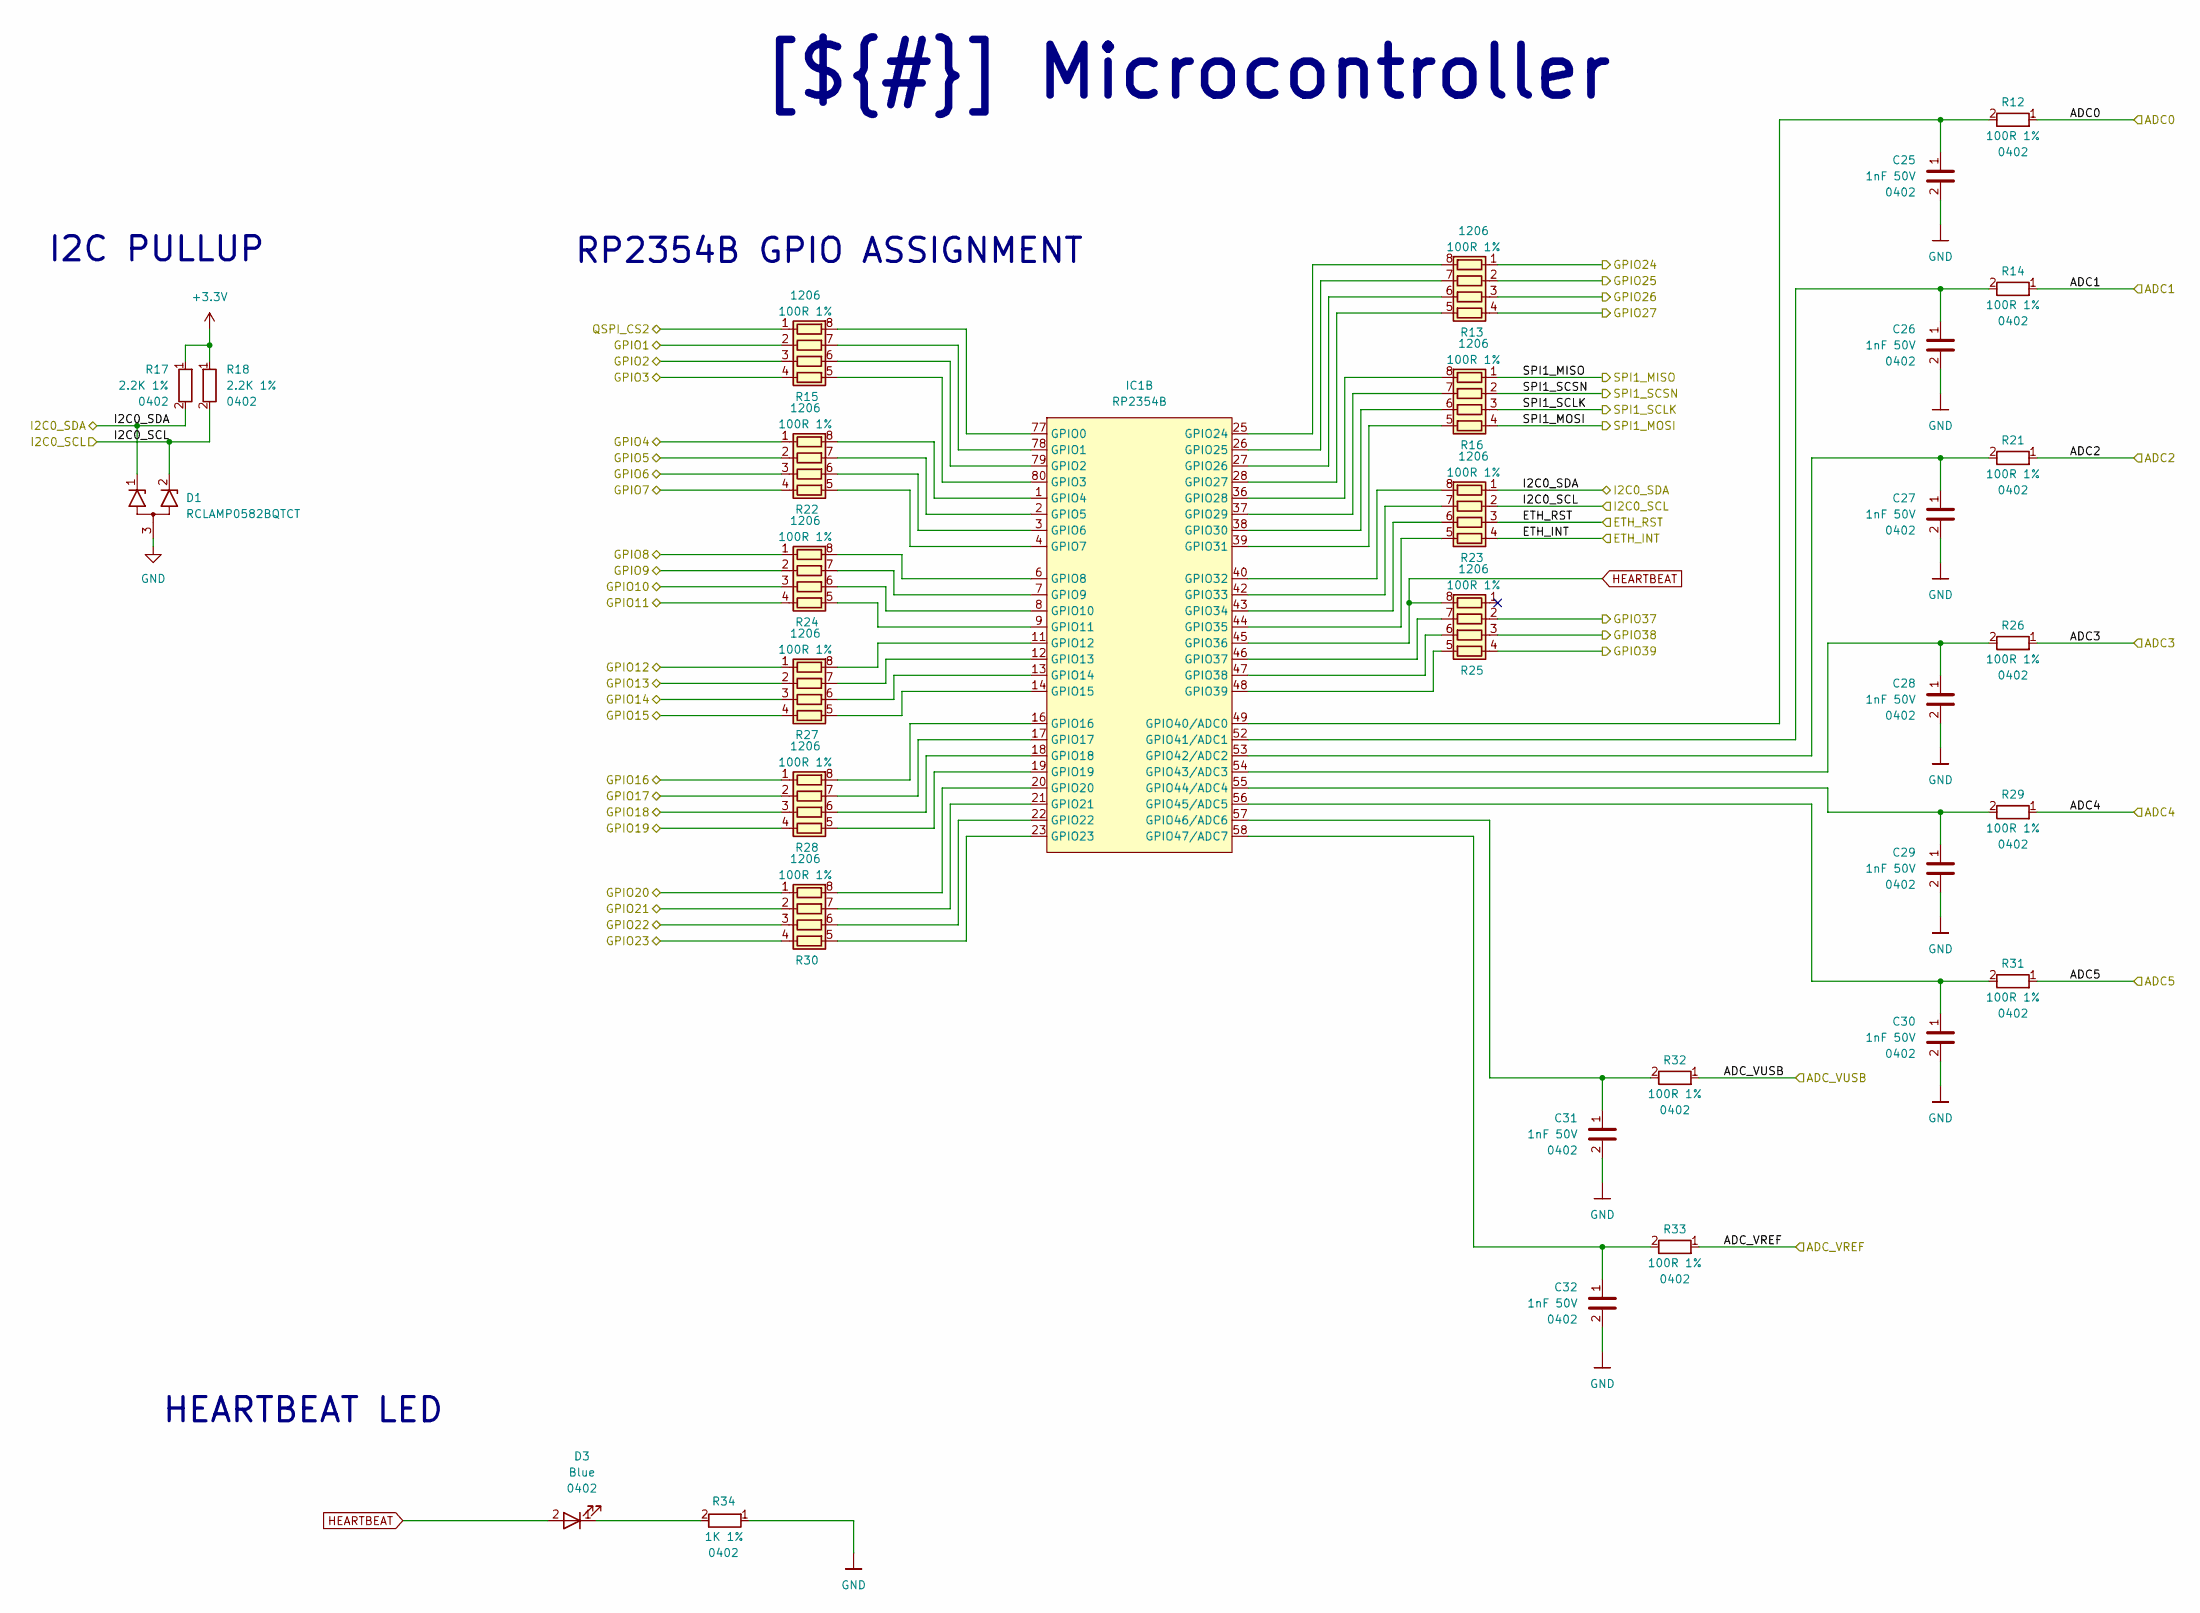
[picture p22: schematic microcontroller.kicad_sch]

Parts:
C25, C26, C27, C28, C29, C30, C31, C32: 1nF 50V; C_0402_1005Metric; MPN CL05B102KB5NNNC; LCSC_PART C14442
D1: RCLAMP0582BQTCT; SOT-416; MPN RCLAMP0582BQTCT; LCSC_PART C841193
D3: Blue; LED_0402_1005Metric; MPN QBLP595-2IB5; LCSC_PART C22355736
IC1: RP2354B; QFN80_10x10; MPN RP2354B; LCSC_PART C39843328
R12, R14, R21, R26, R29, R31, R32, R33: 100R 1%; R_0402_1005Metric; MPN CRCW0402100RFKED; LCSC_PART C25076
R13, R15, R16, R22, R23, R24, R25, R27, R28, R30: 100R 1%; R_Array_Convex_4x0603; MPN YC164-FR-07100RL; LCSC_PART C136838
R17, R18: 2.2K 1%; R_0402_1005Metric; MPN CRCW04022K20FKED; LCSC_PART C25879
R34: 1K 1%; R_0402_1005Metric; MPN CRCW04021K00FKED; LCSC_PART C11702

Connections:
+3.3V: R17.1, R18.1; also elsewhere on the board
/Project Architecture/ADC0: R12.1; also elsewhere on the board
/Project Architecture/ADC1: R14.1; also elsewhere on the board
/Project Architecture/ADC2: R21.1; also elsewhere on the board
/Project Architecture/ADC3: R26.1; also elsewhere on the board
/Project Architecture/ADC4: R29.1; also elsewhere on the board
/Project Architecture/ADC5: R31.1; also elsewhere on the board
/Project Architecture/Ethernet Interface/ETH_INT: R23.4 (R14); also elsewhere on the board
/Project Architecture/Ethernet Interface/ETH_RST: R23.3 (R13); also elsewhere on the board
/Project Architecture/Ethernet Interface/SPI1_MISO: R16.1 (R11); also elsewhere on the board
/Project Architecture/Ethernet Interface/SPI1_MOSI: R16.4 (R14); also elsewhere on the board
/Project Architecture/Ethernet Interface/SPI1_SCLK: R16.3 (R13); also elsewhere on the board
/Project Architecture/Ethernet Interface/SPI1_SCSN: R16.2 (R12); also elsewhere on the board
/Project Architecture/GPIO0: R15.1 (R11); also elsewhere on the board
/Project Architecture/GPIO1: R15.2 (R12); also elsewhere on the board
/Project Architecture/GPIO2: R15.3 (R13); also elsewhere on the board
/Project Architecture/GPIO3: R15.4 (R14); also elsewhere on the board
/Project Architecture/GPIO4: R22.1 (R11); also elsewhere on the board
/Project Architecture/GPIO5: R22.2 (R12); also elsewhere on the board
/Project Architecture/GPIO6: R22.3 (R13); also elsewhere on the board
/Project Architecture/GPIO7: R22.4 (R14); also elsewhere on the board
/Project Architecture/GPIO8: R24.1 (R11); also elsewhere on the board
/Project Architecture/GPIO9: R24.2 (R12); also elsewhere on the board
/Project Architecture/GPIO10: R24.3 (R13); also elsewhere on the board
/Project Architecture/GPIO11: R24.4 (R14); also elsewhere on the board
/Project Architecture/GPIO12: R27.1 (R11); also elsewhere on the board
/Project Architecture/GPIO13: R27.2 (R12); also elsewhere on the board
/Project Architecture/GPIO14: R27.3 (R13); also elsewhere on the board
/Project Architecture/GPIO15: R27.4 (R14); also elsewhere on the board
/Project Architecture/GPIO16: R28.1 (R11); also elsewhere on the board
/Project Architecture/GPIO17: R28.2 (R12); also elsewhere on the board
/Project Architecture/GPIO18: R28.3 (R13); also elsewhere on the board
/Project Architecture/GPIO19: R28.4 (R14); also elsewhere on the board
/Project Architecture/GPIO20: R30.1 (R11); also elsewhere on the board
/Project Architecture/GPIO21: R30.2 (R12); also elsewhere on the board
/Project Architecture/GPIO22: R30.3 (R13); also elsewhere on the board
/Project Architecture/GPIO23: R30.4 (R14); also elsewhere on the board
/Project Architecture/GPIO24: R13.1 (R11); also elsewhere on the board
/Project Architecture/GPIO25: R13.2 (R12); also elsewhere on the board
/Project Architecture/GPIO26: R13.3 (R13); also elsewhere on the board
/Project Architecture/GPIO27: R13.4 (R14); also elsewhere on the board
/Project Architecture/Microcontroller Peripherals/ADC_VREF: R33.1; also elsewhere on the board
/Project Architecture/Microcontroller Peripherals/I2C0_SCL: D1.2 (K2), R18.2, R23.2 (R12); also elsewhere on the board
/Project Architecture/Microcontroller Peripherals/I2C0_SDA: D1.1 (K1), R17.2, R23.1 (R11); also elsewhere on the board
/Project Architecture/Microcontroller/ADC_VUSB: R32.1; also elsewhere on the board
/Project Architecture/Microcontroller/GPIO37: R25.2 (R12)
/Project Architecture/Microcontroller/GPIO38: R25.3 (R13)
/Project Architecture/Microcontroller/GPIO39: R25.4 (R14)
GND: C25.2, C26.2, C27.2, C28.2, C29.2, C30.2, C31.2, C32.2, D1.3 (A), R34.1; also elsewhere on the board
HEARTBEAT: D3.2, IC1.45 (GPIO36), R25.8 (R12)
unnamed: D3.1, R34.2
unnamed: IC1.77 (GPIO0), R15.8 (R12)
unnamed: IC1.78 (GPIO1), R15.7 (R22)
unnamed: IC1.79 (GPIO2), R15.6 (R23)
unnamed: IC1.80 (GPIO3), R15.5 (R24)
unnamed: IC1.1 (GPIO4), R22.8 (R12)
unnamed: IC1.2 (GPIO5), R22.7 (R22)
unnamed: IC1.3 (GPIO6), R22.6 (R23)
unnamed: IC1.4 (GPIO7), R22.5 (R24)
unnamed: IC1.6 (GPIO8), R24.8 (R12)
unnamed: IC1.7 (GPIO9), R24.7 (R22)
unnamed: IC1.8 (GPIO10), R24.6 (R23)
unnamed: IC1.9 (GPIO11), R24.5 (R24)
unnamed: IC1.11 (GPIO12), R27.8 (R12)
unnamed: IC1.12 (GPIO13), R27.7 (R22)
unnamed: IC1.13 (GPIO14), R27.6 (R23)
unnamed: IC1.14 (GPIO15), R27.5 (R24)
unnamed: IC1.16 (GPIO16), R28.8 (R12)
unnamed: IC1.17 (GPIO17), R28.7 (R22)
unnamed: IC1.18 (GPIO18), R28.6 (R23)
unnamed: IC1.19 (GPIO19), R28.5 (R24)
unnamed: IC1.20 (GPIO20), R30.8 (R12)
unnamed: IC1.21 (GPIO21), R30.7 (R22)
unnamed: IC1.22 (GPIO22), R30.6 (R23)
unnamed: IC1.23 (GPIO23), R30.5 (R24)
unnamed: IC1.25 (GPIO24), R13.8 (R12)
unnamed: IC1.26 (GPIO25), R13.7 (R22)
unnamed: IC1.27 (GPIO26), R13.6 (R23)
unnamed: IC1.28 (GPIO27), R13.5 (R24)
unnamed: IC1.36 (GPIO28), R16.8 (R12)
unnamed: IC1.37 (GPIO29), R16.7 (R22)
unnamed: IC1.38 (GPIO30), R16.6 (R23)
unnamed: IC1.39 (GPIO31), R16.5 (R24)
unnamed: IC1.40 (GPIO32), R23.8 (R12)
unnamed: IC1.42 (GPIO33), R23.7 (R22)
unnamed: IC1.43 (GPIO34), R23.6 (R23)
unnamed: IC1.44 (GPIO35), R23.5 (R24)
unnamed: IC1.46 (GPIO37), R25.7 (R22)
unnamed: IC1.47 (GPIO38), R25.6 (R23)
unnamed: IC1.48 (GPIO39), R25.5 (R24)
unnamed: C25.1, IC1.49 (GPIO40/ADC0), R12.2
unnamed: C26.1, IC1.52 (GPIO41/ADC1), R14.2
unnamed: C27.1, IC1.53 (GPIO42/ADC2), R21.2
unnamed: C28.1, IC1.54 (GPIO43/ADC3), R26.2
unnamed: C29.1, IC1.55 (GPIO44/ADC4), R29.2
unnamed: C30.1, IC1.56 (GPIO45/ADC5), R31.2
unnamed: C31.1, IC1.57 (GPIO46/ADC6), R32.2
unnamed: C32.1, IC1.58 (GPIO47/ADC7), R33.2

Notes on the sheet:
I2C PULLUP
HEARTBEAT LED
RP2354B GPIO ASSIGNMENT
[${#}] ${TITLE}

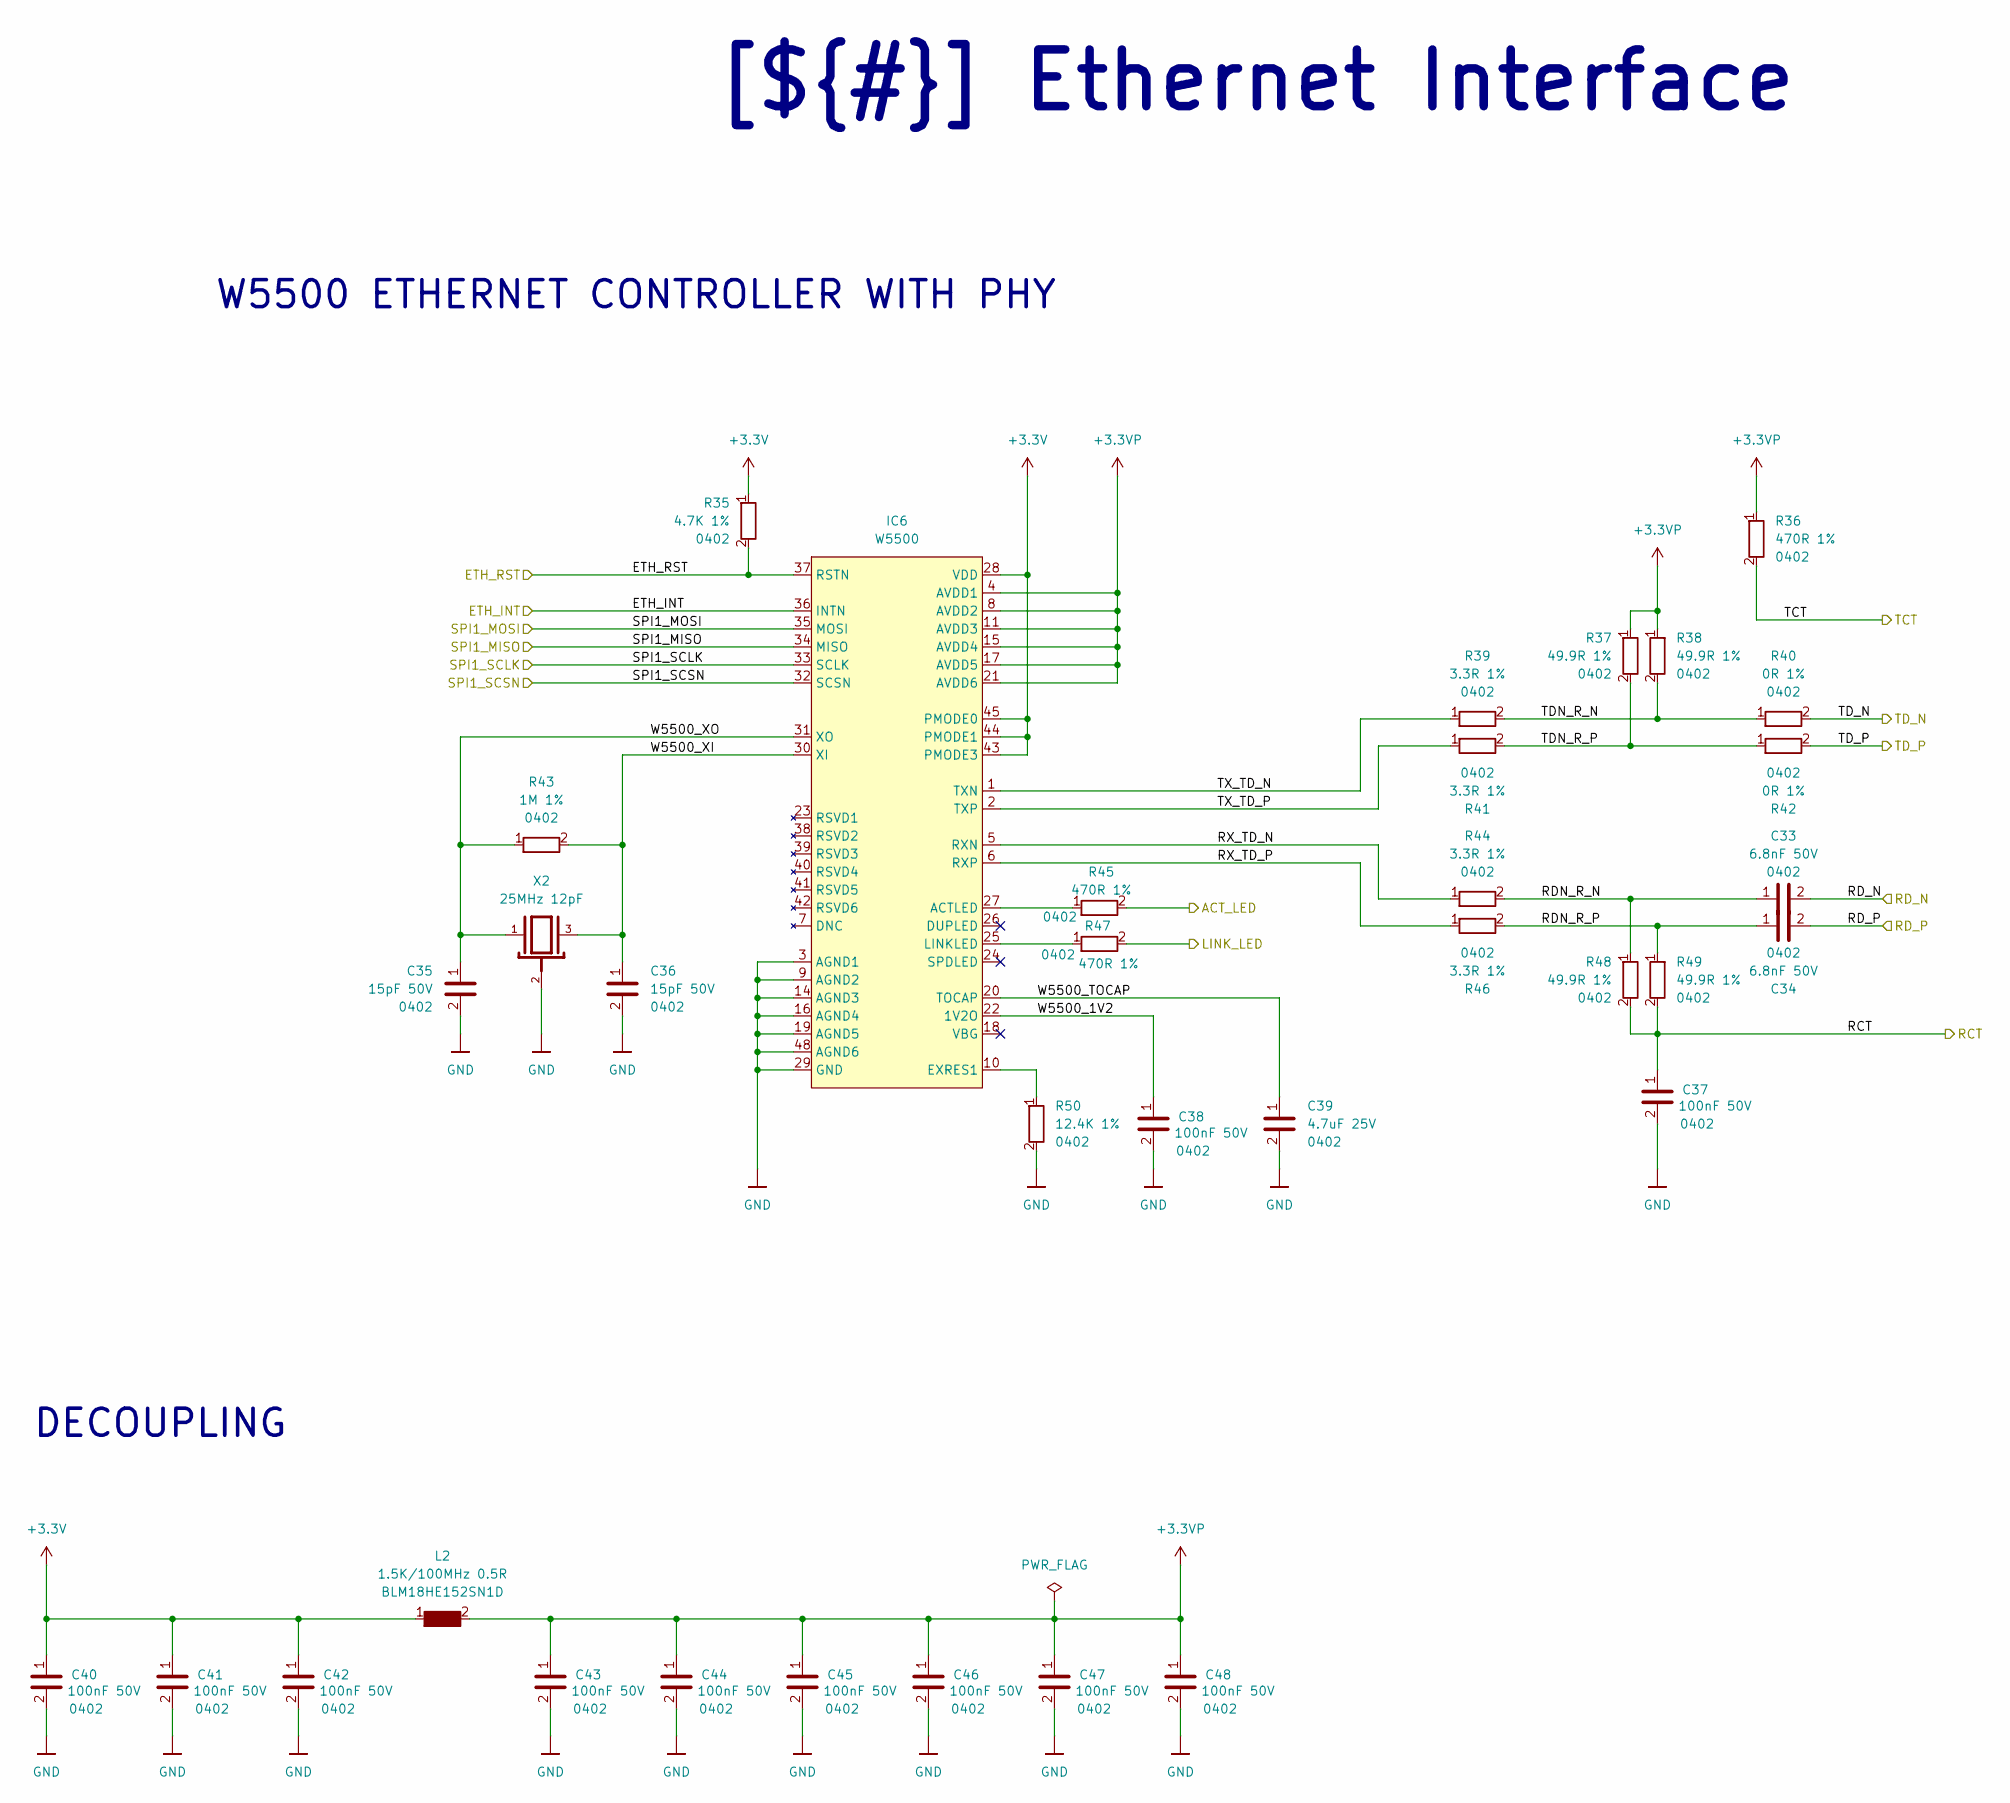
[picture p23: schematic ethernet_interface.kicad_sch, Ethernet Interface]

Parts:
C33, C34: 6.8nF 50V; C_0402_1005Metric; MPN C0402C682K5RACTU; LCSC_PART C1542
C35, C36: 15pF 50V; C_0402_1005Metric; MPN CC0402JRNPO9BN150; LCSC_PART C1548
C37, C38, C40, C41, C42, C43, C44, C45, C46, C47, C48: 100nF 50V; C_0402_1005Metric; MPN CGA2B3X7R1H104K050BB; LCSC_PART C307331
C39: 4.7uF 25V; C_0402_1005Metric; MPN 04023D475MAT2A; LCSC_PART C22367824
IC6: W5500; LQFP48_7x7; MPN W5500; LCSC_PART C32843
L2: 1.5K/100MHz 0.5R; R_0603_1608Metric; MPN BLM18HE152SN1D; LCSC_PART C82155
R35: 4.7K 1%; R_0402_1005Metric; MPN CRCW04024K70FKED; LCSC_PART C25900
R36, R45, R47: 470R 1%; R_0402_1005Metric; MPN CRCW0402470RFKED; LCSC_PART C25117
R37, R38, R48, R49: 49.9R 1%; R_0402_1005Metric; MPN CRCW040249R9FKED; LCSC_PART C25120
R39, R41, R44, R46: 3.3R 1%; R_0402_1005Metric; MPN CRCW04023R30FKED; LCSC_PART C270612
R40, R42: 0R 1%; R_0402_1005Metric; MPN RCA04020000ZSED; LCSC_PART C17168
R43: 1M 1%; R_0402_1005Metric; MPN CRCW04021M00FKED; LCSC_PART C26083
R50: 12.4K 1%; R_0402_1005Metric; MPN CRCW040212K4FKEDC; LCSC_PART C490814
X2: 25MHz 12pF; X3225; MPN ABM8AIG-25.000MHZ-12-2Z-T3; LCSC_PART C9006

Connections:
+3.3V: C40.1, C41.1, C42.1, IC6.28 (VDD), IC6.43 (PMODE3), IC6.44 (PMODE1), IC6.45 (PMODE0), L2.1, R35.1; also elsewhere on the board
+3.3VP: C43.1, C44.1, C45.1, C46.1, C47.1, C48.1, IC6.4 (AVDD1), IC6.8 (AVDD2), IC6.11 (AVDD3), IC6.15 (AVDD4), IC6.17 (AVDD5), IC6.21 (AVDD6), L2.2, R36.1, R37.1, R38.1
/Project Architecture/ACT_LED: R45.2; also elsewhere on the board
/Project Architecture/Ethernet Interface/ETH_INT: IC6.36 (INTN); also elsewhere on the board
/Project Architecture/Ethernet Interface/ETH_RST: IC6.37 (RSTN), R35.2; also elsewhere on the board
/Project Architecture/Ethernet Interface/RDN_R_N: C33.1, R44.2, R48.1
/Project Architecture/Ethernet Interface/RDN_R_P: C34.1, R46.2, R49.1
/Project Architecture/Ethernet Interface/RX_TD_N: IC6.5 (RXN), R44.1
/Project Architecture/Ethernet Interface/RX_TD_P: IC6.6 (RXP), R46.1
/Project Architecture/Ethernet Interface/SPI1_MISO: IC6.34 (MISO); also elsewhere on the board
/Project Architecture/Ethernet Interface/SPI1_MOSI: IC6.35 (MOSI); also elsewhere on the board
/Project Architecture/Ethernet Interface/SPI1_SCLK: IC6.33 (SCLK); also elsewhere on the board
/Project Architecture/Ethernet Interface/SPI1_SCSN: IC6.32 (SCSN); also elsewhere on the board
/Project Architecture/Ethernet Interface/TDN_R_N: R38.2, R39.2, R40.1
/Project Architecture/Ethernet Interface/TDN_R_P: R37.2, R41.2, R42.1
/Project Architecture/Ethernet Interface/TX_TD_N: IC6.1 (TXN), R39.1
/Project Architecture/Ethernet Interface/TX_TD_P: IC6.2 (TXP), R41.1
/Project Architecture/Ethernet Interface/W5500_1V2: C38.1, IC6.22 (1V2O)
/Project Architecture/Ethernet Interface/W5500_TOCAP: C39.1, IC6.20 (TOCAP)
/Project Architecture/Ethernet Interface/W5500_XI: C36.1, IC6.30 (XI), R43.2, X2.3
/Project Architecture/Ethernet Interface/W5500_XO: C35.1, IC6.31 (XO), R43.1, X2.1
/Project Architecture/LINK_LED: R47.2; also elsewhere on the board
/Project Architecture/RCT: C37.1, R48.2, R49.2; also elsewhere on the board
/Project Architecture/RD_N: C33.2; also elsewhere on the board
/Project Architecture/RD_P: C34.2; also elsewhere on the board
/Project Architecture/TCT: R36.2; also elsewhere on the board
/Project Architecture/TD_N: R40.2; also elsewhere on the board
/Project Architecture/TD_P: R42.2; also elsewhere on the board
GND: C35.2, C36.2, C37.2, C38.2, C39.2, C40.2, C41.2, C42.2, C43.2, C44.2, C45.2, C46.2, C47.2, C48.2, IC6.3 (AGND1), IC6.9 (AGND2), IC6.14 (AGND3), IC6.16 (AGND4), IC6.19 (AGND5), IC6.29 (GND), IC6.48 (AGND6), R50.2, X2.2; also elsewhere on the board
unnamed: IC6.27 (ACTLED), R45.1
unnamed: IC6.10 (EXRES1), R50.1
unnamed: IC6.25 (LINKLED), R47.1

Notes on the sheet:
DECOUPLING
W5500 ETHERNET CONTROLLER WITH PHY
[${#}] ${TITLE}

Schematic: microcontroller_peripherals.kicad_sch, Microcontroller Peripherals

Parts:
C1, C2, C3, C4, C5, C7, C8, C9, C10, C13, C14, C15, C17, C18, C19, C21, C23: 100nF 50V; C_0402_1005Metric; MPN CGA2B3X7R1H104K050BB; LCSC_PART C307331
C6, C16: 4.7uF 25V; C_0402_1005Metric; MPN 04023D475MAT2A; LCSC_PART C22367824
C11, C12: 10pF 50V; C_0402_1005Metric; MPN C0402H100J5GACT500; LCSC_PART C466222
C20, C22, C24: 4.7uF 10V; C_0402_1005Metric; MPN CL05A475KP5NRNC; LCSC_PART C368809
IC1: RP2354B; QFN80_10x10; MPN RP2354B; LCSC_PART C39843328
IC2: AT24C256C-XHL-T; TSSOP-8; MPN AT24C256C-XHL-T; LCSC_PART C33035
IC3: W25Q128JVPIQ; WSON8_6x5; MPN W25Q128JVPIQ; LCSC_PART C190862
IC4: MCP6001RT; SOT-23-5; MPN MCP6001RT-I/OT; LCSC_PART C154973
IC5: LM4040B30FTA; SOT-23; MPN LM4040B30FTA; LCSC_PART C460604
J2: SM03B-SRSS-TB; JST_SM03B-SRSS-TB_LF__SN_; MPN SM03B-SRSS-TB; LCSC_PART C160403
L1: 3.3uH 2.8A; 0805; MPN AOTA-B201610S3R3-101-T; LCSC_PART C42411119
R1, R8: 4.7K 1%; R_0402_1005Metric; MPN CRCW04024K70FKED; LCSC_PART C25900
R2, R3, R4: 33R 1%; R_0402_1005Metric; MPN CRCW040233R0FKED; LCSC_PART C25105
R5: 1K 1%; R_0402_1005Metric; MPN CRCW04021K00FKED; LCSC_PART C11702
R6: 1K 1%; R_0402_1005Metric; MPN CRCW04021K00FKED; LCSC_PART C11702; not fitted
R7: 27R 1%; R_0402_1005Metric; MPN CRCW040227R0FKED; LCSC_PART C138021
R9: 27R 1%; R_0402_1005Metric; MPN CRCW040227R0FKED; LCSC_PART C138021; not fitted
R10, R11: 10K 1%; R_0402_1005Metric; MPN CRCW040210K0FKED; LCSC_PART C25744
SW1, SW2: B3U-1000P; SW_B3U-1000P; MPN B3U-1000P; LCSC_PART C231329
X1: 12MHz 10pF; X3225; MPN ABM8G-12.000MHZ-B4Y-T; LCSC_PART C2901649

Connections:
+1V1: C13.1, C14.1, C15.1, C16.1, IC1.10 (DVDD1), IC1.32 (DVDD2), IC1.51 (DVDD3), IC1.65 (VREF_FB), L1.1
+3.3V: C1.1, C2.1, C3.1, C4.1, C5.1, C7.1, C8.1, C9.1, C10.1, C17.1, C18.1, C20.1, IC1.5 (IOVDD1), IC1.15 (IOVDD2), IC1.24 (IOVDD3), IC1.29 (IOVDD4), IC1.41 (IOVDD5), IC1.50 (IOVDD6), IC1.60 (IOVDD7), IC1.64 (VREG_IN), IC1.68 (USB_OTP_VDD), IC1.69 (QSPI_IOVDD), IC1.76 (IOVDD8), IC2.8 (VCC), IC3.8 (VCC), R1.1, R2.1, R6.1, R7.2, R8.1, R9.2; also elsewhere on the board
/Project Architecture/Microcontroller Peripherals/ADC_VREF: R10.2, R11.1; also elsewhere on the board
/Project Architecture/Microcontroller Peripherals/I2C0_SCL: IC2.6 (SCL); also elsewhere on the board
/Project Architecture/Microcontroller Peripherals/I2C0_SDA: IC2.5 (SDA); also elsewhere on the board
/Project Architecture/Microcontroller Peripherals/RP_D+: IC1.67 (USB_DP), R4.2
/Project Architecture/Microcontroller Peripherals/RP_D-: IC1.66 (USB_DM), R3.1
/Project Architecture/Microcontroller Peripherals/SWCLK: IC1.33 (SWCLK), J2.3 (SWDAT)
/Project Architecture/Microcontroller Peripherals/SWDIO: IC1.34 (SWDIO), J2.1 (SWCLK)
/Project Architecture/Microcontroller Peripherals/VREF_IN: C21.1, C22.1, IC4.3 (+), IC5.1 (K), R8.2
/Project Architecture/Microcontroller Peripherals/VREG_AVDD: C6.1, IC1.61 (VREG_AVDD), R2.2
/Project Architecture/Microcontroller Peripherals/VREG_LX: IC1.63 (VREG_LC), L1.2
/Project Architecture/Microcontroller Peripherals/XIN: C12.1, IC1.30 (XIN), X1.3
/Project Architecture/Microcontroller Peripherals/XO: C11.1, R5.2, X1.1
/Project Architecture/Microcontroller Peripherals/XOUT: IC1.31 (XOUT), R5.1
/Project Architecture/USB Interface and Power/USB_RP_D+: R4.1; also elsewhere on the board
/Project Architecture/USB Interface and Power/USB_RP_D-: R3.2; also elsewhere on the board
GND: C1.2, C2.2, C3.2, C4.2, C5.2, C6.2, C7.2, C8.2, C9.2, C10.2, C11.2, C12.2, C13.2, C14.2, C15.2, C16.2, C17.2, C18.2, C19.2, C20.2, C21.2, C22.2, C23.2, C24.2, IC1.62 (VREG_PGND), IC1.81 (GND), IC2.1 (A0), IC2.2 (A1), IC2.3 (A2), IC2.4 (GND), IC2.7 (WP), IC3.4 (GND), IC3.9 (PAD), IC4.5 (V-), IC5.2 (A), J2.2 (GND), J2.S1 (SHIELD), J2.S2 (SHIELD), R11.2, SW1.2, SW2.2, X1.2; also elsewhere on the board
unnamed: C19.1, IC4.2 (V+), R7.1
QSPI_SCLK: IC1.71 (QSPI_SCLK), IC3.6 (CLK)
QSPI_SD0: IC1.72 (QSPI_SD0), IC3.5 (DI(IO0))
QSPI_SD1: IC1.74 (QSPI_SD1), IC3.2 (DO(IO1))
QSPI_SD2: IC1.73 (QSPI_SD2), IC3.3 (nWP(IO2))
QSPI_SD3: IC1.70 (QSPI_SD3), IC3.7 (nRST(IO3))
QSPI_SS: IC1.75 (QSPI_SS), IC3.1 (nCS), R6.2, SW1.1
RESET: IC1.35 (RUN), R1.2, SW2.1
VREF_OUT: C23.1, C24.1, IC1.59 (ADC_AVDD), IC4.1, IC4.4 (-), R9.1, R10.1

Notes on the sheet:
EXTERNAL EEPROM
PUSHBUTTONS
EXTERNAL FLASH
RP2354B MICROCONTROLLER
HW Design Guide: RC filter of 33Ω and 4.7μF is adequate
HW Design Guide: recommended to use 100nF capacitor per power pin
3.0V ADC VOLTAGE REFERENCE
12MHz 10pF -> Assuming 5pF parasitics Csum = 10pF - 5pF = 5pF C1 = C2 = 5pF x 2 = 10pF
[${#}] ${TITLE}

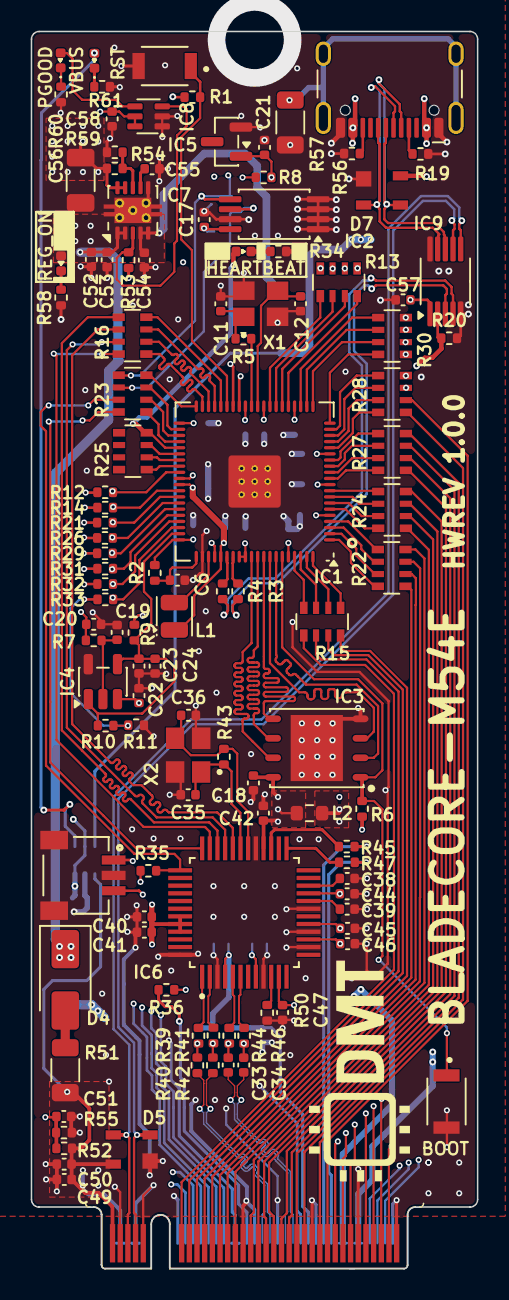
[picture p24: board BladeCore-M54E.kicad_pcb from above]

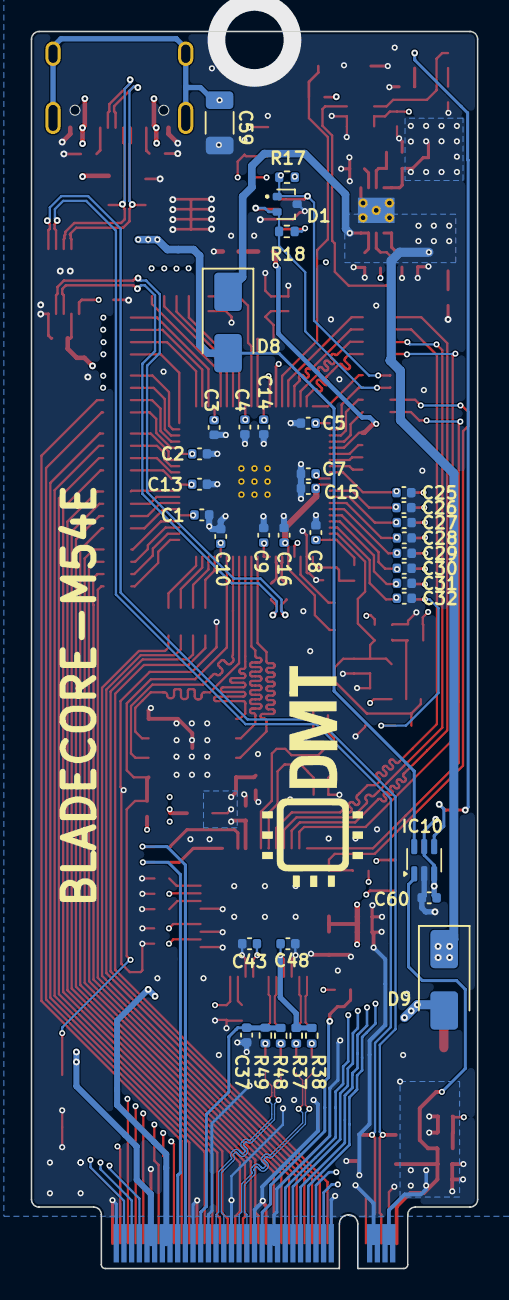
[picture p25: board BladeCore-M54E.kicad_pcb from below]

Board: 6 copper layers, 29.0 x 80.6 mm, 150 parts (36 on the bottom side), 161 nets.

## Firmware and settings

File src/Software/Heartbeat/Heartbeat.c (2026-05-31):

/*
 * Heartbeat.c - BladeCore-M54E Heartbeat LED (PWM fade in/out)
 *
 * Smoothly fades the onboard blue heartbeat LED on GPIO36 using
 * hardware PWM.  Brightness ramps linearly from off to 100% duty
 * and back for a clean, visible breathing effect.
 */

#include <stdio.h>
#include "pico/stdlib.h"
#include "hardware/pwm.h"
#include "hardware/clocks.h"
#include "hardware/i2c.h"
#include "CONFIG.h"

/* PWM wrap value -- higher gives finer brightness resolution */
#define PWM_WRAP 65535
#define FADE_STEPS 128

static void heartbeat_pwm_init(void)
{
    gpio_set_function(PIN_HEARTBEAT, GPIO_FUNC_PWM);

    uint slice = pwm_gpio_to_slice_num(PIN_HEARTBEAT);
    uint channel = pwm_gpio_to_channel(PIN_HEARTBEAT);

    pwm_config cfg = pwm_get_default_config();

    float divider = (float)clock_get_hz(clk_sys) /
                    ((float)HEARTBEAT_PWM_FREQ_HZ * (PWM_WRAP + 1));
    if (divider < 1.0f)
        divider = 1.0f;

    pwm_config_set_clkdiv(&cfg, divider);
    pwm_config_set_wrap(&cfg, PWM_WRAP);

    pwm_init(slice, &cfg, true);
    pwm_set_chan_level(slice, channel, 0);
}

static inline void heartbeat_set_brightness(uint16_t level)
{
    uint slice = pwm_gpio_to_slice_num(PIN_HEARTBEAT);
    uint channel = pwm_gpio_to_channel(PIN_HEARTBEAT);
    pwm_set_chan_level(slice, channel, level);
}

/* Write a single byte to an MCP23017 register.  Returns true on success. */
static bool mcp23017_write_reg(uint8_t reg, uint8_t val)
{
    uint8_t buf[2] = {reg, val};
    int ret = i2c_write_blocking(MCP23017_I2C_INSTANCE,
                                 MCP23017_I2C_ADDR,
                                 buf, 2, false);
    return (ret == 2);
}

/* Reset and initialise the MCP23017.  Returns true if the device responds. */
static bool mcp23017_init(void)
{
    /* Hardware reset (active low) */
    gpio_init(PIN_MCP23017_RST);
    gpio_set_dir(PIN_MCP23017_RST, GPIO_OUT);
    gpio_put(PIN_MCP23017_RST, 0);
    sleep_ms(1);
    gpio_put(PIN_MCP23017_RST, 1);
    sleep_ms(1);

    /* Configure I2C1 pins */
    i2c_init(MCP23017_I2C_INSTANCE, MCP23017_I2C_BAUDRATE);
    gpio_set_function(PIN_I2C1_SDA, GPIO_FUNC_I2C);
    gpio_set_function(PIN_I2C1_SCL, GPIO_FUNC_I2C);
    gpio_pull_up(PIN_I2C1_SDA);
    gpio_pull_up(PIN_I2C1_SCL);

    /*
     * GPA1, GPA3, GPA5, GPA7 -> output high
     * IODIRA: 0 = output, 1 = input (default 0xFF)
     *   bits 1,3,5,7 cleared -> 0x55
     * OLATA:  bits 1,3,5,7 set   -> 0xAA
     */
    if (!mcp23017_write_reg(MCP23017_REG_OLATA, 0xAA))
        return false;
    if (!mcp23017_write_reg(MCP23017_REG_IODIRA, 0x55))
        return false;

    return true;
}

int main(void)
{
    stdio_init_all();
    heartbeat_pwm_init();

    gpio_init(PIN_5V_BUCK_EN);
    gpio_set_dir(PIN_5V_BUCK_EN, GPIO_OUT);
    gpio_put(PIN_5V_BUCK_EN, 1);

    mcp23017_init();

    /*
     * Simple fade in / fade out:
     *   step 0 -> 127  = off to full brightness  (fade in)
     *   step 127 -> 0  = full brightness to off  (fade out)
     *   Cycle time ~ 128 * 2 * 8 ms = ~2.0 s
     */
    int step = 0;
    int direction = 1;

    while (true)
    {
        /* Linear ramp: step/127 * PWM_WRAP */
        uint32_t brightness = ((uint32_t)step * PWM_WRAP) / (FADE_STEPS - 1);
        heartbeat_set_brightness((uint16_t)brightness);

        sleep_ms(HEARTBEAT_FADE_STEP_MS);

        step += direction;
        if (step >= FADE_STEPS)
        {
            step = FADE_STEPS - 1;
            direction = -1;
        }
        else if (step < 0)
        {
            step = 0;
            direction = 1;
        }
    }
}

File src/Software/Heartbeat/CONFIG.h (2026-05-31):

/*
 * CONFIG.h - BladeCore-M54E Board Pin Configuration
 *
 * Pin assignments derived from the BladeCore-M54E hardware schematics (v1.0.0).
 * MCU: RP2354B (QFN-80)
 */

#ifndef CONFIG_H
#define CONFIG_H

/* -------------------------------------------------------------------------- */
/*  W5500 Ethernet (SPI1)                                                     */
/* -------------------------------------------------------------------------- */
#define PIN_ETH_MISO 28 /* SPI1 RX  - W5500 MISO             */
#define PIN_ETH_CS 29   /* SPI1 CSn - W5500 SCSn             */
#define PIN_ETH_SCK 30  /* SPI1 SCK - W5500 SCLK            */
#define PIN_ETH_MOSI 31 /* SPI1 TX  - W5500 MOSI            */

/* -------------------------------------------------------------------------- */
/*  I2C0 - Onboard EEPROM (AT24C256) + M.2 connector                         */
/* -------------------------------------------------------------------------- */
#define PIN_I2C0_SDA 32 /* I2C0 data  (4.7K pull-up)         */
#define PIN_I2C0_SCL 33 /* I2C0 clock (4.7K pull-up)         */

/* -------------------------------------------------------------------------- */
/*  W5500 Ethernet Control                                                    */
/* -------------------------------------------------------------------------- */
#define PIN_ETH_RST 34 /* W5500 hardware reset              */
#define PIN_ETH_INT 35 /* W5500 interrupt (active low)      */

/* -------------------------------------------------------------------------- */
/*  Onboard Heartbeat LED                                                     */
/* -------------------------------------------------------------------------- */
#define PIN_HEARTBEAT 36 /* Blue LED, 100R series resistor    */

/* -------------------------------------------------------------------------- */
/*  ADC - Onboard                                                             */
/* -------------------------------------------------------------------------- */
#define PIN_ADC_VUSB 46 /* GPIO46/ADC6 - USB VBUS sense (5.1K-5.1K divider) */
#define PIN_ADC_VREF 47 /* GPIO47/ADC7 - 3.00V 0.1% ref (10K-10K divider)   */

/* -------------------------------------------------------------------------- */
/*  Unused GPIOs - M.2 Connector (directly accent through M.2 edge connector) */
/* -------------------------------------------------------------------------- */
// #define PIN_GPIO0             0       /* M.2 pin 57 - Unused */
// #define PIN_GPIO1             1       /* M.2 pin 55 - Unused */
#define PIN_I2C1_SDA 2 /* M.2 pin 53 - I2C1 data  (MCP23017) */
#define PIN_I2C1_SCL 3 /* M.2 pin 51 - I2C1 clock (MCP23017) */
// #define PIN_GPIO4             4       /* M.2 pin 49 - Unused */
// #define PIN_GPIO5             5       /* M.2 pin 47 - Unused */
// #define PIN_GPIO6             6       /* M.2 pin 45 - Unused */
// #define PIN_GPIO7             7       /* M.2 pin 43 - Unused */
// #define PIN_GPIO8             8       /* M.2 pin 39 - Unused */
// #define PIN_GPIO9             9       /* M.2 pin 37 - Unused */
// #define PIN_GPIO10            10      /* M.2 pin 35 - Unused */
// #define PIN_GPIO11            11      /* M.2 pin 33 - Unused */
// #define PIN_GPIO12            12      /* M.2 pin 31 - Unused */
// #define PIN_GPIO13            13      /* M.2 pin 29 - Unused */
// #define PIN_GPIO14            14      /* M.2 pin 27 - Unused */
// #define PIN_GPIO15            15      /* M.2 pin 25 - Unused */
#define PIN_5V_BUCK_EN 16 /* M.2 pin 21 - Unused */
// #define PIN_GPIO17            17      /* M.2 pin 19 - Unused */
// #define PIN_GPIO18            18      /* M.2 pin 17 - Unused */
// #define PIN_GPIO19            19      /* M.2 pin 15 - Unused */
// #define PIN_GPIO20            20      /* M.2 pin 13 - Unused */
// #define PIN_GPIO21            21      /* M.2 pin 9  - Unused */
// #define PIN_GPIO22            22      /* M.2 pin 7  - Unused */
// #define PIN_GPIO23            23      /* M.2 pin 5  - Unused */
// #define PIN_GPIO24            24      /* M.2 pin 3  - Unused */
#define PIN_MCP23017_RST 25 /* M.2 pin 8  - MCP23017 reset (active low) */
// #define PIN_GPIO26            26      /* M.2 pin 6  - Unused */
// #define PIN_GPIO27            27      /* M.2 pin 4  - Unused */

/* GPIO37, GPIO38, GPIO39 are NOT connected on BladeCore-M54E */
#ifdef PIN_GPIO37
#error "GPIO37 is not connected on BladeCore-M54E"
#endif
#ifdef PIN_GPIO38
#error "GPIO38 is not connected on BladeCore-M54E"
#endif
#ifdef PIN_GPIO39
#error "GPIO39 is not connected on BladeCore-M54E"
#endif
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

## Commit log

2026-02-18 BladeCore‑M54E initial creation
    [BOM-BladeCore-M54.csv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]
2026-02-18 update files
    [BOM-BladeCore-M54.csv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]
2026-03-19 update design
    [BOM-BladeCore-M54E.csv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]
2026-03-19 add basic software
    [BladeCore-M54E.kicad_pcb, microcontroller.kicad_sch]
2026-03-20 Export Schematic PDF
2026-03-21 update footprint
    [Project Architecture.kicad_sch, ethernet_interface.kicad_sch, microcontroller.kicad_sch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]
2026-03-21 export gerbers
    [BOM-BladeCore-M54E.csv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]
2026-05-31 update documentation
    [BOM-BladeCore-M54E.csv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]
